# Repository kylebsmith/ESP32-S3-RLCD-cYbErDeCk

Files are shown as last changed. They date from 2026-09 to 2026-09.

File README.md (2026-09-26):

# cYbErDeCk

A single-form, overbuilt, minimum-footprint handheld terminal enclosure for the
**Waveshare ESP32-S3-RLCD-4.2** and a **Rii 518BT** mini Bluetooth keyboard.

Built for live use — musical live coding, control surfaces, and as a portable
node on a local network — rather than for a desk.

Dieter Rams read organically: one radius system, nothing applied, a single
perforated element — but with curvature continuity everywhere a surface turns,
so it reads as grown rather than extruded.



<p align="center">
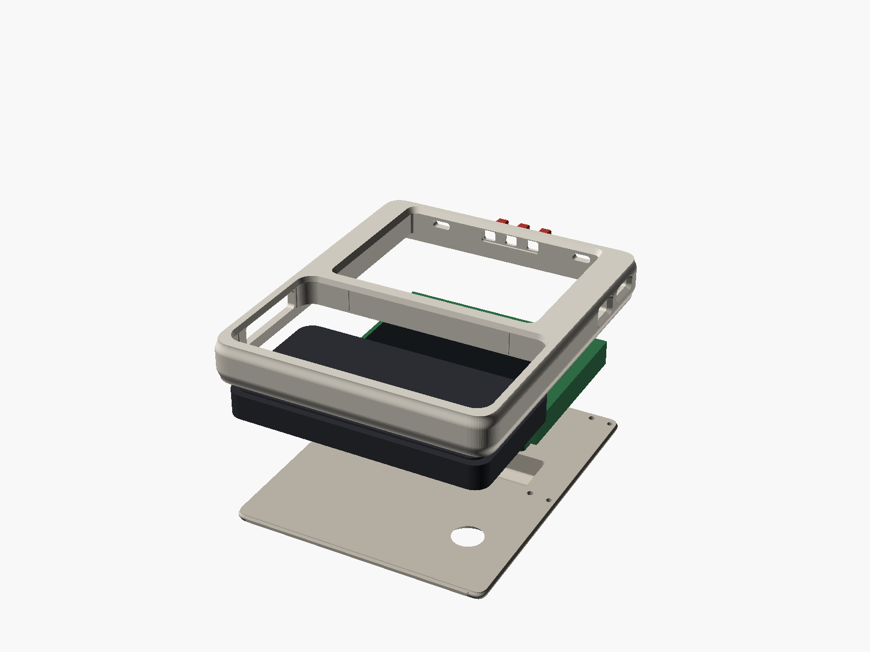
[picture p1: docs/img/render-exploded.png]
Exploded assembly
  
</p>
<p align="center">
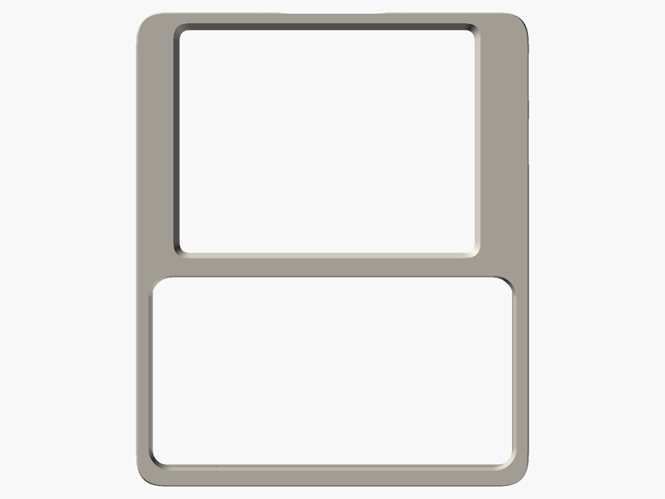
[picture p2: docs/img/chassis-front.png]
Chassis, front
  
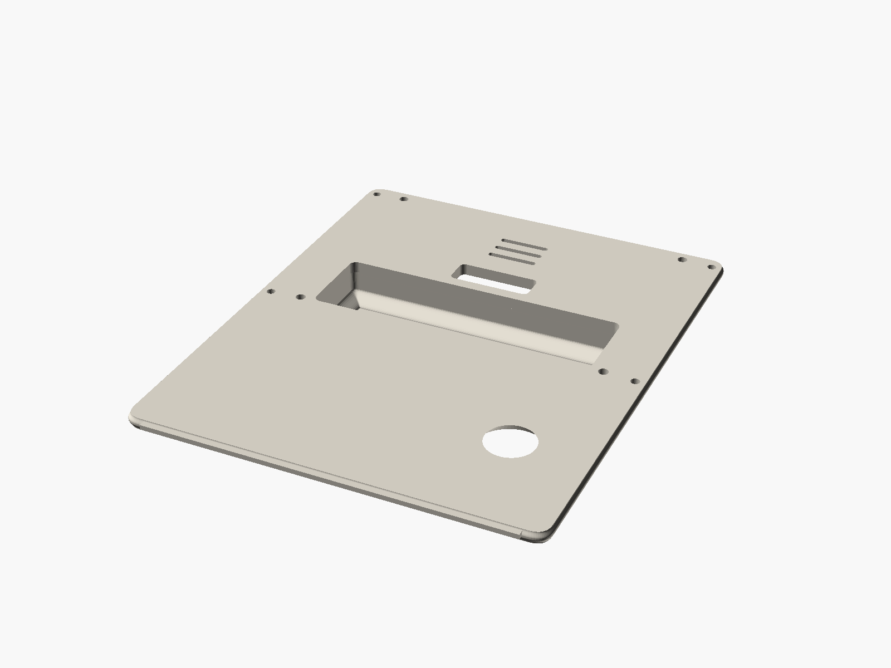
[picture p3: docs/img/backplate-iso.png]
Back plate
  
</p>

```
116.25 × 138.85 × 16.85 mm   (+ 10.0 mm battery cowl)
3 printed parts + a cover · 8 screws · 8 magnets · 119 automated checks
```

---

## What it is

Two rigid rectangles have to sit side by side, so most of the size of this thing
is arithmetic, not taste:

```
width  = wall + max(keyboard 109.85, board 93.5) + wall
height = wall + keyboard 59.15 + spine + board 70.1 + wall
depth  = back plate + board stack 11.0 + front face
```

`tools/validate.py` asserts each of those three equalities on every run. **The
enclosure cannot be made smaller without thinning a wall or crushing a part.**

What *is* a design choice is that it reads as one object, and that every corner
on it is continuous in curvature rather than merely tangent. A conventional
fillet is an arc meeting a line: the curvature jumps from 1/r to zero and the
eye reads a hard corner however large the radius. Every visible corner here is a
superelliptical quadrant of a larger corner size, tracking the same silhouette
while ramping curvature in from zero. Edges roll into the faces with zero slope
instead of being chamfered, and the battery swelling is blended out of the back
panel with a tangent foot, so it has no base line at all.

The entire front face, all four side walls and the inter-bay spine are a single
continuous body; the joint moves to the back, where a structural plate closes
the shell into a torsion box. There is no bezel line across the face you touch.

Where the language breaks it says so. The display aperture's corner is 4.2 mm
where everything else is 9 to 11.2, because the aperture height is trapped
between the active area it must not clip and the module edge it must still bear
on — the panel sets that corner, not taste, and the bound is asserted in CI.

| | Reference design | This design |
|---|---|---|
| Envelope | 151.65 × 116.77 × 18.00 | **116.25 × 138.85 × 16.85** |
| Battery bulge | +12.0 mm, separate clip-on cover | +10.0 mm, integral grip ridge |
| Wall | 2.90 mm | **3.20 mm** (8 extrusions, solid perimeters) |
| Split | bezel screwed onto a tray | monocoque front, joint at the back |
| Footprint area | 17 708 mm² | **16 218 mm² (−8.4 %)** |

12.55 mm shorter, 1.15 mm thinner, *and* thicker-walled.

## The instrument

The firmware turns the board into a handheld live-coding instrument. One line of
text is one lane, and a lane is the only noun in the system — a kick, a
bassline, a filter sweep and an ASCII frame are the same object, and what
differs is only which destination interprets it.

```
>bpm 124
>scale dmin
>kick 9...x...9...x...
>hat  x%50x%50x.x. /2
>bass 0__.3...5_..3...
>pad  [0,2,4]___[3,5,7]___
>cut 0..3..6..9..6.
>play
```

`x` is a hit and `.` a rest. A digit is **how much** — velocity on a drum, the
scale degree on a voice, the value on a controller lane. `_` holds the note before
it, `[0,2,4]` is a chord, `x%15` plays fifteen per cent of the time, `[xx]`
subdivides a step and `<a b>` alternates bars. A trailing `/2` or `*2` sets that
lane's own speed. The names are yours: the boot document defines them with lines
like `>kick = note 36`, and `>conga = note 63` adds one. Anything else is refused, with the character boxed, rather than
played. An inverted bar sweeps each line in time with the sound, lighting the whole
step that is sounding, so you can see what is playing in the document you are
editing.

Output goes to named destinations rather than a compiled-in sink, which is why
the same pattern can drive a synth and a projector without either knowing about
the other:

| | |
|---|---|
| `>usb on` | USB MIDI, measured at **0.03 ms** of jitter at the host |
| `>send ble on` | BLE MIDI, off by default — the radio is the keyboard's |
| `>osc <ip> <port>` | OSC as `/deck/<lane>`, for visuals and other machines |
| `>osc in 9000` | OSC in: `/deck/knob1` sets `>knob1 = knob`, and `>route cut knob1` follows it |
| `>frame` | the current document, as ASCII, to whatever is rendering |
| `>host deck` | the deck becomes the Wi-Fi network (it asks for a password) |
| `>ssh you@host <cmd>` | run something elsewhere, read the reply here (it asks for the password) |

There is no command mode and no menu. Commands are lines of text beginning with
`>`, in any document, run with Ctrl+Enter — so a document is a piece of music, a
notebook and a control surface at once, and the settings file is simply a
document that runs at startup.

**[docs/TESTING.md](docs/TESTING.md)** is a step-by-step pass over all of it.

Timing is measured rather than asserted. The sequencer's clock holds 99.6 % of
ticks within 100 µs of the grid; end to end over USB the standard deviation is
0.03 ms, against roughly 6 ms for an audible displacement of a percussive
onset. What is *not* measured is stated as such, here and in
[STATUS.md](STATUS.md).

## Print it

The three printable parts are committed in
**[`export/stl/`](export/stl/)** — chassis, back plate and button sprue — with
per-part orientations and print settings in
[`export/stl/README.md`](export/stl/README.md).

0.4 mm nozzle, 0.2 mm layers, no supports on any part.

> **Print the chassis alone first** and offer the board and keyboard up to it
> before committing to a full set. Nothing here has been printed yet.

## Build it

```sh
pip install -r tools/requirements.txt

openscad -D 'part="chassis"'   -o export/stl/chassis.stl   cad/cyberdeck.scad
openscad -D 'part="backplate"' -o export/stl/backplate.stl cad/cyberdeck.scad
openscad -D 'part="buttons"'   -o export/stl/buttons.stl   cad/cyberdeck.scad

python3 tools/validate.py          # 119 checks; non-zero exit if any fail
```

0.4 mm nozzle, 0.2 mm layers, no supports. Full instructions, BOM and print
orientations in **[docs/ASSEMBLY.md](docs/ASSEMBLY.md)**.

Two presets: `overbuilt` (3.2 mm walls, default) and `compact` (2.4 mm).

## How it is grounded

Every dimension is traceable to a source a third party can check. Nothing is
estimated, and nothing is traced off a picture.

- **Board geometry** comes from Waveshare's own published CAD package — Creo
  STEP assembly, dimensioned DXF, dimensioned PDF.
- **Keyboard geometry** — `108.5 × 58.2 × 10.2 mm` — comes from two independent
  manufacturer documents twelve years apart: the user manual filed as an exhibit
  under FCC ID `YIZRT-RII518`, and Riitek's current dimensioned product drawing.
  Cross-checked against three measured third-party enclosure pockets.
- **`tools/measure_reference.py`** re-derives every measured datum numerically
  from reference artefacts: planar sectioning with explicit world-preserving
  transforms, scan-line wall probing, ray-cast depth profiling, DXF group-code
  parsing.
- **`tools/validate.py`** renders the parts from source and booleans them
  against component mock-ups built from the datums. It is a gate, not a report.

The mounting-hole pattern — the datum everything else hangs off — was
established **three times independently**: from two unrelated enclosure designs
by different authors, and from the factory drawing. All three give
**85.500 × 62.100 mm**, agreeing to 0.001 mm.

Three further datums measured from a third-party enclosure *before* the factory
CAD was located matched it exactly: microphone offsets ±32.500, battery offset
−19.400, speaker grille height 10.45.

### It also corrected the internet

The figure `92.5 × 70.1 × 13.5 mm`, repeated across distributor pages for this
board, **conflates three different objects**. 92.50 is the PCB length; 70.10 is
the *removable moulded stand base*, which overhangs the PCB by exactly 1.00 mm
on one long edge (the PCB is 69.10); and 13.50 excludes the battery holder,
which protrudes a further 5.45 mm.

Discarding that stand base — removable, and not load-bearing once you notice the
standoffs are on the PCB — is what makes this deck thinner than the reference.

Similarly, the panel is not 4.2 inches (it is 4.173, exactly 84.80 × 63.60 mm),
and its active area is **not centred** on the board: it sits 1.60 mm off.

Full record, including every correction and every remaining gap, in
**[docs/DATUMS.md](docs/DATUMS.md)**.

## What is *not* proven

**Nobody has built this.** All 119 of `tools/validate.py`'s checks pass and the
structural claims are computed from the rendered meshes rather than argued, but
internal consistency is not the same as fit. It has not been printed, and the
components have not been offered up to a physical chassis.

Before committing to a full set, print the chassis alone and check the four
measurements listed in
[docs/DATUMS.md](docs/DATUMS.md#measure-these-before-a-final-print). The one to
check first is **O-04**: the factory drawing and the reference enclosure
disagree by about 2.5 mm on the height of the side buttons.

There is also no FEA and no drop testing. The stiffness argument in
[docs/DESIGN.md](docs/DESIGN.md) is reasoning from section geometry — closed box
versus open channel, joint moved out of the peak-bending plane — not simulation.

## Drawings

Four dimensioned general-arrangement sheets in [`export/drawings/`](export/drawings/),
regenerated in CI. **Every dimension on them is measured from the rendered
mesh**, not typed in and not read from `parameters.scad` — a drawing annotated
by hand drifts from the model the first time anyone edits the model; one that
measures the mesh cannot.

| Sheet | |
|---|---|
| [1 — chassis](export/drawings/sheet1-chassis.png) | front elevation, vertical section, envelope derivation with PASS/FAIL |
| [2 — back plate](export/drawings/sheet2-backplate.png) | rear elevation, section through the battery cowl |
| [3 — assembly](export/drawings/sheet3-assembly.png) | horizontal sections through both bays, **components in place**, clearances called out |
| [4 — components](export/drawings/sheet4-components.png) | schedule of every component-facing dimension with its provenance |
| [5 — structure](export/drawings/sheet5-structure.png) | section modulus along the folding axis, open vs closed |
| [6 — corner lip](export/drawings/sheet6-corner-lip.png) | why the keyboard aperture corner is circular, and what it cost when it was not |

## How robust it actually is

`tools/structure.py` computes section properties from the rendered mesh at 90
stations along the axis the device folds about — second moment of area, section
modulus, and Bredt's formula for the closed cell. Classical section analysis,
not FEA: good for **ratios and weak-point location**, silent on absolute stress.

| | reference deck | this design |
|---|---|---|
| mean second moment `I` | 9 553 mm⁴ | **20 374 mm⁴** |
| mean section modulus `Z` | 891 mm³ | **1 675 mm³** |
| worst-section `Z` | 212 mm³ | **340 mm³** |

**2.13× the mean bending stiffness and 1.60× at the worst section, in a smaller
envelope.** Fitting the back plate is worth 3.26× on its own. Putting the joint
at the back rather than across the face puts it 0.45 mm from the neutral axis
instead of 14.10 mm, so it carries about **97 % less bending stress**.

It also corrected one of this project's own claims. The shell was described as a
closed torsion box; it is one over **12 % of its length**. Everywhere else the
front face is absent — that is what an aperture is — and the section is a U
closed only by the back plate. The deck is two open channels joined by one short
closed cell at the spine, and that cell is worth 13× in torsion. The spine is
not merely a shear web, it is the only closed cell in the device.

The weak point is named rather than hidden: **mid-keyboard-bay, `Z` = 340 mm³**,
because the keyboard aperture is 106.5 mm across a 116.85 mm body and leaves
about 5 mm of face each side. Nothing can be added there without covering keys.
The reference is weakest in the same place for the same reason. If this deck
fails in a drop, that is where.

## Accuracy against the original

`tools/audit_reference.py` compares every surface that locates, retains or gives
access to a component against the reference design this project measured — the
one that is known to work. It is a gate, not a report: anything that differs
without a recorded reason exits non-zero.

```
19 match   15 intended difference   0 to review
```

Exact agreement (±0.000 mm) on the mounting pattern, the display aperture, the
button pitch and apertures, the microphone span and apertures, and the speaker
grille field. On the keyboard specifically: the front aperture matches to
**0.002 mm**, the pocket corner to 0.064, and the eject port to 0.010.

The fifteen differences are each a recorded decision — the board pocket cut to
the bare PCB rather than to the discarded stand base, the keyboard pocket sized
to clear the body at its assumed tolerance rather than to one author's sample,
3.2 mm walls instead of 2.9.

**What is audited, and what is not.** Eleven keyboard-facing dimensions are
re-derived from the reference meshes on every run. The keyboard's service window
is not — it is measured once and recorded, because the tray is open at that edge
and the notch could not be isolated reliably from the surrounding opening. It is
listed in [DATUMS.md](docs/DATUMS.md) as measured-once rather than quietly
counted among the audited rows.

## Documentation

| | |
|---|---|
| **[DATUMS.md](docs/DATUMS.md)** | every dimension, its provenance, forty-nine recorded corrections, nine open items |
| **[HARDWARE.md](docs/HARDWARE.md)** | the board itself: panel, controller, pin map, USB and power, all traced to vendor sources |
| **[SUBSTRATE.md](docs/SUBSTRATE.md)** | the conceptual core: one data structure, one noun, three verbs |
| **[CASE.md](docs/CASE.md)** | the carry case: how it guides, holds and prints |
| **[CONCRETE.md](docs/CONCRETE.md)** | the cast concrete jacket, its mould, and the mix |
| **[HANDOFF.md](HANDOFF.md)** | briefing for a session with the hardware in front of it |
| **[OS.md](docs/OS.md)** | the firmware design: what it runs, why, and what it deliberately will not do |
| **[THESIS.md](docs/THESIS.md)** | the running note for the paper: each decision made for legibility, as it was made |
| **[DESIGN.md](docs/DESIGN.md)** | form language, why it is shaped this way, material and finish |
| **[METHODOLOGY.md](docs/METHODOLOGY.md)** | how the numbers were obtained and how to reproduce them |
| **[MEASURE.md](docs/MEASURE.md)** | caliper checklist for someone holding the actual hardware |
| **[ASSEMBLY.md](docs/ASSEMBLY.md)** | BOM, print settings, build order |
| **[PROVENANCE.md](docs/PROVENANCE.md)** | what was taken from whom, and on what basis |

## Tooling

| | |
|---|---|
| `tools/params.py` | the single reader for `parameters.scad`; every other tool goes through it |
| `tools/measure_reference.py` | metrology harness — regenerates every measured datum |
| `tools/validate.py` | 119-check design audit — the build gate |
| `tools/audit_reference.py` | component-facing accuracy against the reference |
| `tools/test_primitives.py` | unit tests for the geometry helpers; catches a primitive that lies |
| `tools/structure.py` | section properties from the mesh; stiffness against the reference |
| `tools/drawing.py` | dimensioned GA sheets, measured from the mesh |
| `tools/render.sh` | every published view, with its camera stated in the script |
| `tools/check_golden.py` | proves v1 still reproduces exactly, parameter-for-parameter |
| `tools/check_docs.py` | proves the documentation still says true things about itself |
| `tools/fetch_reference.sh` | rebuilds `reference/` from vendor URLs; nothing vendored |
| `tools/build.sh` | render everything and gate; what CI runs |

## Repository layout

```
cad/
  parameters.scad     single source of truth — every dimension, tagged and cited
  cyberdeck.scad      chassis, back plate, button sprue
  lib/util.scad       geometry helpers
  lib/components.scad worst-case component envelopes, for fit checking
tools/
  params.py             the single reader for parameters.scad
  measure_reference.py  metrology harness — regenerates every measured datum
  validate.py           119-check design audit — the build gate
  audit_reference.py    component-facing accuracy against the reference
  test_primitives.py    unit tests for the geometry helpers
  structure.py          section properties, stiffness, weak-point location
  drawing.py            dimensioned GA sheets, measured from the mesh
  render.sh             every published view, cameras stated in the script
docs/                 datum sheet, design rationale, methodology, assembly
export/reports/       machine-readable measurement and validation output
```

`cad/parameters.scad` is the only place a number may appear. A bare dimension
anywhere else in the CAD is a bug.

## Credits

This design measures, but does not copy,
**[nilseuropa/solar_term](https://github.com/nilseuropa/solar_term)** — the
SolarTerm enclosure and the [SolarOS](https://github.com/nilseuropa/solar_os)
project it houses. Their work is what got these two components living together
in the first place, and because their deck is a built, working device, its
pockets serve as hard physical bounds on components whose vendors round their
own figures.

No geometry from that project is used here, and it carries no licence of its
own. See [PROVENANCE.md](docs/PROVENANCE.md).

Board CAD published by [Waveshare](https://docs.waveshare.com/ESP32-S3-RLCD-4.2).

## Licence

[MIT](LICENSE) for the original contents of this repository. The dimensional
values are measurements of third-party products; they are facts, and are not
claimed as property.

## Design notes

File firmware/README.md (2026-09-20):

# cYbErDeCk OS — firmware

Steps 1–4 of the build order in [../docs/OS.md](../docs/OS.md): display, text
grid, BLE HID keyboard, and a text buffer that survives power loss.

## Build and flash

Flashing is button-free — the ESP32-S3's USB-Serial/JTAG enters download mode
over the USB control lines, so nobody has to hold BOOT.

```sh
. ~/esp/esp-idf/export.sh
cd firmware
idf.py -p /dev/cu.usbmodem2141101 flash monitor      # macOS
idf.py -p /dev/ttyACM0            flash monitor      # Linux
```

If it ever fails to enter the bootloader, add `--before default_reset` to a
direct `esptool` invocation. Exit the monitor with `Ctrl-]`.

## Layout

| Path | What |
|---|---|
| `components/st7305` | the panel driver: framebuffer, window addressing, HPM/LPM, orientation |
| `components/textgrid` | the character grid, the two bitmap faces, per-cell damage |
| `components/kbd` | NimBLE HOGP keyboard host, bonds, key repeat |
| `components/docstore` | gap buffer, the power-safe flash journal, the SD mirror |
| `main` | boot, the editor, the test card, the persistence self-test |

`components/st7305` is derived from SolarOS under Apache-2.0 — see [NOTICE](NOTICE).

## The two grids

Cell **height** must be a multiple of 12 because that is the CASET quantum in
landscape; cell **width** only has to be even, because the RASET quantum is
2 px. That asymmetry is the design freedom: width is cheap, height comes in 12s.

| Face | Cell | Grid | Use |
|---|---|---|---|
| `tg_font_12x24` | 12 × 24 | **33 × 12** | the default — a reflective panel with no backlight needs the weight |
| `tg_font_6x12` | 6 × 12 | 66 × 25 | dense work; too small to read comfortably on the real panel |

Switch with `tg_set_font(&tg_font_6x12, 1)`. The call refuses a misaligned
cell rather than letting one line's damage window spill into its neighbours.

Both faces are generated from reviewable ASCII art:

```sh
python3 tools/make_font.py          > firmware/components/textgrid/font6x12.c
python3 tools/make_font.py --12x24  > firmware/components/textgrid/font12x24.c
```

## Buttons

| Gesture | Effect |
|---|---|
| KEY (GPIO18) tap | cycle the display orientation, saved to NVS |
| KEY held 2 s | forget every keyboard bond and rescan |

The orientation cycle exists because the landscape mapping has a two-way
ambiguity per axis that depends on how the glass sits in the module, and no
datasheet settles it. A wrong guess costs a button press, not a reflash.

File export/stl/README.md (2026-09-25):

# Printable parts

Regenerated from source by `./tools/build.sh`. **Do not edit these by hand** —
every dimension in them comes from `cad/parameters.scad`, and a hand-edited STL
silently detaches from the datum set and from all 118 checks.

| File | Size (mm) | Volume | ~PLA | Notes |
|---|---|---|---|---|
| `case/carrycase-front.stl` | 150.82 × 176.29 × 16.00 | 158 cm³ | ~190 g | print **face down**; holds the four magnets; 13.00 of body + 3.00 of locating pin |
| `case/carrycase-back.stl` | 151.63 × 177.07 × 24.45 | 306 cm³ | ~245 g | print **back down**; takes the seven heat-set inserts |

They bolt together with **7 × M5 × 16 socket cap into 7 × M5 × 10 heat-set
inserts**, in a ring that outsets the deck cavity by 6.50 mm and so follows the
case's own superellipse round the flanks and the floor. The heads lie flush: a
Ø9.00 × 5.00 counterbore under an r11.00 dish cut 1.00 mm into the face.

Each needs a **154 × 179 mm** bed. Both are one watertight body with **0 mm² of
near-flat ceiling**. The two overhangs either has are both deliberate: the
1.80 mm annular roof of each counterbore, all seven opening on the bed, and the
rim facet at **55–61° off horizontal**, which is 10° clear of the limit at
worst.

An earlier one-piece `case/carrycase.stl` is gone: it could not be reached into
to fit the magnets, and its spined back needed support. See
[DATUMS.md C-41](../../docs/DATUMS.md#corrections).

There is no separate window or screen protector: the display sits 2.65 mm
below the outer face behind a 2.4 mm front panel, and that recess is the
protection. An earlier revision exported a `window.stl` copied from the
reference's acrylic template; it was 0.72 mm larger than this design's board
pocket in both axes and had no seat anywhere, so it could not be fitted. See
[DATUMS.md C-09](../../docs/DATUMS.md#corrections).

All three are watertight, single-body manifolds — asserted on every run by the
`MESH` class in `tools/validate.py`.

## Printing

0.4 mm nozzle, 0.2 mm layers, **no supports on any part**.

Wall thicknesses are integer multiples of the nozzle width so every wall prints
as solid perimeters with no sparse infill in the load path. **Do not reduce the
perimeter count** — that is where the strength is.

| Part | Orientation | Why |
|---|---|---|
| chassis | front face on the bed | the aperture draft prints as a chamfer rather than a bridge, and the visible face gets the bed finish |
| backplate | flat face on the bed, cowl upward | the cowl's sides are vertical and its cap is a dome, so it needs no support; the countersinks face the bed and print clean |
| buttons | caps down | — |

Full build order, BOM and fastener spec in [docs/ASSEMBLY.md](../../docs/ASSEMBLY.md).

## Before you print a full set

**Nothing here has been printed or fitted to hardware.** It is asserted
internally consistent and confirmed against a working reference design, which
is not the same thing.

Print the **chassis alone** first and offer the board and keyboard up to it. The
measurement to take first is the **keyboard's thickness**: the pocket is 11.0 mm
deep and sits exactly on its assertion against a 10.6 mm upper band, and the
manufacturer's drawing never says whether its stated 10.2 mm includes the
keycaps. That is the only axis in the design with no slack left.

See [docs/DATUMS.md](../../docs/DATUMS.md#measure-these-before-a-final-print).

## Regenerating

```sh
pip install -r tools/requirements.txt
./tools/build.sh            # renders every part, then runs all 71 checks
```

The build is deterministic: a clean run reproduces these files byte for byte.
If they show as modified afterwards, the geometry actually moved — that is a
signal, not noise.

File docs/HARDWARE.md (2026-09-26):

# Hardware reference — Waveshare ESP32-S3-RLCD-4.2

Every number here is traced to a primary source. Nothing is remembered,
inferred from a product photo, or carried over from a similar board.

`reference/` is **gitignored on purpose**: `docs/PROVENANCE.md` states that no
Waveshare file is redistributed by this repository. Rebuild the mirror with

```sh
tools/fetch_reference.sh          # docs + datasheets, ~12 MB
tools/fetch_reference.sh --code   # also the example repos, ~900 MB
```

## Sources

| ID | Source | Retrieved |
|----|---|---|
| H1 | `docs.waveshare.com/ESP32-S3-RLCD-4.2` → `reference/waveshare/_docs.html` | 2026-09-20 |
| H2 | `…/Resources-And-Documents` — vendor resource index | 2026-09-20 |
| H3 | `files.waveshare.com/wiki/common/ST_7305_V0_2.pdf` — Sitronix ST7305 v0.2, 2021/04, 112 pp | 2026-09-20 |
| H4 | `files.waveshare.com/wiki/ESP32-S3-RLCD-4.2/ESP32-S3-RLCD-4.2-schematic.pdf` | 2026-09-20 |
| H5 | `github.com/waveshareteam/ESP32-S3-RLCD-4.2` — vendor example code | 2026-09-20 |
| H6 | H5 → `02_Example/XiaoZhi/XiaoZhiCode_V2.1.0/main/boards/waveshare-s3-rlcd-4.2/config.h` | 2026-09-20 |
| H7 | H5 → `02_Example/ESP-IDF/11_U8G2_Test/components/port_bsp/display_bsp.{h,cpp}` | 2026-09-20 |
| H8 | `documentation.espressif.com/esp32-s3_datasheet_en.pdf` — Espressif ESP32-S3 datasheet | 2026-09-20 |
| H9 | `github.com/nilseuropa/solar_os` v4.12.2 → `src/drivers/rlcd_st7305.c` — a working ST7305 driver for this exact panel, Apache-2.0 | 2026-09-20 |

Tags: `[VENDOR]` vendor states it · `[CODE]` read from vendor source ·
`[DERIVED]` computed here from tagged values · `[OPEN]` not yet established.

## SoC and memory

| Item | Value | Source |
|---|---|---|
| Module | ESP32-S3-WROOM-1-N16R8 | `[VENDOR]` H1 |
| Core | Xtensa LX7 dual-core, ≤240 MHz | `[VENDOR]` H1 |
| SRAM | 512 KB | `[VENDOR]` H1 |
| ROM | 384 KB | `[VENDOR]` H1 |
| Flash | 16 MB | `[VENDOR]` H1 |
| PSRAM | 8 MB (octal) | `[VENDOR]` H1 |
| Radio | Wi-Fi 2.4 GHz + **Bluetooth 5 (LE)** | `[VENDOR]` H1 |

**Bluetooth is LE only.** The ESP32-S3 has no Bluetooth Classic radio, so
there is no BR/EDR HID host. The Rii 518BT pairs over **BLE HID (HOGP)** —
confirmed by the user against their own unit, which enumerates a Nordic nRF5
device exposing the Human Interface Device service.

There is no MMU with demand paging, so no Linux. The OS is a task-scheduled
firmware on FreeRTOS, not a process-isolated kernel.

## Display — the part that decides the OS

| Item | Value | Source |
|---|---|---|
| Panel | 4.2" reflective LCD (RLCD), **no backlight** | `[VENDOR]` H1 |
| Controller | **Sitronix ST7305** | `[VENDOR]` H2 |
| Resolution | 400 × 300 landscape (300 × 400 portrait) | `[VENDOR]` H1, `[CODE]` H6 |
| Colour depth | 1 bit per pixel, bi-level | `[VENDOR]` H3 §Features |
| Controller RAM | 264 × 320 × 1 b static | `[VENDOR]` H3 §7.3.1 |
| Driver outputs | S1–S264 source, G1–G322 gate | `[VENDOR]` H3 §Pin list |
| Interface | 4-wire SPI on SPI3_HOST @ **20 MHz** | `[CODE]` H7 |
| Frame rate range | **0.25 Hz – 51 Hz** | `[VENDOR]` H3 §Features |
| HPM frame rate | **32 Hz** (`FRCTRL` B2h = 0x12) | `[VENDOR]` H3 §8.2.3 |
| LPM frame rate | **1 Hz** (same register) | `[VENDOR]` H3 §8.2.3 |
| Power-mode commands | `HPM` 38h / `LPM` 39h | `[VENDOR]` H3 §8.1.22–23 |
| Partial mode | `PTLON` 12h (240 duty) / `PTLOFF` 13h (320 duty) | `[VENDOR]` H3 §8.1.8–9 |
| Window addressing | `CASET` 2Ah / `RASET` 2Bh | `[VENDOR]` H3 §8.1.14–15 |
| Tearing-effect output | present, wired to GPIO6 | `[CODE]` H6 |
| Framebuffer | 400 × 300 ÷ 8 = **15,000 bytes** | `[DERIVED]` from H7 `DisplayLen = transfer >> 3` |
| Vendor ships | HPM, full-frame pushes, buffer in PSRAM | `[CODE]` H7 |

### Memory layout: one byte is a 4 × 2 pixel block

From H7's pixel addressing — `byte_x = x >> 2`, `byte_y = y >> 1`,
`local_x = x & 3`, `local_y = y & 1`:

```
one RAM byte  =  4 pixels wide  ×  2 pixels tall
framebuffer   =  100 byte-columns  ×  150 byte-rows  =  15,000 bytes
```

This is the single most consequential fact for the UI. It means the natural
unit of damage is a 4 × 2 block, and a character cell whose width is a
multiple of 4 and whose height is a multiple of 2 maps onto **whole bytes with
no read-modify-write**.

### Timing budget `[DERIVED]`

| Quantity | Value |
|---|---|
| Full-frame SPI push, 15,000 B @ 20 MHz | **6.0 ms** |
| One HPM frame period @ 32 Hz | 31.25 ms |
| SPI push as a fraction of an HPM frame | **19 %** |
| One LPM frame period @ 1 Hz | 1000 ms |

**The bus is not the bottleneck — the panel is.** A whole-screen redraw costs
6 ms against a 31 ms frame, so a live text editor at 32 Hz is comfortable
without any partial-update machinery. Window addressing (`CASET`/`RASET`) is
therefore a **power and CPU optimisation, not a latency requirement** — which
is the opposite of the constraint an e-paper panel would impose, and it is why
this panel suits an interactive writing device where e-paper does not.

`LPM` at 1 Hz with a reflective, backlight-free panel is what makes
"never really off" real: the image persists, costs almost nothing to hold, and
returns to 32 Hz on a keypress via a single command byte.

### Character-cell geometry `[DERIVED]`

**The quantisation rotates with the panel, and this was got wrong at first.**
The byte is 4 × 2 pixels *in the panel's own portrait frame*, but the device
runs **landscape** (settled by `docs/DATUMS.md` D-07: only 400 × 300 gives
square 0.2120 mm pixels against the enclosure's active area). Rotated:

| Landscape axis | Maps to | Addressing unit | **Quantum** |
|---|---|---|---|
| width, 400 px | native Y | `RASET` row address | **2 px** |
| height, 300 px | native X | `CASET` column address | **12 px** |

So **12 px is the hardware's own line height** — one full-width text line of
12 px is exactly one column address across all 200 row addresses. Character
width wants to be even; height wants to be a multiple of 12.

A window of *C* column addresses × *R* row addresses costs `C × R × 3` bytes:

| Cell | Grid | h % 12 | w % 2 | Bytes/char | @ 20 MHz |
|---|---|---|---|---|---|
| **6 × 12** | **66 × 25** | yes | yes | **9** | 3.6 µs |
| 8 × 12 | 50 × 25 | yes | yes | 12 | 4.8 µs |
| 12 × 12 | 33 × 25 | yes | yes | 18 | 7.2 µs |
| 5 × 10 | 80 × 30 | **no** | **no** | 24 | 9.6 µs |

**`6 × 12` giving `66 × 25` is the recommendation.** It is aligned on both
axes, it is the cheapest per character, and 66 columns is close to the
classical measure for prose. `8 × 12` at `50 × 25` is the roomier alternative
and equally well aligned.

An 80-column mode is now clearly the wrong trade: `5 × 10` is misaligned on
*both* axes, costs the most per character of any option here, and at 120 DPI a
1.06 mm cell is legible but unpleasant. **Plan the UI for 66 × 25.**

| Update | Bytes | @ 20 MHz |
|---|---|---|
| One character (6 × 12) | 9 | 3.6 µs |
| One full-width 12 px line | 600 | 240 µs |
| Full frame | 15,000 | 6.0 ms |

### Measured on the bench, 2026-09-20 `[MEASURED]`

First numbers taken from the real board rather than derived. Method:
`esp_timer_get_time()` either side of a 20-run loop, ESP-IDF v5.5.4, SPI3
unused and SPI2 driving the panel at 24 MHz.

| Quantity | Derived above | **Measured** |
|---|---|---|
| Full-frame push, 15,000 B | 6.0 ms @ 20 MHz (5.0 @ 24) | **4.75 ms @ 24 MHz** |
| One 6 x 12 character, bytes on the wire | 9 | **9** |
| One 12 x 24 character, bytes on the wire | 36 | **36** |

The two byte counts are the load-bearing result. They are produced by the
window arithmetic in *Window addressing* below, running against a real
controller, at two different cell sizes — which corroborates the address model
by a route independent of the driver it was read from. Had the CASET mirroring
been wrong, a narrow window would not have come out at exactly 9 and 36 bytes.

The full-frame figure beats the derivation because the derivation assumed no
overlap between SPI setup and transfer. Per-character wall time is ~390 us
against 3.6 us of wire time, so the **cost of a keystroke is transaction
overhead, not bandwidth** — which is where to look if latency ever matters.

**Still unmeasured: everything optical.** Nobody has photographed the panel
under this firmware. Contrast, the LC response ceiling and whether the image
is even the right way round are open below.

### The drawing was the budget, not the push `[MEASURED]`

*2026-09-25. `docs/NEXT.md` §9 expected the opposite - "the panel push is almost
certainly the budget, not the drawing" - and said to profile first. The profile
disagreed.*

`bench_render()` in `firmware/main/main.c` draws a full grid of mixed glyphs, a third
of them inverted, into the framebuffer with the scheduler held, by both paths in
the same boot, and prints both at every boot:

| One 12 x 24 cell into the framebuffer | **Measured** |
|---|---|
| Per-row path: 24 row blits, a read-modify-write per pixel | **86.3 us** |
| Pre-turned face, three attribute masks | 5.8 us |
| **Pre-turned face, one mask per attribute combination** | **3.8 us** |
| of which damage bookkeeping (`st7305_damage`) | 0.67 us |
| First frame after a layout or orientation change, turning 124 glyphs | 9.8 ms |

So a full 33 x 12 grid cost **34 ms to draw against 4.75 ms to push** - seven times
the push - and now costs 1.5 ms. The editor's heartbeat, which times by the wall
clock and so counts preemption, said 94 us a cell before; with five picture lanes,
`echo` and `move` running and the view streaming, it says **4.3 us**.

**Why it works.** A framebuffer byte is 4 native-x by 2 native-y pixels, and
`tg_set_layout` already holds cells and origins to multiples of 12 and 2. So every
cell is whole bytes in every orientation - 6 rows of 6 for 12 x 24, 3 of 3 for
6 x 12 - and where a pixel lands inside its cell's bytes does not depend on where
the cell is. Each glyph is turned into its 36 bytes once, the first time it is drawn
in an orientation; a cell is then 36 XORed stores. The eight attribute masks are the
per-row path's own output XORed against itself, not a second description of where a
bar is. `tools/test_textgrid.c` compiles `textgrid.c` and demands identical
framebuffers from both paths for every glyph, attribute, face and orientation, and
shows it can tell a stale orientation and one wrong bit apart. Cost: 4.8 KB of
internal RAM.

**The editor loop, profiled by stage** (`loop:` in the heartbeat, microseconds of
wall clock in 10 s, the heaviest scene above):

| | pictures | view out | draw | push | turns a second |
|---|---|---|---|---|---|
| idle | 3 ms | - | - | - | 199 |
| heavy scene, before the view fix | 52 ms | **2,570 ms** | 117 ms | 189 ms | 142 |
| heavy scene, after | 52 ms | 40 ms | 150 ms | 189 ms | 192 |

The second budget the profile found was the view's console output, 31 ms a frame -
`docs/VIEW.md` has it. With both fixed, **the push is now the largest term**, as the
brief expected: the brief was right about where the budget should be, and wrong
about where it was. Under the heaviest scene the editor loop is busy about 4 per cent
of the time. Draw rose from 117 to 150 ms when the view stopped blocking - most
likely the USB interrupts that used to land inside the 31 ms wait now landing inside
everything else. That explanation is unverified.

**Not done, on the same numbers.** §9 also lists a table for the tone ramp and the
Bayer dither, and hoisting the fields' row terms out of their inner loops. Under the
heaviest scene the pictures cost 52 ms in 10 s - about 0.6 ms a frame for seven
lanes over 1,060 cells - so neither can buy a number anyone would notice, and the
rule cuts both ways: no optimization without a number, and none where the number
says it cannot matter. The push is the term to watch now, and at about 2.3 ms for
6.5 KB it is already close to its wire time.

### The 6 x 12 recommendation did not survive contact `[MEASURED]`

*Character-cell geometry* above recommends 6 x 12 giving 66 x 25, on the
grounds that it is aligned on both axes and cheapest per character. Both facts
hold. The recommendation still failed, for a reason arithmetic could not
reach: on the real panel, at 0.212 mm pixel pitch and with no backlight, a
5 x 7 glyph body is too small and too thin to read comfortably. The owner's
first look at it was "the text is too small ... with such a naturally low
contrast screen we gotta have sexy chunky letters."

The firmware therefore defaults to **12 x 24 giving 33 x 12**, and keeps 6 x 12
available. The alignment analysis is what made the swap free: cell height must
be a multiple of 12, but **cell width only has to be even**, so widths are
cheap and the grid can be re-proportioned without new constraints.

### Refresh: three different numbers, and only two govern how it feels `[OPEN]`

This is the sharpest unresolved question in the prior art and it must not be
collapsed into one figure:

1. **SPI write throughput** — fast. 6.0 ms a frame at 20 MHz, 5.0 at 24 MHz,
   and the datasheet's 30 ns `tSCYC` allows 33 MHz. Not the limit.
2. **Liquid-crystal optical response** — an NES emulator written for this exact
   panel reports it staying clean only to about **23 Hz**, with blacks washing
   out above roughly 26 Hz. If that holds, it, not bandwidth, is the real
   ceiling, and the earlier "32 Hz is comfortable" reading is optimistic.
3. **Self-refresh rate** — HPM or LPM, independent of how fast content is
   written.

**Writing while the panel is in LPM can delay the visible update by up to one
refresh period — about a second at 1 Hz.** That is the lag Freewrite owners
complain about, and it is a design rule rather than a defect: **kick to HPM on
the first keydown and drop back after an idle timeout.** Prior art defaults to
HPM and makes the automatic behaviour opt-in, which is the wrong default for a
battery device.

Unmeasured here. Bench it before believing any of it.

### Driver constraints worth knowing before writing code

- **The framebuffer belongs in internal DMA SRAM, not PSRAM.** SPI DMA
  requires internal SRAM; PSRAM would need cache-coherence work. 15 KB is
  affordable. Scrollback and document buffers go in PSRAM.
- **SPI reads are 5× slower than writes** — `tSCYC` 30 ns write against 150 ns
  read, so ~6.7 MHz for any read path. A driver that reads controller RAM or
  status at the write clock will fail intermittently.
- **`ST7305` vs `ST7306`.** Waveshare says ST7305 three independent ways, but
  Zephyr's in-tree board definition for this same board declares
  `sitronix,st7306`. The command sets overlap enough that the ST7306 driver
  works. Trust ST7305 for datasheet lookups; a driver labelled ST7306 may still
  be the right code.
- **No backlight, and no net to add one to.** The 23-pin LCD FPC carries only
  GND, VCC3V3, SCL, SDA, CS, RS, TE and RESET — grepping the schematic for
  backlight, `LEDA`, `LEDK` or frontlight returns nothing. Contrast improves in
  direct sunlight, which is the compensating virtue, but any front light is a
  board revision driven from a spare GPIO, not an FPC pin.

## Window addressing — the datasheet contradiction, resolved `[CODE]` H9

`docs/DATUMS.md`-style caveat first: this comes from a **third-party
implementation**, not from Sitronix. It is recorded as `[CODE]` rather than
`[VENDOR]` because H3 §7.4 states something different. It is trusted because
it is exercised on this exact panel, it reproduces the byte count derived
independently here, and its bit packing agrees with a second unrelated
implementation.

### The address model

| Unit | Mapping | Range |
|---|---|---|
| Column address (`CASET` 2Ah) | **1 address = 12 native-X pixels = 3 bytes** | `0x12` … `0x2A` (25 × 12 = 300) |
| Row address (`RASET` 2Bh) | **1 address = 2 native-Y lines** | `0x00` … `0xC7` (200 × 2 = 400) |
| One RAM byte | 4 X pixels × 2 Y pixels | — |

Derived: `controller_row_bytes = ((300 + 11) / 12) × 3 = 75`, and
`75 × 4 × 50 = 15,000 bytes` — the same framebuffer size derived above from
Waveshare's own code, by a completely different route.

### The rule the datasheet does not give you

`address_mirror_base = address_start + address_end = 0x12 + 0x2A = `**`0x3C`**.
For a window spanning natural left-to-right column addresses `[a, b]`:

```
CASET (0x2A)  =  { 0x3C - b ,  0x3C - a }      <-- reversed and mirrored
RASET (0x2B)  =  { first_y / 2 , last_y / 2 }  <-- window must be 2-line aligned
```

then stream the data in normal left-to-right order from the leftmost group.
With `MADCTL (0x36) = 0x48`, the column pointer **decrements from the CASET end
address**, so the first byte written lands at the *high* address.

**Why nobody finds this.** At full width `a = 0x12, b = 0x2A`, so
`{0x3C − 0x2A, 0x3C − 0x12} = {0x12, 0x2A}` — the mirroring is an **identity**.
Every full-frame driver, Waveshare's own included, is therefore silently
correct and never discovers the rule. It only bites once a window narrows: to
write the leftmost 12 px alone you must send `CASET = {0x2A, 0x2A}`, **not**
`{0x12, 0x12}`.

Windows are quantised — X snaps out to 12-pixel boundaries, Y to 2 lines.

### What this buys `[DERIVED]`

A window of *C* column addresses × *R* row addresses costs `C × R × 3` bytes.
Worked through in the **landscape** frame the device actually uses — see
*Character-cell geometry* above, where the axes and their quanta are set out:

| Update | Bytes | Wire time @ 20 MHz | vs. full frame |
|---|---|---|---|
| One 6 × 12 character | **9** | 3.6 µs | 1/1667 |
| One full-width 12 px line | 600 | 240 µs | 1/25 |
| Full frame | 15,000 | 6.0 ms | — |

Three orders of magnitude for the common case of typing a character. The
earlier conclusion stands and strengthens: full-frame pushes were already fast
enough for a comfortable editor, so this buys **battery life, not latency**.

### Frame-rate control `[CODE]` H9

Not obvious from H3, and worth having:

| Mode | Rates | How |
|---|---|-----|
| HPM | 16 / 25.5 / 32 / 51 Hz | `OSCSET` (`0xD8`) byte 0 = `0xA6` or `0x80`, plus the HFRA bit `0x10` in `0xB2` |
| LPM | 0.25 / 0.5 / 1 / 2 / 4 / 8 Hz | low 3 bits (`0x07`) of `0xB2` |

H9 drives the panel at **24 MHz** SPI rather than the 20 MHz in Waveshare's
example, so 24 MHz is known-good on this hardware.

### Still unsolved: tearing `[OPEN]`

H9 declares the TE pin (GPIO6) in its board manifest and **never reads it** —
no tear-free synchronisation exists anywhere in the prior art examined. Anyone
wanting glitch-free updates during HPM is on their own.

## Prior art on this exact board `[VENDOR]` H2

Waveshare's own resource page lists community projects. Two are directly
relevant and are mirrored under `reference/waveshare/code/`:

- **SolarOS** — `github.com/nilseuropa/solar_os`, posted to r/cyberDeck; and
  **solar_term**, "build instructions for a SolarOS pocket terminal". This is
  the closest existing thing to what this project is building, on identical
  hardware.
- **waveshare_RLCD_400x300_monochrome** — `github.com/JasonHEngineering/…`,
  a monochrome driver for this panel.

Also listed: an LVGL port, an ESPHome/XiaoZhi integration, a TRMNL dashboard
client, and an offline GPS. The board is well-trodden; none of these is a
keyboard-first writing device.

## Open questions `[OPEN]`

1. **Controller RAM vs. panel size.** H3 states 264 × 320 × 1 b = 84,480 bits
   of display RAM against a panel needing 120,000, and its §7.4 address range
   (X = 19…40, Y = 0…159) disagrees with the `CASET` values every working
   driver writes. The datasheet is v0.2 and parts of §7.4 read as boilerplate
   from a smaller part. **The practical mapping is now resolved** — see
   *Window addressing* above — so this no longer gates partial update. What
   remains open is only the reconciliation with H3's stated RAM figure, which
   is a curiosity rather than a blocker.
2. **Measured current** in HPM vs LPM vs sleep is not given in H3 and has not
   been measured on the bench. The power argument for LPM is currently
   qualitative.
3. **Can the ETA6098 boost VBUS?** Its SW / PMID pins and the 2.2 µH inductor
   are the topology of a part that *may* support an OTG boost, but the ETA6098
   datasheet has not been read and the CC resistors configure the port as a
   sink regardless. Only matters if USB host is ever wanted; it is not wanted
   today. **Do not assume either answer.**
4. **Schematic net names** have not been fully cross-read against the pin map above;
   the pin map rests on vendor example code, which is strong but secondary.

## MIDI on a wire `[OPEN]`

The firmware is done and measured: `>din 17` starts a UART at 31250 baud 8N1 and
`>din` reports bytes actually written — **80 bytes from a four-step kick pattern,
verified on the bench.** What is not done is the electrical side, and it cannot
be done in firmware, because **a MIDI output is a current loop, not a logic
level.** A GPIO wired straight to a jack will drive some receivers and not
others, and the ones it fails on will look like a firmware fault.

The 1983 circuit, from 5 V logic:

```
    +5V ----[220R]---- DIN pin 4
    UART TX ---[220R]---- DIN pin 5
    GND ----------------- DIN pin 2   (shield, often left open at the source)
```

From **3.3 V** logic the resistors change, because the receiver's optocoupler
wants ~5 mA:

```
    3V3 ----[33R]----- pin 4
    TX  ----[10R]----- pin 5
```

Better, and what to do if the receiver is fussy: buffer TX up to 5 V first (a
74HCT family gate, or any 3.3→5 V level shifter) and then use the original 220R
pair. The optocoupler in the receiver is the thing being driven, and it was
specified against 5 V.

**TRS instead of DIN.** Type A is the standard that won — MIDI 1.0 ratified it,
and it is what an SP404 MkII and most modern gear use:

```
    tip    = DIN pin 5   (the data line)
    ring   = DIN pin 4   (the +V side of the loop)
    sleeve = DIN pin 2   (ground)
```

Type B swaps tip and ring. If a device does not respond, that is the first thing
to try, and it cannot damage anything.

**The pin is the owner's to declare.** `>din 17` — the same rule as the battery
sense line, for the same reason: a pin is a fact about a physical object, and
the only party who can see the object is the owner. GPIO 5, 11, 12, 18, 40 and
41 are refused by name, because they are the panel and the KEY button and taking
one would look like a MIDI fault.

**What this unlocks, and it is the point.** Every other transport makes the deck
a USB device, a BLE peripheral or a network client — all of which need something
else to be the host. An SP404, a class-compliant MIDI interface and most desktop
gear are USB *devices* too, and two devices cannot talk; a Mutant Brain has no
USB at all. Before this, every path from the deck to hardware ran through a
computer. This is the one that does not.

**Still missing:** MIDI *in*. That needs an optocoupler (6N138 or similar) on the
receive side and is a separate build. Until then the deck is a clock source and
never a clock follower on the wire.

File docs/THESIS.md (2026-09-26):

# The thesis, as it is being built

*[NEXT.md](NEXT.md) §12 asks for a running note: every time a decision is made for
legibility rather than for power, write it down, because that is the paper writing
itself. This is that note. It records decisions and where they are argued; it does
not argue them again.*

---

## The claim

A laptop performer projects their code to prove they are doing anything — the
overhead camera of live coding. The owner's diagnosis is that this answers a lack of
causal understanding in the audience. The claim this device tests is that **a
handheld deck makes agency visible without projection**: the gesture and its result
are in the same place, so the audience gets causality for free instead of being
asked to read code.

That makes two audiences for every decision: the **performer**, reading a 30-column
reflective screen at arm's length, and the **room**, which sees the deck, the hands,
and whatever the deck chooses to put on a bigger screen. A decision is *for
legibility* when it changes what one of them can tell apart.

## The running note

### 2026-09-25

**The playhead lights the whole step.** A step is one character and its modifiers,
and the mark that shows which step is sounding covers all of it — so the running
position is visible *in the text the performer wrote*, not in a separate display.
The owner's decision; [MANIFESTO.md](MANIFESTO.md) §3, entry 6.

**A chord lights from its first note to its last.** `,` stopped being a ghost note
and became a chord, and the mark follows. Entry 1.

**One mark for each thing.** `?`, `-`, `X` and the ghost `,` are gone; `.` is the
only rest; a digit is how much. At thirty columns `,` and `.` differ by a pixel or two
at the baseline, and one of them was a note — indistinguishable to a performer at arm's
length and to anyone reading over a shoulder. Entries 1, 5 and 7.

**A mistake is shown to the performer and never played to the room.** A refused
line names its character and boxes it in the document, and a refusal changes nothing:
a typo mid-song leaves the lane playing what it played. Entry 2.

**The names are the performer's.** `>kick = note 36`: the page reads as music —
kick, bass, cut — not as channels and controller numbers, so a line can be followed
by someone who has never seen the language. Entry 8.

**A routed lane plays at its source's level.** `>route cut kick` moves the filter
*with* the kick's dynamics, so the relation is heard, not only declared. Fixed
because routed lanes had ignored the source's amount; [MAP.md](MAP.md) §9.7.

**The projected picture is the deck's own, bit for bit.** The HDMI node draws the
deck's frames in the deck's glyphs, generated from the same art as the panel
([VIEW.md](VIEW.md)). What the room sees is the instrument's output, not a rendering
of the performer's code — the opposite of the overhead camera. Light ink on black,
kept after the owner's first look: "an inverted version of the display."

**Nothing secret is ever on the screen.** A password is asked for on the status line
and shown as stars, and never becomes a line ([NETWORK.md](NETWORK.md), *SSH, as
built*). On an instrument whose screen is part of the performance, a secret on a line
is a secret shown to the room — the flip side of making everything legible.

**The picture drops a frame before the editor drops a keystroke.** When the view's
output cannot keep up, the frame is dropped whole ([VIEW.md](VIEW.md)). The performer's
hands come first; the room loses a frame of a picture, never a gesture.

**A deck that joins waits to hear where the others are.** Two decks started by two
players now share the step and the bar, not only the tempo, and a following deck is
silent until it knows the leader's count, so its first note lands on the leader's
step. A join is heard as a second player coming in, not as a flam
([NETWORK.md](NETWORK.md), *And the count*).

**A knob is a name on the page.** An input — a phone's fader today, a satellite's
encoder later — is defined like a drum, `>knob1 = knob`, and connected by the same
word, `>route cut knob1`. Whoever reads the screen reads what the gesture controls,
in the performer's own words, rather than a mapping hidden in a controller's
settings ([MAP.md](MAP.md) §9.8). A pad lands on the step, so a press is heard in
time, not when its packet arrived.

### For power, not legibility — listed so the line stays honest

**The pre-turned face** made a cell 22 times cheaper to draw
([HARDWARE.md](HARDWARE.md), *The drawing was the budget*). It changed nothing anyone
can see: the framebuffer is byte-identical, which is what its check proves.

### Before this note began

**Three marks, three treatments.** The solid block belongs to the cursor and nothing
else; the playhead is a bar under the cell; a recognised command word is a bar over
it. They compose, so a cursor on the playhead shows both. Made from the owner's
reports of losing the cursor while a lane ran —
`firmware/components/textgrid/include/textgrid.h`.

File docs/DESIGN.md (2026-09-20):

# Design rationale

What this enclosure is, why it is shaped the way it is, and what was traded
away to get there.

## Brief

A single-form, overbuilt, minimum-footprint handheld terminal built around a
Waveshare ESP32-S3-RLCD-4.2 and a Rii 518BT keyboard, intended for live
performance use — musical live coding, control surfaces, and as a portable node
for a local network — rather than for a desk.

The reference design this project measures solves the same problem as a keyboard
tray and a board case joined together. The brief was explicitly to make it read
as one object instead.

## The footprint is component-bound, and the numbers say so

The honest headline first: **most of the size of this thing is not a design
choice.** Two rigid rectangles have to sit side by side.

```
width  = wall + max(keyboard 109.85, board 93.5) + wall
height = wall + keyboard 59.15 + spine + board 70.1 + wall
depth  = back plate + board stack 11.0 + front face
```

With 3.2 mm walls that is **116.25 × 138.85 × 16.85 mm**, and
`tools/validate.py` asserts each of those three equalities on every run. The
enclosure cannot be made smaller without thinning a wall or crushing a part.

Against the reference:

| | Reference (ATA) | This design | Δ |
|---|---|---|---|
| Height | 151.65 | 138.85 | **−12.80** |
| Width | 116.77 | 116.85 | −0.17 |
| Thickness | 18.00 | 16.85 | **−1.40** |
| Battery bulge | +12.0 | +9.0 | −3.0 |
| Wall | 2.90 | 3.20 | +0.30 |
| Footprint area | 17 708 mm² | 16 218 mm² | **−8.4 %** |

Shorter, marginally narrower, thinner, *and* thicker-walled. The height comes
from deleting the reference's top rail; the thickness comes from discarding
Waveshare's stand base.

Where the width is concerned there is nothing left to take: the keyboard pocket
is 109.85 mm — wide enough to clear both the certified 108.5 mm body and the
rounded retail figure, since the vendor has revised the unit at least once
without publishing new dimensions — and the walls are 3.2 mm, so 116.85 mm is the
floor. The board is 17 mm narrower than the keyboard pocket, and that mismatch is the single biggest
constraint in the design — it is also, usefully, the only free space in it.

## One form, not two cases

The reference splits along the **front face**: a bezel screws onto a tray. That
is the worst available plane for the joint. A drop onto a corner loads the shell
in bending, bending stress peaks at the outer fibres, and the outer fibre on the
display side is exactly where the joint is. Four screws end up carrying it in
shear.

Here the shell is a **monocoque**: the entire front face, all four side walls
and the inter-bay spine are one continuous body, and the joint moves to the
back. Three things follow:

- **The face the user touches has no joint across it.** There is no bezel line,
  no step, and no fastener heads on the front.
- **The assembled shell is a closed section.** Front face, walls and back plate
  form a torsion box; the reference's open tray is a channel.
- **The spine is a shear web.** The 3.2 mm rib between the two bays runs the
  full depth and the full width, right across the middle — which is where a
  device of this aspect ratio wants to fold. The reference's equivalent region
  is a 6.44 mm partition that stops short of the bezel.

### The numbers, and the one they contradict

`tools/structure.py` computes section properties from the rendered mesh — second
moment of area, section modulus, and Bredt's formula for the closed cell — at
90 stations along the axis the device folds about. It is classical section
analysis, not FEA, so it is trustworthy for **ratios and weak-point location**
and says nothing about absolute stress.

| | reference deck | this design |
|---|---|---|
| mean second moment `I` | 9 553 mm⁴ | **20 374 mm⁴** |
| mean section modulus `Z` | 891 mm³ | **1 675 mm³** |
| worst-section `Z` | 212 mm³ | **340 mm³** |

**2.13× the mean bending stiffness and 1.60× at the worst section, in a
smaller envelope.** Fitting the back plate is worth 3.26× on its own, which is
the monocoque argument in one number.

Moving the joint to the back is worth more than expected. At a typical station
the closed section's neutral axis sits at z = 2.75 mm and the joint plane at
z = 3.20 — 0.45 mm from the neutral axis, against 14.10 mm for the front face.
Bending stress varies with distance from the neutral axis, so **the joint at the
back carries about 97 % less bending stress than the same joint across the
face.** That was reasoned qualitatively before it was computed; the computation
made it stronger, not weaker.

The claim it *contradicts* is the "closed torsion box" one, and the correction
is worth stating plainly. Only **11 of 90 stations enclose a genuine cell — 12 %
of the length.** Everywhere else the front face is absent, because that is what
an aperture is, and the section is a U closed only by the back plate. The deck
is not a torsion box with two holes in it; it is two open channels joined by one
short closed cell at the spine. Bredt's formula at that cell gives J = 37 764 mm⁴
against roughly 2 910 mm⁴ for the same outline left open — about **13×**.

So the spine is not merely *a* shear web, it is the only closed cell in the
device, and it is carrying the torsional stiffness of the whole deck. That is a
better argument for it than the one originally made, and it is also a warning:
thinning the spine or opening it up for cable routing would cost far more than
its cross-section suggests.

### The weak point, named

The worst section is at **Y = −36.4 mm, mid-keyboard-bay** — 31 mm from the
spine, which does not cover it. `Z` there is 340 mm³ against a mean of 1 675.

The cause is not an oversight and cannot be designed out: the keyboard aperture
is 106.5 mm across a 116.85 mm body, so there is almost no front face left over
that bay — about 5 mm each side. Any material added there covers keys. The board
bay does not have the problem, because the display aperture is 86.8 mm wide and
leaves ~15 mm of face on each flank; its `Z` runs 1 400–3 300.

The reference deck is weakest in the same place for the same reason (212 mm³),
which is what makes the comparison like for like. This design is 60 % better at
the point that governs. **If this deck fails in a drop, that is where, and the
honest answer is that the keyboard's own width sets it.**

Wall thicknesses are integer multiples of a 0.4 mm nozzle (3.2 = 8 extrusions,
2.4 front = 6, 3.2 back = 8) so every wall prints as solid perimeters with no
sparse infill anywhere in the load path. `validate.py` asserts this.

## Form language

The brief is Dieter Rams read organically: his discipline and restraint, but
with the surfaces of something grown rather than extruded. Those two pull in
opposite directions, and where they conflict the resolution is always the same —
**the constraint wins and the form is honest about it.**

### Continuous curvature, not fillets

A conventional rounded rectangle is an arc tangent to a line. Position and
tangent match at the join; **curvature does not** — it jumps from 1/r to zero.
The eye reads that discontinuity as a hard corner however large the radius is,
which is why a fillet so often looks applied rather than grown.

Every visible corner here is instead a **superelliptical quadrant** of a larger
corner size. At `n = 3.2` with a corner size of 11.2 mm the curve tracks an R8
arc to within 0.2 mm, so the silhouette is unchanged — but the corner now runs
11.2 mm along each edge instead of 8, with curvature ramping in from zero at the
tangent point. That is the whole difference between a radius and a form.

A pure Lamé curve over the entire outline was tried first and is wrong at this
scale: it cuts about 10 mm off each corner, eats the wall, and loses the
straight edges the design is disciplined by. Straight edges with a continuous
corner is the Rams reading; a global superellipse is a lozenge.

### Edges roll, they do not chamfer

The previous revision broke the front and back arrises with a 1.0 mm chamfer —
a 45° cut, which is two more curvature discontinuities. Instead the shell is
lofted through a **smoothstep roll**: each face is inset 1.2 mm from the widest
section and arrives there with zero slope, so there is no arris to catch light.

This costs nothing in envelope. The widest section is at mid-thickness and is
*exactly* `body_w × body_h` — the softening is taken out of the faces inward,
never added outward — and the middle 44 % of the thickness stays at full wall,
so nothing is thinned where it carries load. The roll is bounded by the shell's
thinnest point, at the arris, which measures `wall − edge_soft`. At 1.2 mm that
leaves 2.0 mm of rim around the back opening, and `validate.py` asserts it.

### The cowl grows out of the panel

The battery swelling is the object's one large organic gesture, so it must not
look bolted on. It is lofted with a **tangent foot fillet** reached in the first
20 % of its rise, which removes the base line entirely — there is no edge where
it meets the back panel for light to break on — and it crowns with the same
smoothstep as the shell edges, so the whole object shares one curvature law.

The middle band of its rise is deliberately **straight-sided**. That is not
styling: the cell occupies the lower half of the cavity, and a blob that starts
crowning immediately narrows faster than what it has to contain. The first
attempt did exactly that and the cavity punched out through its own wall — the
back plate rendered as two disconnected bodies. `validate.py` now walks the
wall thickness along the full rise and asserts it never drops below 4
extrusions.

### One perforated element

There is exactly one perforated field on the object: the speaker grille, five
1.2 mm slots on a 2.3125 mm pitch spanning 10.45 mm — which is Waveshare's own
grille height to 0.00 mm. Finer perforation on a tighter pitch is the Braun
grille idiom, and confining it to one place is what lets it read as a considered
detail rather than as venting.

An earlier revision also carried a five-slot vent field, justified as insurance
for sustained Wi-Fi transmit. **It is removed.** The RLCD has no backlight, so
the only meaningful dissipation is the ESP32-S3 itself; the reference design — a
built, working device — has no ventilation beyond its grille and header slot;
and the field sat at an offset that could not be aligned with anything without
fouling the cowl. An element that is insurance rather than requirement, and that
cannot be composed, is the first thing *as little design as possible* removes.

### Controls recessed, not applied

The three buttons sit in **one shallow dish**, 0.9 mm deep with a soft-cornered
flared rim, rather than in three bare holes. The cluster reads as a single
element; the caps sit below the surrounding surface so nothing protrudes to
catch. This is the ET66 keypad move, and it costs 0.9 mm of a 3.2 mm wall.

### Where the language breaks, and why

The **display aperture's corner is smaller than the form wants** — 4.2 mm where
everything else is 9 to 11.2. It is not a compromise of taste. The aperture
height is trapped between the active area it must not clip (63.60 mm) and the
module edge it must still bear on (67.60 mm), leaving exactly 1.0 mm per side. A
superelliptical corner consumes `blend × 0.1948` of that at 45°, so anything
above about 4.6 clips the panel's square corner. 4.2 leaves 0.18 mm.

The outward flare opens it to an effective 5.65 mm at the visible face, which
softens it considerably. But the honest statement is that the panel sets this
corner, not the designer, and `validate.py` asserts the bound rather than
letting a later edit quietly violate it.

The **keyboard aperture's corner is circular, not superelliptical**, and it is
derived rather than chosen. This one was found the hard way.

A lip of constant width around an aperture is the component's outline eroded by
the lip width, and eroding a circular corner of radius `r` by `d` gives a
circular corner of radius `r − d`. A superellipse is not the erosion of a
circle: at `n = 3.2` it sits up to **1.55 mm proud** of the circular arc of the
same corner size, biting toward the box corner — exactly where a rounded
component's corner is retreating away from it. The two effects add.

The Rii 518BT's corner radius is about **10 mm**, measured from the
manufacturer's drawing and from a third-party CAD replica. Against a 9.0 mm
superelliptical aperture corner the lip did not merely get thin, it went
**negative**: the keyboard stopped covering its own aperture, and you would have
seen into the pocket past all four corners with nothing retaining them.

So the corner is `kbd_body_corner_r_max − min(lip_x, lip_y)` = 10.2 mm,
circular, and `validate.py` measures the narrowest lip **around the whole ring**
from the rendered mesh rather than comparing widths. It now reads 0.98 mm at the
corners against 1.00 mm on the flats — constant, which is the point.

The **internal cavity** is likewise not given the treatment. A continuous corner
is tighter at the corner itself than an arc of the same visual line; applied to
the back opening at the shell's own 11.2 mm it undercuts the keyboard bay by
10.96 mm² and traps the keyboard. Measured across candidates, 6.0 mm is the
largest that reaches zero. The cavity is hidden, so it takes 6.0 and the wall
simply runs thicker at the corners (3.7 mm against 3.2 nominal) — which is where
a shell wants material anyway.

## Material and finish

The form is only half of biophilic; the surface is the other half, and it is
chosen at the printer rather than in the CAD.

**Preferred:** a wood-, stone- or hemp-filled PLA, or a matte PETG in a warm
neutral — bone, oat, clay, moss. These read as material rather than as plastic,
they hide layer lines, and they age by dulling rather than by scuffing bright.

**Avoid** gloss black and saturated colour. Gloss turns the rolled edges into
hard specular lines, which undoes the entire edge treatment, and a saturated
shell fights the display — the RLCD is a reflective monochrome panel whose
legibility depends on ambient light, so the body should return light to it, not
absorb it.

**Texture.** Enable the slicer's fuzzy-skin on the *outer walls only*, amplitude
0.15–0.25 mm, point distance 0.6 mm. On the rolled side walls this produces a
fine stochastic grain that catches light like a mineral surface, while the front
face — printed against the bed — stays smooth where the hand and eye actually
land. It costs nothing and it is the single highest-value finish decision.

**Inserts** should be brass and left visible. Rams never hid a fastener that was
doing work; four brass rings on the back are honest and they are the only metal
on the object.

## Everything loads from the back

The board and the keyboard both drop in from behind and are captured by lips in
the front face:

- the **display aperture** (86.8 × 65.6) is 3.35 mm smaller per side than the
  board pocket, so the board cannot move forward;
- the **keyboard aperture** (106.5 × 55.8) is 1.85 / 1.80 mm smaller per side
  than the keyboard pocket, so the keyboard cannot fall through.

The back plate then holds both forward. The keyboard bay is shallower than the
board bay by `board_depth − kbd_depth` = 0.25 mm, and that difference is taken
up by a **ledge in the chassis bay**, not by a pad on the plate: the bay stops
0.25 mm short of the front panel and the keyboard bears on the band that
leaves. It was a raised pad on the plate until printing it cowl-up showed the
pad was the only thing touching the bed. The thickness is still *derived*, not
chosen; only which part carries it changed. A 0.5 mm adhesive foam
gasket around the display aperture absorbs the tolerance stack and doubles as
shock isolation for a panel the reference's own documentation calls fragile.

Service access is genuinely good: four screws release the back plate, and the
board, battery and back plate come out as one module.

## The battery has to stick out, so it was made useful

An 18650 is 18.4 mm in diameter (18.6 for protected cells). This deck is 16.85 mm
thick. The cell cannot be contained — it reaches 8.20 mm past the standoff
plane and must project through the back.

The reference handles this with a separate clip-on cover standing 12 mm proud.
Here the cowl is **integral to the back plate**, which removes a part and two
clips that can break, and shapes the unavoidable bulge into a **grip ridge**. It
runs across the deck just above the spine — where the fingers wrap when a
portrait handheld is held in two hands.

Its rise is derived, not copied: `(protrusion − back plate) + clearance + wall +
cap radius` = 9.0 mm, against the reference's 12.0, because discarding
Waveshare's 2.75 mm stand base moves the whole stack forward.

**The trade-off, stated plainly:** an integral cowl means swapping a cell takes
four screws instead of popping a door. That is the right call for a device meant
to survive a gig bag, and USB-C powers the board anyway — but if hot-swapping
matters more than robustness for your use, `batt_cowl_enable` turns it off and a
separate door becomes the obvious variant.

## The board is narrower than the keyboard, which is where the screws live

Because the keyboard sets the width, the board bay leaves a solid **8.35 mm
flank** down each side. That dead space carries both the back-plate fastener
bosses and the side-port tunnels — at zero cost to the footprint.

It also makes them fight. The USB-C and microSD tunnels cross the same strip the
bosses need, so the two fastener rows are *derived* from three constraints and
asserted, not placed by eye:

- clear of the port band as actually cut (measured opening plus clearance);
- inboard of the back plate edge by enough that an ISO 10642 countersink does
  not break out;
- as far apart as those two allow.

The margins are under a millimetre. Earlier revisions failed both constraints in
turn — the upper countersink broke out of the plate edge, and before that the
ports were cut through the outer wall only, which would have left both
connectors buried behind 8 mm of plastic. Both were caught by assertions, not by
inspection, which is the argument for having them.

A **full-width tongue and groove** along the bottom edge captures the plate
mechanically where there is no room for screws.

## Fasteners

Four **M2 × 6** ISO 10642 countersunk into brass heat-set inserts. They were
M3 until the parts were handled; this section was not updated with them and
described an M3 stack that no longer existed anywhere in the CAD.

Socket caps were the first choice and were wrong: an ISO 4762 head is 2.0 mm
tall at M2 and 3.0 at M3, against a 3.2 mm plate, so counterboring left almost
no material under the head to take preload. The plate stayed at 3.2 mm
(8 extrusions, matching the wall) and the screws went to ISO 10642 countersunk —
1.20 mm deep at M2, bearing on a cone rather than a thin annulus, and flush.

Insert bosses are **Ø6.6 around a Ø3.2 bore**, 6.5 mm deep, for a 4.0 mm M2
insert. The nominal boss wall is 1.7 mm, but that figure understates the part:
the flank strip the bosses sit in is solid from the seating plane to the front
face, so measured on the rendered chassis there is **2.98 mm** of material
between the bore and the nearest free surface, which is the board pocket wall.
The Ø6.6 cylinder is really only a name for a bore in a slab.

## Accessory mounting: the four screws are the rig points

There is no 1/4"-20 socket and no moulded strap lug. Both were designed,
modelled, and removed, because neither fits without growing the envelope or
cutting into a component bay:

- a 1/4"-20 insert needs ~8 mm of bore depth, and the only material at the
  deck's centroid is the 3.2 mm spine — a 10.5 mm bore does not fit in it.
  Anywhere else means a boss protruding from the back, which stops the deck
  lying flat;
- strap lugs want the corner voids, but the keyboard is full-width, so the only
  corner material is the gusset, and a 12 mm webbing slot does not fit inside a
  6 mm fillet without breaking into the keyboard bay.

Instead the four M2 back-plate screws **are** the accessory mounting points.
They thread into brass, not plastic, which makes them the strongest anchors on
the device — though four M2 are a weaker anchor than four M3 were, and this is
not a rigging point for anything heavy. Fit M2 × 12 in place of M2 × 6 and clamp
a bracket, strap yoke or stand clamp under the heads. The bracket must be at
least **2.3 mm** thick: the insert bore is 6.5 mm deep below a 3.2 mm plate, so
a 12 mm screw with nothing under its head bottoms out before it is tight. `accessory_pattern()` in `cyberdeck.scad` publishes
the hole pattern so a bracket can be drilled to match.

This is a real constraint honestly resolved, not a feature quietly dropped.

## Performance-oriented details

- **A keyboard service window, on the left flank only.** The 518BT's power
  slide switch and charging port share one short edge. Without a window the deck
  cannot be switched on. An earlier version cut one on *each* side "so the
  keyboard can be installed either way round" — which it cannot, because the
  keys only read one way up. Worse, mirroring the second window about the bay
  centreline moved the one that matters off the features it exists to reach.
  There is now one window, positioned from the keyboard's **top** edge against
  measurements taken on the owner's unit: the slide switch starts 10.4 mm down
  and the USB-C receptacle 29.6 mm, and the window spans 8.2 to 41.8 mm. See
  [DATUMS.md C-22](DATUMS.md#corrections).
- **Both microphone ports.** The board has a dual-mic array with echo
  cancellation, and blocking one would break beamforming. Both are at ±32.500 mm,
  a figure that came out of an independent measurement and the factory drawing
  identically.
- **Expansion header access**, sized from the header body rather than from
  Waveshare's own narrower window, so a SolarLink-class card can mate.
- **Two presets.** `overbuilt` (3.2 mm walls, default) and `compact` (2.4 mm,
  about 1.6 mm narrower and 2.4 mm shorter, noticeably less rigid).

## What is not proven

Internal consistency is asserted by 113 automated checks, and the structural
claims by classical section analysis in `tools/structure.py`. **Fit against
physical hardware is not, and neither is drop survival** — section analysis
gives ratios, not absolute stress, and nothing here models layer adhesion,
strain rate or impact. There is no FEA and no drop test. Nobody has held these two components against a printed
chassis. [DATUMS.md](DATUMS.md#measure-these-before-a-final-print) lists the four
measurements to take first, and O-04 — a ~2.5 mm disagreement between the
factory drawing and the reference on button height — is the one to check before
anything else.

Print the chassis first, on its own, and offer the parts up to it before
committing to a full set.

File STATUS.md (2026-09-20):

# STATUS — night shift, 2026-09-20

**The acceptance test passes, in full, on the hardware.** Observed:

```
saved 220 bytes, seq 36            last save before the power was pulled
--- Waiting for the device to reconnect...      the power cut
restored 220 bytes, seq 36         byte-for-byte, same sequence number
```

Power on, the keyboard connects by itself, type a paragraph, pull the power,
power on, the paragraph is still there. Every link in that chain is now
observed rather than inferred, including the keyboard re-pairing and
re-subscribing with no intervention.

The single most important line in this file: **I could not see the screen.**
Nothing about what the panel displays is verified below unless you told me so
yourself.

There is a short note already typed into the deck, waiting for you.

---

## Flash it

```bash
. ~/esp/esp-idf/export.sh && cd firmware && idf.py -p /dev/cu.usbmodem21301 flash monitor
```

Watch the log without reflashing:

```bash
. ~/esp/esp-idf/export.sh && cd firmware && idf.py -p /dev/cu.usbmodem21301 monitor
```

Button-free, as required. Every flash tonight worked first time and BOOT was
never touched. Exit the monitor with `Ctrl-]`. On Linux the port is
`/dev/ttyACM0`. If it ever fails to enter the bootloader, add
`--before default_reset` to a direct `esptool` call.

**The monitor is also a keyboard.** Type into it and the characters go into
the document. That is how everything below was tested.

---

## Verified on the hardware

Every row has log evidence from the board on your desk.

| What | Evidence |
|---|---|
| Builds, flashes button-free, boots reliably | ~15 flash/boot cycles, no failures |
| Display initialises, every SPI transaction returns OK | `init ok: 400x300 logical, 15000 B framebuffer, 24 MHz` |
| Framebuffer is in internal DMA-capable SRAM, not PSRAM | `framebuffer 15000 B at 0x3fcea8d0 (internal=1 dma=1)` |
| **Full frame: 4.75 ms** @ 24 MHz | 20-run average, repeatable to ±6 µs across every build |
| **One 6×12 character costs exactly 9 bytes** | measured on the wire |
| **One 12×24 character costs exactly 36 bytes** | measured on the wire |
| Text grid with real margins | `grid 30x10 at (20,12)` — 20 px sides, 12 px top |
| Keyboard pairs, bonds, encrypts and subscribes | `encryption change, status 0` … `subscribed to report 5 of 5` |
| **Typing works, wraps, and redraws** | 408 characters typed in over the cable |
| **Clock: 99.6 % of ticks within 100 µs** | `>jitter`, 3008 ticks, three lanes, 124 bpm, 60 s |
| **Nothing at all between 0.25 ms and 5 ms** | same run: buckets `<.1:2996 <.25:11 <.5:0 <1:0 <2:0 <5:0 >5:1` |
| **One excursion in 3008, caused by a flash write** | worst tick at 12 s; log shows `saved 59 bytes, seq 205, 16219 us` at 13 s |
| **Transport: every event under 100 µs, 64 µs total spread** | `>jitter` xport, 1255 events |
| **Playhead costs 0.94 % of one core** | idle 0 pushes/0 cells per 10 s; playing 84–102 pushes, 94,040 µs render over 498 cells |
| **Redraw rate equals the step rate** | 8.4–10.2 pushes/s against a 16th-note rate of 8.27/s |
| **Swing is exact** | 124 bpm: 50 % → 125/125 ms, 67 % → 83/167, 75 % → 62/188 |
| **Accent / normal / ghost** | velocities 120 / 100 / 33 on the wire |
| **Scale degrees resolve** | `>scale dmin` + `0...3...5...3...` → notes 38, 43, 46 (D2, G2, Bb2) |
| **Polyrhythm: lanes keep their own phase** | 16-step kick vs 12-step hat coincide then separate; kick holds 484 ms |
| **Re-running an unchanged line silences the lane** | kick every 484 ms → Ctrl+Enter → 3.87 s of silence → Ctrl+Enter → resumes |
| **`>flash` reaches the ROM loader with no button** | `rst:0xc (RTC_SW_CPU_RST), boot:0x2 (DOWNLOAD(USB/UART0))` |
| **The USB PHY restore works** | `>usbtest now`: port vanished, returned in 2 s, no power cycle |
| **The escape hatch survives USB MIDI** | `>usbtest flash` → download mode on the SAME port; esptool `--before no_reset` reports `USB mode: USB-Serial/JTAG` |
| **BLE MIDI reaches Ableton** | owner paired it from Audio MIDI Setup and played the deck |
| **A document survives a chip reset** | `restored 408 bytes, seq 2` |
| **A deliberately torn write is rejected; the previous snapshot loads** | `PASS 2/2 … torn-write recovery works` |
| Autosave fires on newline and after a 1 s pause | `saved 180 bytes, seq 11, 3934 us` |
| The journal appends across sectors and wraps | cursor walked 0 → 4096 → 8192 → 45056 |
| BLE host starts, scans, decodes advertisements | ~48 distinct advertisers logged |
| **Keystrokes decode and reach the document** | `report handle 36 len 8: 00 00 17 …` -> 't' |
| **A real power cut, not a reset** | `saved 220 … seq 36` -> unplug -> `restored 220 bytes, seq 36` |
| Keyboard re-pairs and re-subscribes unattended after a power cut | full discovery walk, twice, no button pressed |
| **The SD card mounts** | `SD mounted: 00000, 14910 MB` |
| Memory headroom with everything running | 212 KB internal free, 8.25 MB PSRAM free |

### The acceptance test, minus the radio

Type a paragraph → reset the board → the paragraph is still there. **That now
works**, with the USB cable standing in as the keyboard. The only untested
link in that chain is BLE HID itself.

### The byte counts are the good news

9 bytes for a 6×12 cell and 36 for a 12×24 cell are exactly what the window
arithmetic predicts. Getting both right, at two different cell sizes, against
a real controller, **corroborates the CASET mirroring rule by a route
independent of the driver it came from.** That was the highest technical risk
named in the handoff, and it is retired.

It is also now guarded. `tools/test_st7305_addr.c` compiles the firmware's own
`st7305_addr.h` — not a copy of it — and asserts that writing the leftmost
12 px alone emits `CASET = {0x2A, 0x2A}`. It additionally asserts that a naive
non-mirrored implementation would emit `{0x12, 0x12}` **and that the check can
tell them apart**, so it is a check proven to catch the bug rather than one
that merely passes. It runs in CI with no board attached, along with a check
that both bitmap faces still regenerate byte-for-byte from their art.

### The persistence test is self-driving

`main/selftest.c` walks stages across genuine chip resets using a counter in
NVS. Stage 1 writes a snapshot, **deliberately corrupts its payload**, and
stage 2 asserts the *previous* snapshot comes back. Both stages passed. It has
wiped itself and will not run again.

---

## Written but NOT verified

Stated plainly, because the standing rule on this project is that if it was
not verified on hardware it must say so in those words. Everything below is
**unverified**.

| What | Why it is not verified |
|---|---|
| Whether the playhead bar **reads** on the glass at 8.3 Hz | I have no camera. SPI bytes were measured; legibility was not. `HARDWARE.md` reports the liquid crystal clean only to ~23 Hz, so 8.3 is comfortably inside — but nobody has looked. |
| Whether the inverted status bar reads as "this is output" | Same. If it does not, the louder alternative is a `+` in column 0 of every row of a transient buffer, which costs a column and cannot be missed. |
| The BLE **connection interval** macOS actually grants | The request and the logging are in; no host was connected during the measurement runs. This is the number that decides how much the transport contributes. |
| The BLE **packing ratio** | `blemidi_send` returns early with no host, so nothing was packed. Three lanes on one step should read 3.00× in `>jitter`. |
| The 66-minute counter roll | The arithmetic property is asserted on the host for every lane length 2–32. Nobody has played an odd-length lane for 66 minutes. |
| USB MIDI | Not built. The gate that blocked it has passed; the composite has not been written. |

### Everything optical
I have no camera. The test card, the chunky typeface, ink/paper polarity and
contrast are **unseen by me**. Your look at the first build reported the image
mirrored and 6×12 text too small; both are addressed, neither confirmed.

### The BLE keyboard — connects and subscribes; typing still unproven
**Resolved since the first draft.** The Rii pairs, bonds, encrypts and is
subscribed. Verified from the log:

```
found a keyboard (unnamed), connecting
connected, starting encryption
encryption change, status 0
HID service at 21..53
characteristic discovery done: 5 report(s), protocol mode present
subscribed to report 2 of 5 / 3 of 5 / 5 of 5
```

Two real bugs were behind the original "connects but types nothing":

1. **Nested GATT procedures.** NimBLE allows one procedure in flight per
   connection, and descriptor discovery was being started from inside the
   characteristic-discovery callback. It failed with `EBUSY`, the CCCD was
   never written, and the link looked perfectly healthy.
2. **A double-advance in the subscription walk.** Descriptor discovery reports
   a CCCD *and then* reports completion; both paths advanced the index, so
   every characteristic with a CCCD advanced twice and the walk ran off the
   end — "subscribed to report 7 of 5" while real reports were skipped.

Also worth recording: this keyboard **refuses the boot-protocol write** with
ATT Write Not Permitted (status 259), so it stays in report protocol where the
boot keyboard report never notifies. Collapsing to the boot report — the tidy
thing to do — would have been silently wrong. The firmware subscribes to every
notifiable report instead and decodes any report of three bytes or more.

**The keyboard types.** Verified on the hardware:

```
report handle 36 len 8: 00 00 17 00 ...   't'
report handle 36 len 8: 00 00 0b 00 ...   'h'
report handle 36 len 8: 00 00 08 00 ...   'e'
cyberdeck: saved 177 bytes, seq 22
```

Reports arrive on handle 36 - a report-protocol input report in the 8-byte
boot-style layout - are decoded, and land in the document.

Three things were wrong, and the one that looked most likely was not the one
that mattered:

1. **Nested GATT procedures** (fixed earlier): descriptor discovery started
   inside the characteristic-discovery callback, failed with `EBUSY`, and no
   CCCD was ever written.
2. **A double-advance in the subscription walk** (fixed earlier).
3. **A stale bond.** The keyboard had bonded during the era when nothing was
   ever subscribed, and kept reusing that bond, so the fixed code never got a
   clean pairing. Clearing it and re-pairing is what actually released the
   keystrokes.

Also corrected: Protocol Mode is a *write-without-response* characteristic, so
the original write request was answered with ATT Write Not Permitted (259).

**A theory that was wrong, recorded because it was acted on:** that the link
needed to be MITM-authenticated and the deck had to display a passkey. The
firmware now asks for authenticated pairing and can show a passkey on its own
screen, but the keyboard still negotiates Just Works - `encryption change,
status 0`, no passkey action ever raised - so authentication was never the
problem. The passkey display is kept because it is correct behaviour for a
peer that does demand it, not because it fixed anything here.

### Orientation — settled
The owner cycled KEY until it read correctly in the enclosure and landed on
**orientation 3**. That value is now honoured permanently: a stored
orientation is evidence about the physical build, which the firmware does not
have and must never overwrite, so the shipped default applies only when
nothing has been chosen. The host-side check proves all four mappings are
collision-free bijections.

### True power-cut survival
Verified: full chip reset, and deliberate record corruption. **Not** verified:
yanking power mid-flash-write. The journal is built for it — sector-aligned
records, erase-before-write, CRC per record — but only a real power cut proves
a real power cut.

---

## The SD card: not a blocker, an empty slot

For most of this session the card would not initialise:

```
sdmmc_init_ocr: send_op_cond (1) returned 0x107   (ESP_ERR_TIMEOUT)
```

**There was no card in the slot.** The owner confirmed it afterwards. A timeout
on `SEND_OP_COND` - the very first command after reset - is precisely what an
empty slot looks like, so the driver was behaving correctly the whole time and
the pin map from `solar_term.toml` was right.

Recorded because the reasoning went wrong in an instructive way. Everything
that *was* checked - both clock rates, internal pull-ups, explicit `GPIO_NUM_NC`
on the unused data lines, no card-detect - was checked against the hypothesis
"the bus is misconfigured", and each negative result made that hypothesis look
worse without ever promoting the simpler one. The failure mode is identical for
a missing card and a broken bus, and nothing in the firmware could tell them
apart. **A card-detect line would have, and this board does not route one** -
so the honest fix is for the log to name both possibilities rather than imply
a fault. ESP-IDF's own hint said as much and it was read past.

## What changed in the design, and why

**The grid is 33 × 12, not 66 × 25.** `docs/HARDWARE.md` recommended 6×12
because it is aligned on both axes and cheapest per character — both still
true, both beside the point once you looked at it. The swap was free because
of an asymmetry the document states but does not draw out: **cell height must
be a multiple of 12 (the CASET quantum), but cell width only has to be even
(the RASET quantum is 2 px).** Width is cheap. Now recorded in
`docs/HARDWARE.md` as a measured correction.

`tg_set_font(&tg_font_6x12, 1)` still gives 66 × 25, and the call *refuses* a
misaligned cell rather than letting a line's damage window spill into its
neighbours.

**A new 12 × 24 typeface**, purpose-drawn: 2 px stems, 16-row cap height, real
descenders — built for a low-contrast reflective panel. Both faces generate
from reviewable ASCII art, never hand-edited hex:

```bash
python3 tools/make_font.py --12x24 > firmware/components/textgrid/font12x24.c
```

Monospace is structural, not stylistic: every glyph occupies the same cell and
advances the same distance, so **ASCII art lines up exactly** — which matters
for the Orca and live-visualiser direction you described.

**The USB cable is a keyboard.** Added so the editor could be tested at all
without a radio, but it earns its place anyway: if the BLE keyboard is flat or
lost, the deck is still usable from any terminal over the same cable that
flashes it. Both sources feed one queue and one event taxonomy, per
`docs/OS.md`.

**On the RP2040/HDMI idea:** nothing here forecloses it. Damage is tracked per
cell and resolved to a typed window push, so the same stream that drives the
panel can be serialised to another device later — what `docs/OS.md` means by a
damage list that "makes the deck remotable, screenshottable and testable in CI".
I built no transport; I just did not design it out.

---

## The audit, and what it found

Before building step 5 on top of this, five reviewers went through the tree by
subsystem and every finding was put to two adversarial verifiers instructed to
refute by default. Nineteen survived; all nineteen are fixed.

The one that mattered most had been sitting in plain sight and was reported by
the owner in three words:

**The editor never reached the panel.** `editor_draw()` called `tg_render()`,
which draws the dirty cells and *clears the dirty bits*; `main` then called
`tg_flush()`, which renders again, sees zero dirty cells, and concludes there
is nothing to push. Every edit was drawn perfectly into the framebuffer and
never clocked out. The only things that ever reached the glass were the test
card and the passkey screen, which call `st7305_flush_full()` directly.

The owner said "the text isn't reacting" and that was diagnosed as a keyboard
problem. It was not. Render and present are now separate calls with the reason
written at the call site.

**A keystroke was pushing 13,800 bytes** — 92 % of a full frame — because the
status bar and the hairline rule span the full width and damage was a single
union rectangle. `docs/OS.md` specifies a damage *list* and this is why: with
four rectangles it is **1,272 bytes**, and a cursor blink is 36. Measured
before and after, on the panel.

**The SPI bus had no mutual exclusion** while three tasks reached it - the
main task drawing, the esp_timer callback dropping to LPM, and the NimBLE host
task. `st_cmd_data` holds CS low across a command and its payload, so an
interleaved command lands inside that window and the panel receives a spliced
transaction. Now serialised with a recursive mutex.

**The journal's write cursor followed the last record by offset rather than
the newest by sequence.** On a wrapped journal that put the cursor after a
stale record, and the next save would have erased the sector holding the
newest one. This is the finding that could have lost writing.

Also fixed: the self-test could erase a real document; the view froze silently
past 2,048 display lines (wrapping is now a bounded window around the cursor);
notifications from any characteristic were decoded as keystrokes, including
the battery service; a lost key-up repeated until the BLE supervision timeout;
several discovery failures left the deck connected-but-dead for ever; and the
passkey screen was drawn from the NimBLE task straight into the main task's
framebuffer.

## A lesson about instrumentation

The deck was reported as frozen and was not. It was idle.

Two decisions, each defensible alone, went quiet at the same moment. The
cursor stops blinking fifteen seconds after the last keystroke, on purpose, so
the panel can drop to low power - which makes a working screen look dead. And
every log line was capped or conditional: the push probe stopped after exactly
24 lines, the advertisement log capped at sixteen, and the scan heartbeat only
printed while NOT connected. Connected and idle produced total silence.

So the screen looked frozen and the log looked frozen, and neither was.

The fix is a heartbeat from the MAIN loop, every ten seconds, carrying the
things that distinguish idle from hung - document length, undo depth, keyboard
state, pushes and bytes since the last beat, and free heap:

```
alive: doc 64*, undo 10, kbd up, 26 push/15696 B, heap 199571
```

The main task printing it is itself the proof that the loop is turning. Quiet
now means idle and cannot mean broken. Counters replaced the capped probe, so
the numbers keep flowing rather than stopping just when something goes wrong.

## Things I suspect

- **The panel does not read back.** `RDDID` now executes cleanly but returns
  `00 00 00`. That is consistent with the 23-pin FPC carrying a single
  bidirectional data line — there may be no readable path at all on this
  board. Nothing depends on it; it logs one line at boot and is otherwise
  inert. I left it in because "the panel answered" would be useful evidence if
  it ever does.
- **Per-character latency is ~390 µs against 3.6 µs of wire time.** The cost of
  a keystroke is per-transaction overhead — GPIO toggles and command setup —
  not bandwidth. Nowhere near mattering, but that is where to look if it does.
- **`UP`/`DOWN` move by a whole line width rather than preserving the column.**
  An honest placeholder, not a considered design.
- **CORRECTED: "128 slots wrap safely … nothing is at risk" was false, and it
  was the most dangerous sentence in this file.** The journal kept a write
  cursor and wrapped it to zero when it ran off the end. Sector 0 holds
  whichever document was written first — on this device, the `guide`, which is
  the live-coding preset file. Wrapping erased it to make room for a save of
  something else: silently, at runtime, with no error anywhere. A repository
  that publishes a false reassurance about its own data path is worse off than
  one that says nothing.

  Fixed: the journal now **allocates**. One bit per 4 KB sector records
  whether a live record occupies it, a save finds a free run, and the previous
  version's sectors are released only after the new one is safely down.
  Nothing still reachable is ever erased, and a genuinely full journal reports
  `JOURNAL FULL` on the panel instead of making room by destroying something.
  Observed after the fix: `5 document(s), 5 of 128 sectors live`.

---

## What is measured, and what the numbers mean

The owner reported perceptible timing jitter. The deck now measures its own
timing, and the result redirected the work:

- **The sequencer's clock is not the problem.** 99.6 % of ticks land within
  100 µs of the ideal grid, and there is *nothing* in the buckets between
  0.25 ms and 5 ms. One tick in 3008 was badly late, and its recorded
  timestamp lines up with a 16 ms journal flash write — a flash write disables
  the instruction cache, and the timer callback is not in IRAM.
- **The queue is not the problem either.** Every one of 1255 events waited
  under 100 µs, total spread 64 µs.
- **The transport was.** `blemidi_send` issued one BLE notification per
  message, and a peripheral can only transmit during a connection event. A
  step containing a kick, a hat and a bass note was three notifications, free
  to land in three different connection events. Messages are now packed into
  one packet per step.
- **And the deck never asked for a connection interval**, which the BLE-MIDI
  spec requires. It now requests 7.5 ms and logs what the central actually
  grants.

The remaining controllable term is the flash-cache stall. The fix is
`ESP_TIMER_ISR` dispatch with the whole tick path in IRAM; it is not done,
because it is easy to get wrong in a way that crashes only when the cache is
off, and the research on exactly what may and may not be called from that
context is still open.

## The one thing I would do next

**USB MIDI, as a CDC + MIDI composite.**

The gate that blocked it has passed: `>usbtest flash` proved the deck still
reaches the ROM loader on the familiar port after the USB PHY has been handed
to OTG, so the migration is reversible and cannot strand the owner. The
endpoint budget allows CDC and MIDI together, so the console and the serial
keyboard do not have to be given up to get it.

USB full-speed polls at 1 ms frames against a BLE connection interval of
7.5 ms at best. On the evidence above — a clock holding to 100 µs feeding a
transport quantised to the connection interval — that is where the
perceptible jitter goes.

```bash
. ~/esp/esp-idf/export.sh && cd firmware && idf.py -p /dev/cu.usbmodem21301 monitor
```

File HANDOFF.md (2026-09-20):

# Night shift handoff

*Written by the session that produced everything in `docs/`. Read this first,
then the documents it points at. You have hardware; that session did not.*

## Situation

The owner has gone to bed. On their desk, plugged in right now:

- A **Waveshare ESP32-S3-RLCD-4.2** development board, connected by USB-C.
- A **16 GB microSD card** already seated in the board's slot.

They want to wake up to something they can pick up and use. They will **not be
available** to press BOOT or RESET, so every flash you do must be
button-free. That is fine: the ESP32-S3 has a USB-Serial/JTAG peripheral and
`esptool` can drive it into download mode over the USB CDC control lines.

```
idf.py -p <PORT> flash monitor          # macOS: /dev/cu.usbmodem*   Linux: /dev/ttyACM0
```

If a flash ever fails to enter the bootloader, `--before default_reset` is the
flag that matters. Do not ask them to hold a button.

## Do this first

**The repository is already cloned and you are already in it.** It sits at
`/Distractions/ESP32-S3-RLCD-cYbErDeCk`, which is your working directory, and
the branch `claude/firmware-night-1` has already been created off
`claude/cyberdeck-enclosure-design-4vzwq6`. Do not clone anything.

Confirm the state and pick up anything pushed after the clone:

```bash
git status                                              # expect: on claude/firmware-night-1
git fetch origin
git merge --ff-only origin/claude/cyberdeck-enclosure-design-4vzwq6
```

If that merge reports anything other than "Already up to date" or a clean
fast-forward, stop and read what changed before continuing — the base branch
moved after your clone.

Then read, in this order, and **do not start coding until you have**:

| Read | Why |
|---|---|
| `docs/SUBSTRATE.md` | the conceptual core. One data structure, one noun, three verbs. Everything else is downstream. |
| `docs/HARDWARE.md` | every hardware number, traced to a vendor source. **The ST7305 window-addressing section is the most valuable thing in this repository.** |
| `docs/OS.md` | the firmware design, what is rejected and why, and the build order. |
| `docs/METHODOLOGY.md` | how this project works. It is not optional; the standards below come from it. |

`docs/DATUMS.md` is the enclosure's 35 recorded corrections. You do not need it
tonight, but skim the *shape* of a few records — that is the expected standard
for recording anything you discover.

## What is already established — do not re-research it

The previous session spent a long time on this, all from primary sources.
Re-deriving it wastes your night.

- Panel is a **Sitronix ST7305**, 400×300 landscape, **1 bpp, no backlight**.
  Framebuffer is **15,000 bytes** and **must live in internal DMA SRAM** — SPI
  DMA requires it. Documents and scrollback go in PSRAM.
- **Text grid is 66 × 25 at 6 × 12 px.** This is derived, not chosen: 12 px is
  the panel's own line-height quantum in landscape. One character costs 9
  bytes, one full-width line 600, a full frame 15,000.
- **HPM** self-refresh is 16/25.5/32/51 Hz; **LPM** is 0.25–8 Hz.
- Keyboard is a **Rii 518BT over BLE HID (HOGP)** via NimBLE. This is
  confirmed — the owner scanned the unit and saw an nRF5 advertising the HID
  service. An earlier analysis claimed it was Bluetooth-Classic-only; that
  claim is **wrong** and is recorded as such. Do not act on it.
- **USB-OTG shares one PHY with USB-Serial/JTAG.** EP0 + 6 endpoints, ≤5 IN.
  Not your problem tonight — you want the console, not MIDI.
- Pin map, complete and corroborated, is in `docs/HARDWARE.md`. Display:
  **SCK 11, MOSI 12, CS 40, DC 5, RST 41, TE 6.** I²C: **SDA 13, SCL 14**.
  Buttons: **BOOT 0, KEY 18**. Battery ADC: **ADC1 ch3**.

## The one thing most likely to be got wrong

The ST7305 datasheet Waveshare links is for a **different, smaller part**: it
specifies a 264×320 RAM and a CASET range that does not match this panel. Its
command set, power modes and frame-rate tables are correct; **its address
ranges are not.**

The real mapping, verified against a working Apache-2.0 driver *and*
re-derived independently:

```
column address = 0x12 + x/12     range 0x12..0x2A    1 address = 12 px = 3 bytes
row address    = y/2             range 0x00..0xC7    1 address = 2 lines
mirror base    = 0x12 + 0x2A = 0x3C

CASET (0x2A) = { 0x3C - addr_end, 0x3C - addr_start }   <-- reversed and mirrored
RASET (0x2B) = { first_y/2, last_y/2 }                  <-- must be 2-line aligned
```

**At full width the mirroring is an identity** — `{0x3C-0x2A, 0x3C-0x12}` is
`{0x12, 0x2A}` — so every full-frame driver is silently correct and never
discovers the rule. It only bites when a window narrows. To write the leftmost
12 px alone you must send `CASET = {0x2A, 0x2A}`, **not** `{0x12, 0x12}`.

One RAM byte is **4 px wide × 2 px tall**; the top (smaller-y) pixel is the
higher bit.

**Strongest recommendation of this handoff:** vendor the ST7305 driver from
`github.com/nilseuropa/solar_os` (`src/drivers/rlcd_st7305.c`, **Apache-2.0**)
rather than writing one. It is proven on this exact panel, it implements the
windowing and the HPM/LPM policy, and it will save you the whole night.
`boards/manifests/solar_term.toml` in the same repo is a validated pin map for
this exact board — take it as data.

## Traps that will silently ruin the night

1. **`CONFIG_FREERTOS_HZ` defaults to 100**, so `vTaskDelay(1)` sleeps 10 ms.
   Set it to 1000 in `sdkconfig.defaults` now, not later.
2. **Writing while the panel is in LPM can delay the visible update by up to a
   full refresh period (~1 s).** Kick to HPM on the first keydown. Prior art
   defaults to HPM and makes auto-LPM opt-in — that is the wrong default here,
   but get it working before you get it clever.
3. **SPI reads are 5× slower than writes** (30 ns vs 150 ns cycle). Any read
   path at the write clock fails intermittently.
4. **The framebuffer must not live in PSRAM.** See above.
5. **A driver labelled ST7306 may still be correct** for this panel; Zephyr's
   board definition declares that part. Do not let the name mislead you.
6. **The SD card is an export medium, never the source of truth.** Losing power
   during a FAT write can corrupt the directory, not merely truncate a record.
   Journal to internal flash; sync to SD on newline or a 1 s timer, never per
   keystroke, and write `.tmp`-then-rename.
7. **Trailing whitespace is significant** in any Orca content — see
   `docs/SUBSTRATE.md` for the fence format that makes losing it structurally
   impossible. Not tonight's problem, but do not design it out.

## Build tonight — and only this

`docs/OS.md` has the full build order. **Tonight is steps 1 to 4**, which is
the point at which the device becomes worth carrying. Resist everything else;
MIDI, OSC, Wi-Fi, Orca and the network hub are all explicitly *not* tonight.

1. **Display brought up.** ST7305 over SPI, full-frame push working, then
   windowed update, then the HPM/LPM policy.
2. **Text grid.** 66 × 25 at 6 × 12, a real bitmap font (hand-hinted — at
   1 bpp any TTF rasteriser produces mush), damage tracking so a keystroke
   redraws a character and not a frame, and a status line.
3. **BLE HID keyboard.** NimBLE HOGP host, bonds persisted in NVS,
   auto-reconnect, and a **physical pairing-recovery gesture** — a long hold on
   KEY (GPIO18) that forgets all keyboards. That gesture is not optional: it is
   the only way out of a broken pairing with no screen affordance.
4. **A text buffer they can actually type into, that survives power loss.**
   Gap buffer, cursor, backspace, newline, scrolling. Autosave to flash, mirror
   to SD.

If you finish early, do **not** start MIDI. Harden what exists: reconnect
after reset, bond survival, what happens when the card is missing, what happens
when the keyboard is off.

## Done, defined

The owner should be able to: power it on, have the keyboard connect by itself,
type a paragraph, see it on the screen crisply, pull the power, power it back
on, and **find their paragraph still there.**

That is the whole acceptance test. Everything else is a bonus.

## How this project works

These are the repository's standards and they are why it is in good shape.
Follow them.

- **Measure, do not assume.** A check that computes from parameters instead of
  measuring the artefact is worse than no check. Every defect this project has
  found was in something no check interrogated.
- **Every fix ships with a check proven to fail on the old state.** Not "a test
  that passes" — demonstrate it catches the bug, then demonstrate it passes.
- **Record corrections.** If you discover something that contradicts a document
  here, fix the document and write the record. `python3 tools/check_docs.py`
  keeps the docs honest and runs in CI; keep it green.
- **Commit messages explain *why*, at length.** Look at `git log` for the
  house style. End every commit with the two attribution lines already in use.
- **Never claim something is tested when it is not.** If you could not verify
  it on hardware, say so in those words.

## Before you stop

Write **`STATUS.md`** at the repo root, for the owner to read with coffee. It
must say, plainly:

- What works, verified on the hardware in front of you.
- What is written but **unverified**, and why.
- What is not started.
- The exact command to flash it, and the exact command to watch the log.
- Anything you broke, or suspect.
- The single next thing you would do.

Then commit and push `claude/firmware-night-1`.

If you hit something genuinely blocking — a part that will not initialise, a
dependency that will not build — **do not burn the night on it.** Record it in
`STATUS.md` with what you tried, and build the next thing in the list. Four
working subsystems and one honest blocker is a far better morning than one
subsystem and a mystery.

Good luck. The hard thinking is already done and it is all in `docs/`. Tonight
is about making it real.

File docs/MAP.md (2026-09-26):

# The map

*Every verb the deck has, what it touches, and which of them should not exist.
Downstream of [SUBSTRATE.md](SUBSTRATE.md), which argues there is one data
structure, and [OS.md](OS.md), which argues the clock owns the machine. This
document exists to be **subtractive**: it is the place a proposed feature comes
to be refused.*

Claims are tagged `[FACT]` (verified on hardware), `[JUDGEMENT]` (a decision,
with its reason) or `[OPEN]`.

---

## 0. The thing this document is for `[JUDGEMENT]`

This device gets frozen. Not deprecated, not maintained — **finished**, and then
it is an object rather than a project. That is the whole premise, and it has one
consequence that governs everything below: *the cost of a feature is not the
code, it is the permanent widening of the surface that can never be narrowed
again.*

Software that ships forever can afford to accumulate. Software that is going to
stop has to converge. So the test for any addition is not "is this useful" —
almost anything is useful — it is:

> **Does this let me delete something? Or does it collapse two things into one?**

If neither, it is refused, however good it is.

**Thirty-four verbs `[FACT]`**, counted from the command table itself:

```
    python3 - <<'EOF'
    import re; s=open('firmware/components/cmd/builtins.c').read()
    i=s.index('static const cmd_t'); t=s[i:s.index('};',i)]
    print(len(set(re.findall(r'\{\s*"([a-z0-9]+)"\s*,\s*c_', t))))
    EOF
```

That command is here because the number was wrong twice. Earlier revisions of
this document said sixty-three, from a grep that also matched the `{ "kick", 36 }`
note-lookup tables — data rows, not verbs. A document whose job is to refuse
features on the strength of a count has to be able to show its arithmetic.

**And it went stale a third time, which the snippet did not prevent.** `box`,
`star`, `spin` and `cc` were added, the snippet was not re-run, and three sections
of this document went on saying sixty-five while the firmware said sixty-nine — a
review found it, not the author. A snippet only helps a document that is run against
it, so §0, §2 and §8.5 all take their number from the same place now. The
primitive rework in §9.5 traded three names for three and did not change it.

**Sixty-nine became thirty-six on 2026-09-25, by the snippet, and none were added.**
The thirty-three lane names stopped being verbs: a sound name is a line in the boot
document — `>kick = note 36` — and a picture answers to its own name, so the one lane
command serves all of them ([MANIFESTO.md](MANIFESTO.md) §3.8). That is criterion 5
of §8 honoured by thirty-three, where [NEXT.md](NEXT.md) guessed thirty-one.

**Thirty-six became thirty-four the same day: `guide` and `prose` are gone.** They set
a buffer's *kind*, and nothing has read a kind since Enter stopped running lines in a
guide buffer and `>` began marking what a command is (the note at Enter in
`firmware/main/editor.c`). A verb that changes nothing anyone can see is a lie on the
help page. An old line that still runs one is told `guide is gone: > marks a line`.

---

## 1. The one idea `[JUDGEMENT]`

A **lane** is one line of text that answers three questions:

```
    WHEN      the pattern       x..x..x.
    HOW MUCH  the digits        0..3..9.
    WHERE     the binding       a note, a controller, a shape, a wire
```

That is the entire language. Everything else is either a way of writing a lane,
a way of looking at lanes, or a place lanes go.

**The audio and the visual world are not two worlds.** `>kick x...x...` and
`>disc x...x...` are the same sentence with different destinations. A kick is a
lane bound to note 36 on channel 10; a circle is a lane bound to a drawing
primitive; a filter sweep is a lane bound to CC 74; an OSC message is a lane
bound to a path. The deck does not know or care which — it compiles text into
*when* and *how much*, and hands the result to a binding.

This is what makes the device a controller brain rather than a sequencer with a
visualiser bolted on. The outputs are swappable because the language never
mentions them. Add a DIN jack, an RP2040 over HDMI, a light rig, a plotter — the
language does not change, because it never described the output in the first
place.

**Corollary, and it is the thing to hold on to:** if a feature request can only
be satisfied by teaching the language about a specific output, the request is
wrong. Teach the *binding* about the output.

---

## 2. The surface, as it stands `[FACT]`

Thirty-four verbs, grouped by what they actually touch — and the names, which are not
verbs.

### Lanes — no verbs, one command, and the names are yours

A line whose first word is a **name** is a lane. A name is defined, and the boot
document defines these sixteen at startup:

```
kick snare hat ohat clap tom rim crash      >kick = note 36      a drum on ch 10
bass lead pad arp                           >bass = voice 2 ...  degrees, octave, gate
cut res mod rev                             >cut = cc 74         a controller
```

and the sixteen pictures answer to their own names:

```
disc box turn ramp grid noise    FIELDS: distance from a thing, as a tone
mask edge                        THRESHOLDS: a level through a field, a contour of it
echo move spin warp              memory and motion
grow thin flip fold              shaping
```

Not shapes — see §9.5 for why that distinction is the whole of the third design.
Every lane, sound or picture, goes through `cmd_lane()`: resolve the name to a
binding, `seq_lane_bind()`, then `seq_lane()` to compile. A player adds a name with
a line — `>conga = note 63` — and can move one: `>kick = note 35` retunes the kick
that is already playing. An address picks a second one or a part of one: `disc:2`,
`disc:x`, `disc:2:x` (§9.3). There is no `viz` keyword and no `cc` verb; a
controller without a name gets one: `>fx = cc 20`.

### The clock — 6
```
bpm scale swing sync play stop
```

### Where events go — 6
```
send      enable or disable a destination
usb       become a USB MIDI device (reboots)
din       MIDI on a wire, no host needed
osc       set an OSC target
wifi host join a network, or be one
```

### Looking at things — 6
```
lanes jitter dump density split frame
```

### Documents — 8
```
help list new name open run save close
```

### Escape hatches and the rest — 8
```
panic flash battery kbd mute solo route ssh
```

(`kbd` was in the table and missing from this list, which added up to thirty-five.)

---

## 3. What is redundant, and the verdict

### 3.1 Two lane systems that are one lane system `[FACT]` `[OPEN]`

`seq_lane_t` and `vlane_t` are, field for field:

| | seq | viz |
|---|---|---|
| step bitmask | `mask` | `mask` |
| maybe-steps | `chance` | `chance` |
| per-step odds | `prob[]` | `prob[]` |
| per-step value | `deg[]` | `val[]` |
| step count | `steps` | `steps` |
| ticks per step | `tps` | `tps` |
| muted | `muted` | `muted` |
| pattern hash | `src` | `hash` |
| routed from | — | `src` |

Two structs, two compile loops (both walking the same `seq_pattern.h`), two mute
mechanisms, two re-run toggles, two budgets (8 lanes vs 13 primitives), two
listings. Every bug found in this area during development was found **twice** —
once in each — or found in one and left standing in the other for days. The
routing bug, the mute-does-not-clear-the-frame bug, and the bare-name-drop
behaviour were each fixed in one half long before the other.

**Verdict: collapse them.** See §4. This is the single largest deletion
available and it removes the `viz` keyword entirely.

### 3.2 Seventeen drum and voice names `[JUDGEMENT]`

`kick`, `snare`, `hat` … are one function with a lookup table. This is **not**
redundancy and stays. A name that carries a sensible default note, octave and
gate is the difference between an instrument and a MIDI implementation chart —
`>bass 0...5...` sounding like a bass before anything is configured is the point.
They cost one table row each and no language surface.

### 3.3 Four ways to silence a lane `[JUDGEMENT]`

```
>mute kick          explicit, reversible, a performance gesture
>solo kick          derivable from mute, but one keystroke in a hurry
>kick               bare name: the lane is GONE, frees its slot
re-run the line     toggle, the live-coding gesture
```

Four, and all four survive — they mean genuinely different things and each has
been reached for. But they must behave *identically across audio and visual*,
which they did not until recently and which §4 makes structural rather than
maintained.

### 3.4 Destination configuration is four shapes `[OPEN]`

```
>send <name> on|off      the general mechanism
>usb on                  ... which also reboots
>din <gpio>              ... which also configures
>osc <ip> <port>         ... which also configures
```

`send` is the enabler; the others are *configuration* that implicitly enables.
That is defensible but undiscoverable: nothing tells you `>send` is the thing
they have in common. **Candidate:** `>send din 17`, `>send osc 10.0.0.5 9000`,
`>send usb on` — one verb, and each destination parses its own argument, which is
already the calling convention ([COMMANDS.md](COMMANDS.md)). Costs: breaks boot
documents already written. Not decided.

### 3.5 View verbs mixed into the language `[JUDGEMENT]`

`density` and `split` describe *the screen*, not the piece. They are correctly
separate verbs and should never gain pattern syntax. Noted here so that the next
time something wants to be "a visual parameter", it is asked which of the two it
is: a property of the piece (a lane) or a property of the monitor (a view verb).

---
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

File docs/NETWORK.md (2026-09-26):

# The network: the deck as laptop and router

*Whether the deck can host its own Wi-Fi network, let Raspberry Pis join it,
SSH into them, and route them out through a phone — replacing the laptop and
the router currently carried to every installation.*

**The answer is yes, on this silicon, with no coprocessor.** This document
records the evidence, the numbers, and the four things that will break first.

Tags: `[BUILT]` compiled and run during this assessment · `[MEASURED]` read
from a linker map, `nm`, or an instrumented run · `[PROJECTED]` computed from
measured parts, not observed · `[OPEN]` not established.

## The headline
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

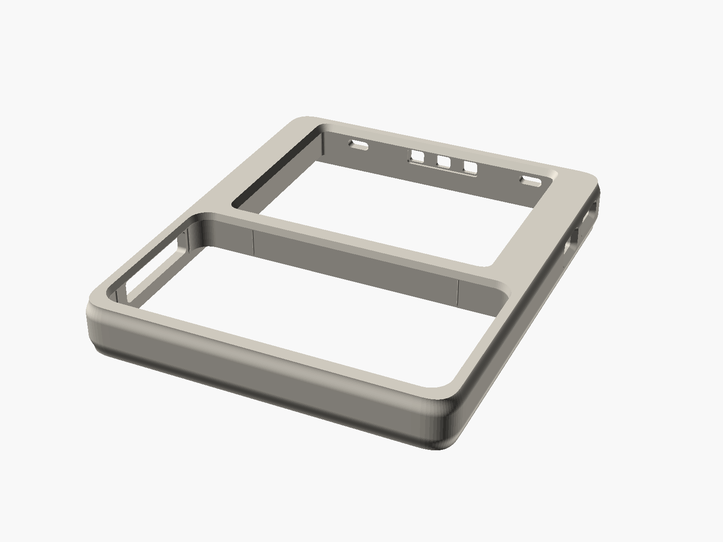
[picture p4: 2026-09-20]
docs/img/chassis-iso.png

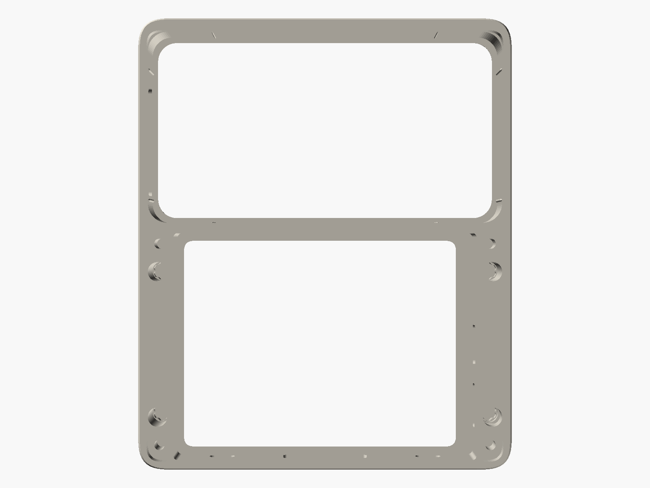
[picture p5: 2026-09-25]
docs/img/chassis-rear.png

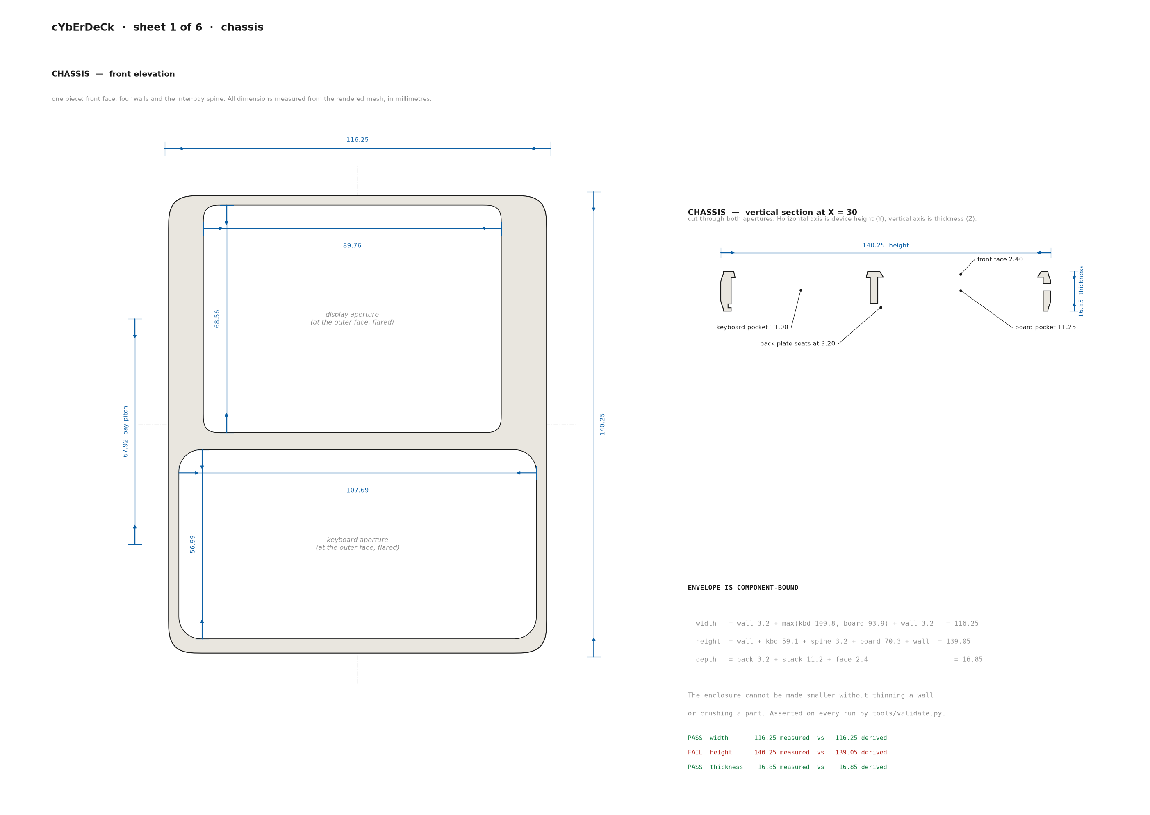
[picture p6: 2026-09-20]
export/drawings/sheet1-chassis.png

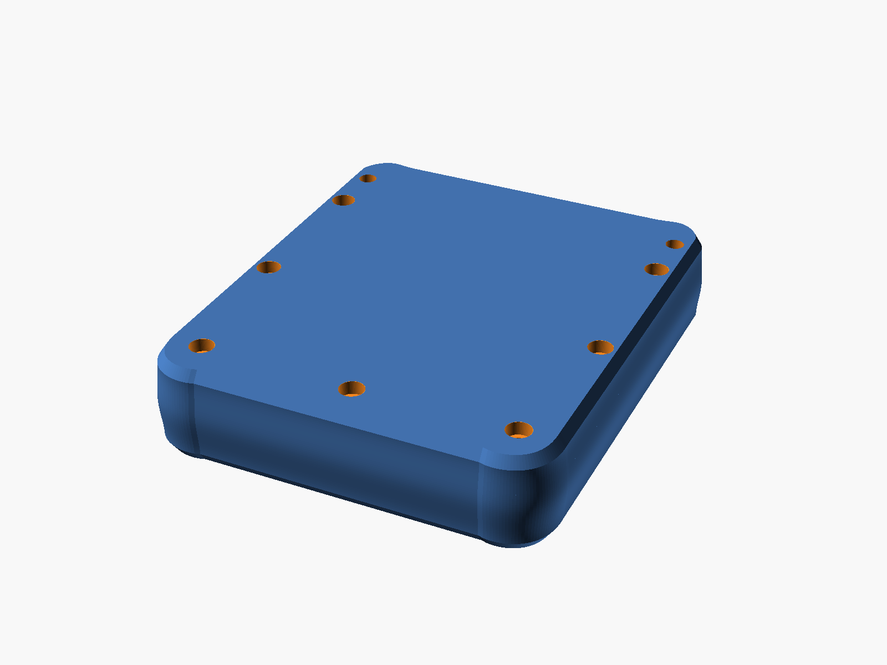
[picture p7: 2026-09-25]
docs/img/case-iso.png

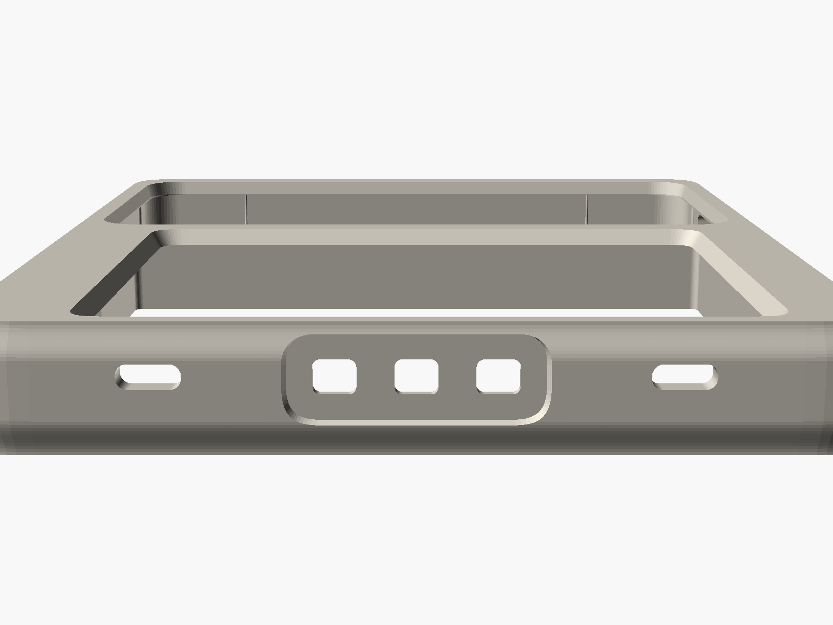
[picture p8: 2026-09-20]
docs/img/detail-top-edge.png

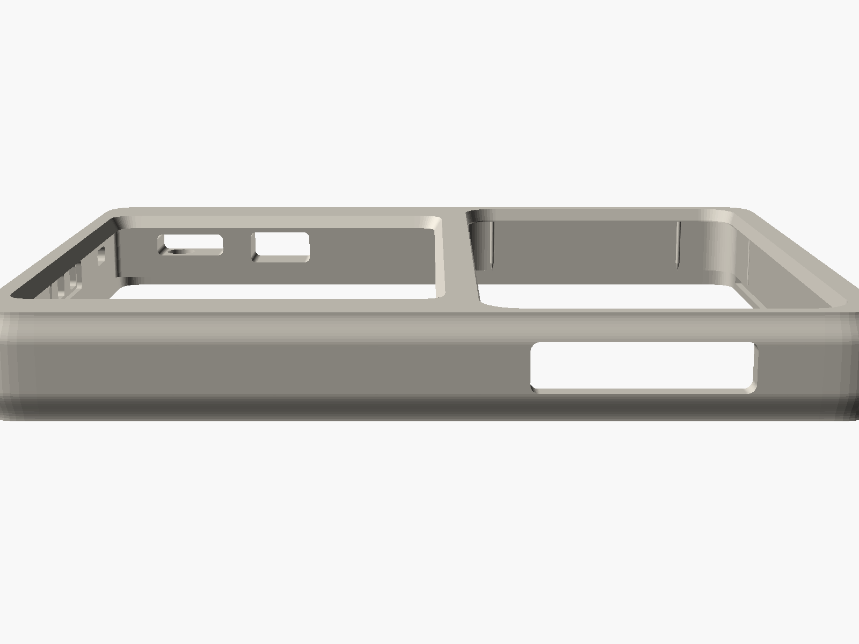
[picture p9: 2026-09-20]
docs/img/detail-left-flank.png

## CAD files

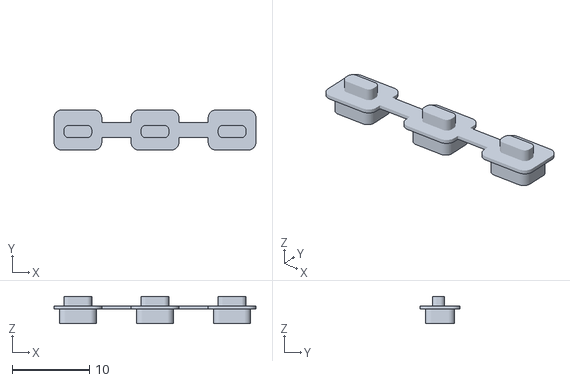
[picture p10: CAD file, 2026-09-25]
export/stl/buttons.stl
26.2 x 5.20 x 3.54

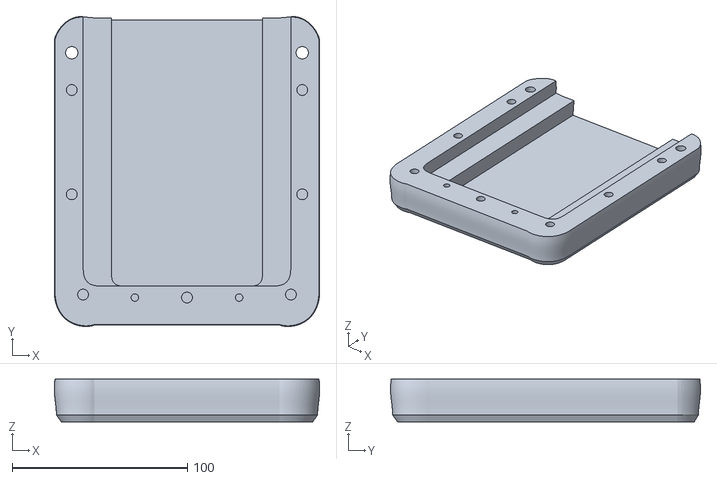
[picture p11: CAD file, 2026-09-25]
export/stl/case/carrycase-back.stl
151.6 x 177.1 x 24.5

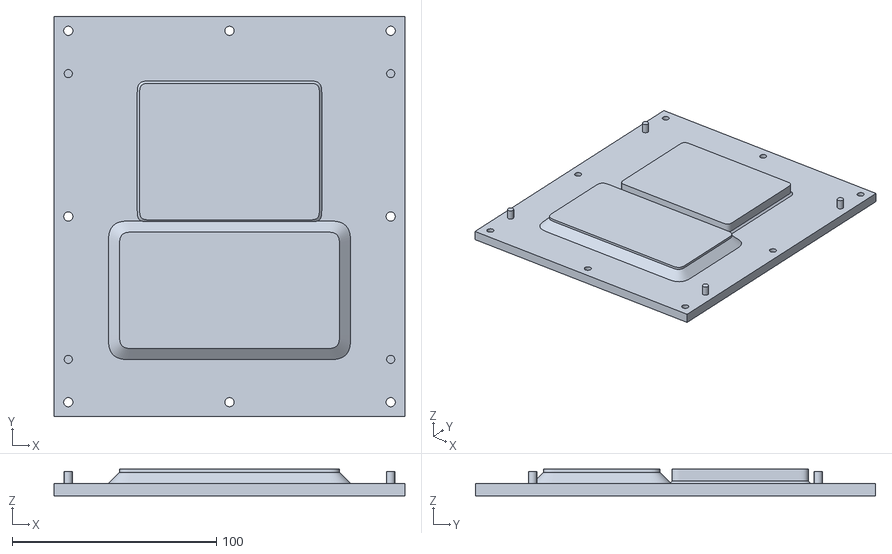
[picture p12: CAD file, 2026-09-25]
export/stl/concrete/conc_mold_face.stl
171.9 x 195.9 x 13.0

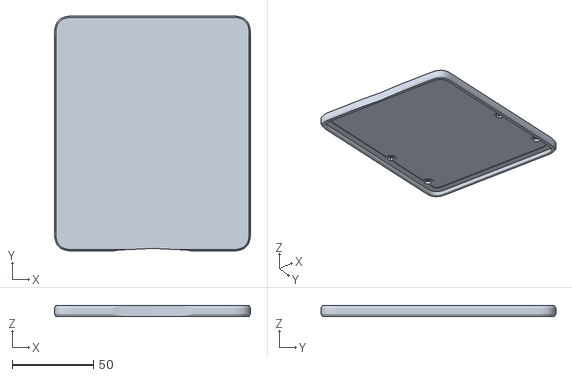
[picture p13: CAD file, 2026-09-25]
export/stl/cover/cover-v3-shell.stl
121.0 x 144.9 x 6.55

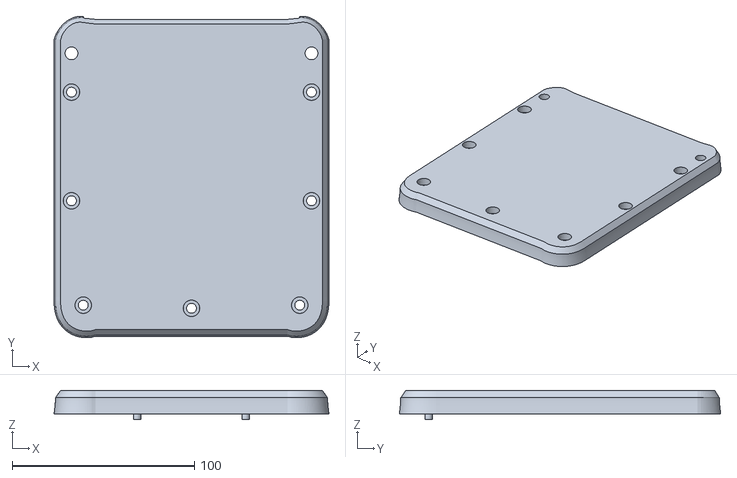
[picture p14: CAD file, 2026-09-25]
export/stl/case/carrycase-front.stl
150.8 x 176.3 x 16.0

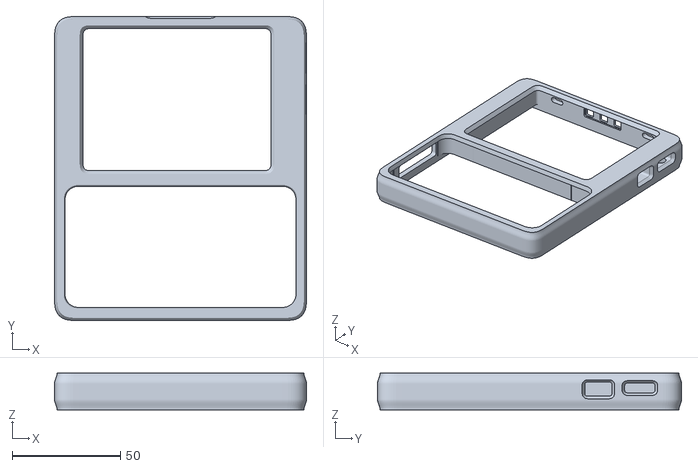
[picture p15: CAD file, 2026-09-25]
export/stl/chassis.stl
116.2 x 140.2 x 16.9

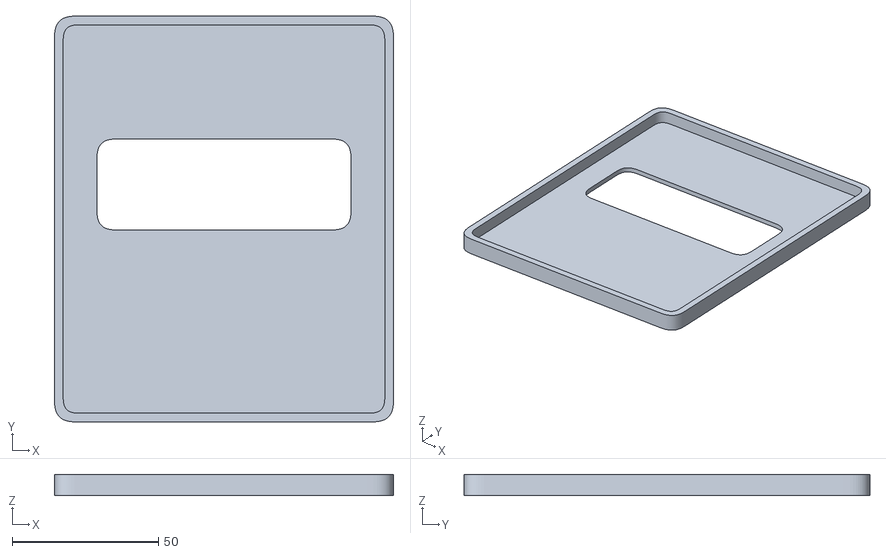
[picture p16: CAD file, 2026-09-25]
export/stl/concrete/pour_dam.stl
115.8 x 138.7 x 7.20

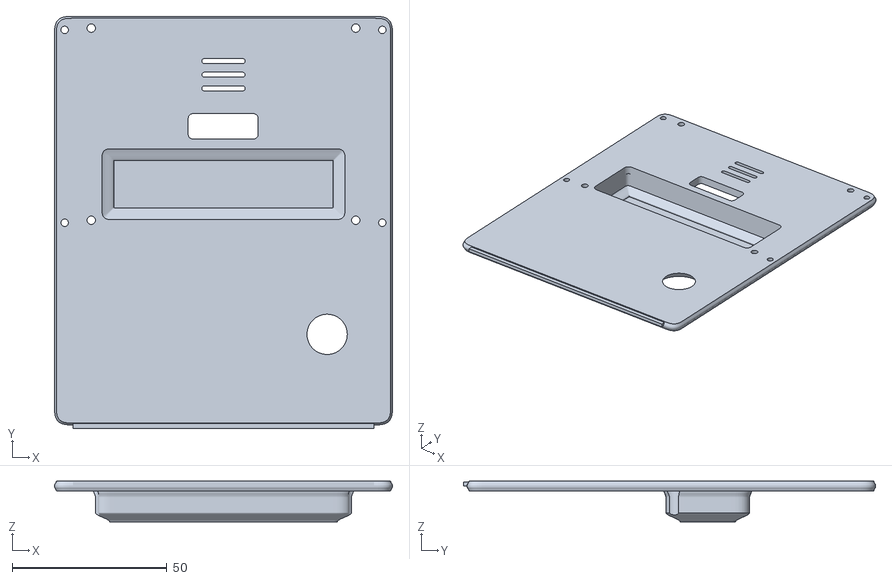
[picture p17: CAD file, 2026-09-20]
export/stl/backplate.stl
109.2 x 133.2 x 13.2

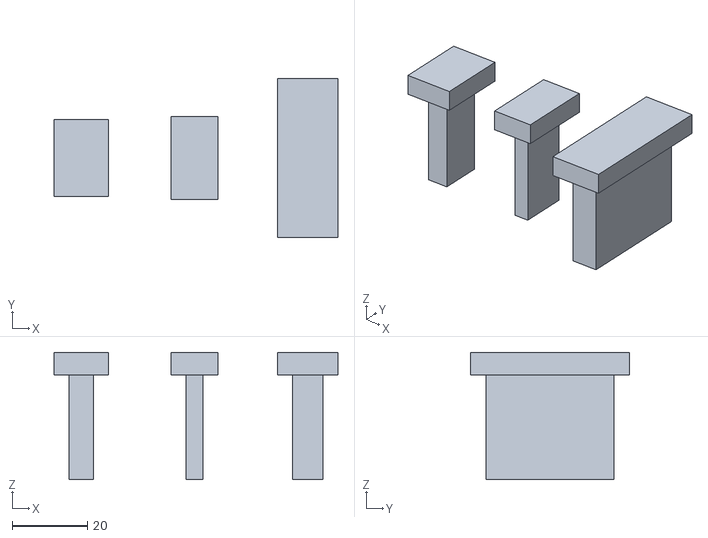
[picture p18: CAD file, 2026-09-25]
export/stl/concrete/conc_cores.stl
75.2 x 42.0 x 33.7

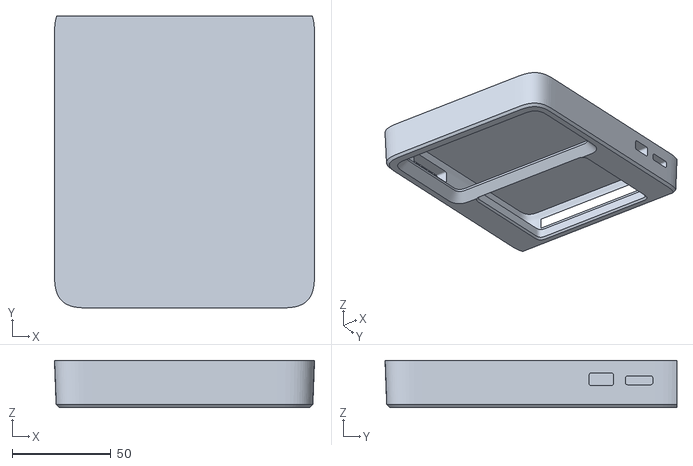
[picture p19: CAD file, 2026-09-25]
export/stl/concrete/conc_jacket.stl
131.9 x 148.1 x 23.9

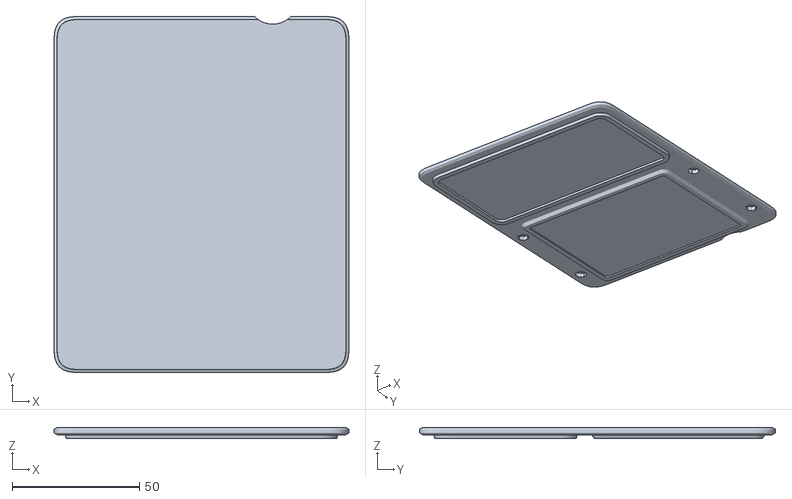
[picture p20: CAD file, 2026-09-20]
export/stl/cover.stl
116.0 x 139.9 x 4.45

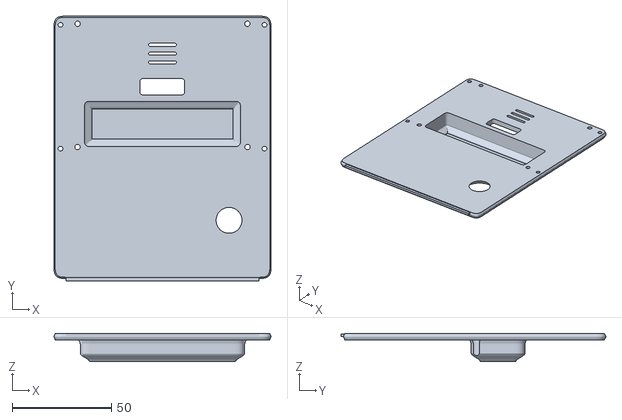
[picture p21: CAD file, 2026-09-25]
export/stl/concrete/backplate-v2.stl
109.2 x 133.2 x 14.2

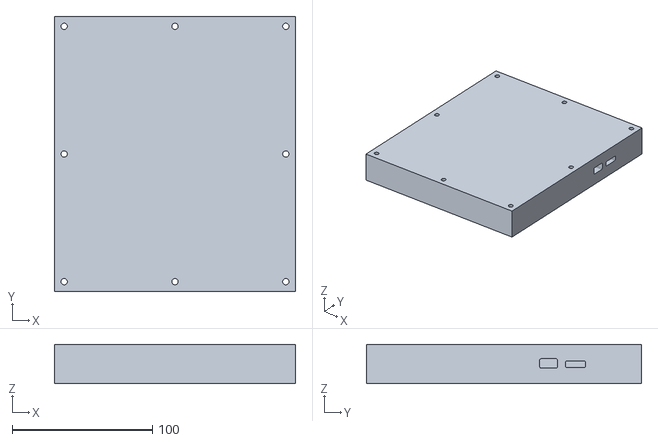
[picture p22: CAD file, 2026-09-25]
export/stl/concrete/conc_mold_collar.stl
171.9 x 195.9 x 27.8

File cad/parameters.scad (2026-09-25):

// ===========================================================================
//  cYbErDeCk - parameters.scad
//  SINGLE SOURCE OF TRUTH for every dimension in this project.
// ===========================================================================
//
//  RULES OF THIS FILE
//  ------------------
//  1. No number appears anywhere else in the CAD. If a model file contains a
//     bare dimension, that is a bug.
//  2. Every datum carries a provenance tag in its comment:
//
//       [MEASURED]  numerically recovered from a reference artefact by
//                   tools/measure_reference.py. Re-derivable; see
//                   export/reports/measurements.json.
//       [VENDOR]    published by the component manufacturer.
//       [DERIVED]   arithmetic on a [VENDOR] or [MEASURED] value.
//       [STANDARD]  an ISO/IEC standard or a manufacturer's fitting spec.
//       [DESIGN]    a choice made by this project. Rationale given inline.
//       [PROVISIONAL] not yet corroborated by a second independent source.
//                   Listed in docs/DATUMS.md under "Open items".
//
//  3. Anything tagged [PROVISIONAL] must be caliper-checked against the
//     physical parts before committing to a final print. tools/validate.py
//     fails the build if a [PROVISIONAL] datum is used in a load-bearing fit
//     without a declared safety margin.
//
//  COORDINATE SYSTEM
//  -----------------
//      origin  = centre of the device footprint, on the BACK OUTER face
//      +X      = device width,  left -> right as the user faces the display
//      +Y      = device height, bottom -> top  (keyboard at -Y, display at +Y)
//      +Z      = thickness, back face (Z=0) -> front face (Z=body_t)
//
//  The device is used in portrait: display on top, keyboard below.
//
// ===========================================================================

// ---------------------------------------------------------------------------
// 0. BUILD CONFIGURATION
// ---------------------------------------------------------------------------

// Render quality. 64 for exports, 32 while iterating.
$fn = 64;

// Nozzle diameter. Wall thicknesses below are integer multiples of this so
// that every wall prints as solid perimeters with no weak sparse infill.
//  0.8 mm NOZZLE. This deck is printed on a 0.8 nozzle, not a 0.4, and that is
//  not a slicer setting - it changes what "thin" means in every wall on the
//  object. A wall that was three comfortable extrusions at 0.4 is 1.2 at 0.8,
//  which the slicer resolves as a single bead with a gap beside it. The whole
//  PRINT class is written against this number, so raising it is what turns
//  "chunky and overbuilt" from an intention into a gate.
nozzle = 0.8;                       // [DESIGN]
layer_h = 0.3;                      // [DESIGN] typical for a 0.8 nozzle
//  The floor every structural wall has to clear: two full beads. One bead is
//  printable but single-walled, and single-walled is not what this object is.
min_wall = 2 * nozzle;              // [DERIVED] = 1.60

// Structural preset:
//   "overbuilt" - 3.2 mm walls (8 perimeters). Default. Impact-tolerant.
//   "compact"   - 2.4 mm walls (6 perimeters). ~1.6 mm narrower, ~2.4 mm
//                 shorter, noticeably less rigid. For pocket carry.
preset = "overbuilt";               // [DESIGN]

wall     = (preset == "compact") ? 2.4 : 3.2;   // [DESIGN] n x nozzle
spine    = wall;                                 // [DESIGN] inter-bay rib
front_t  = 2.4;                                  // [DESIGN] 12 layers @0.2
back_t   = 3.2;                                  // [DESIGN] 16 layers @0.2, and
                                                 //   8 extrusions, matching the wall


// ===========================================================================
// 1. WAVESHARE ESP32-S3-RLCD-4.2  -  TARGET COMPONENT A
// ===========================================================================
//
//  PRIMARY SOURCE. Waveshare publishes a 3D package for this board:
//    https://files.waveshare.com/wiki/ESP32-S3-RLCD-4.2/ESP32-S3-RLCD-4.2-3dFile.rar
//  containing a Creo STEP assembly, a dimensioned DXF and a dimensioned PDF
//  drawing. Every [VENDOR] figure below is read from that package, either from
//  a drawing DIMENSION entity or from a B-rep bounding box of a named solid.
//  This supersedes the "92.5 x 70.1 x 13.5 mm" figure that circulates on
//  distributor pages - see the correction note below.
//
//  BOARD DATUM FRAME (Waveshare's, retained so coordinates stay checkable):
//    U  0 -> 92.50   along the long PCB axis.  U = 92.50 is the USB-C / TF edge.
//    V  0 -> 69.10   along the short PCB axis. V = 69.10 is the button edge.
//    W  0 at the PCB BACK (component) face, +W toward the display.
//  Mapping into this file's device frame:  U -> +X,  V -> +Y,  W -> +Z.
//  That mapping is not assumed: it is fixed by three asymmetric features that
//  must land where the reference enclosure puts them - the buttons on V=69.10
//  (device top edge), USB-C/TF on U=92.50 (device right edge), and the battery
//  offset toward V=0 (device bottom).
//
//  THE STAND BASE IS DISCARDED. The board ships with a moulded back plate and a
//  fold-out 60-degree kickstand, both removable. This design leaves them off:
//    - the 70.10 mm figure disappears (that is the base, which overhangs the
//      PCB by exactly 1.00 mm on one long edge; the PCB itself is 69.10)
//    - 2.75 mm of stack thickness disappears with it
//    - the four SMTSO standoffs are on the PCB, not the base, so nothing is
//      lost mechanically
//  See docs/ASSEMBLY.md step 1.

// --- outline ---------------------------------------------------------------
board_w        = 92.50;   // [VENDOR] drawing text "92.5 PCB OD"
board_h        = 69.10;   // [VENDOR] drawing text "69.1 PCB OD"
board_pcb_t    = 1.60;    // [VENDOR] STEP BOARD solid
//  CORRECTED FROM A PRINTED PART. The drawing says R0.5; the board in hand is
//  a PERFECT RECTANGLE, square to the eye and to a straightedge at all four
//  corners. This is the same class of error as the 18650 holder (C-21): a
//  vendor radius that the real part does not have. It matters because the
//  pocket was sized on the assumption that its own corner arc could tuck
//  inside the board's - it cannot, because there is nothing to tuck into.
//  See docs/DATUMS.md C-34.
board_corner_r = 0.00;    // [MEASURED] square, all four corners

//  CORRECTION, recorded deliberately. Earlier revisions of this file carried
//  board_h = 70.1 from a distributor spec line, tagged [PROVISIONAL]. The
//  factory drawing shows that "92.5 x 70.1 x 13.5" conflates three different
//  objects: 92.50 is the PCB length, 70.10 is the STAND BASE outline, and 13.50
//  is the display-front-to-base-rear stack, which EXCLUDES the battery holder.
//  A pocket cut to 70.1 leaves a 1 mm gap on one long edge.

// --- depth stack, all in the W frame ---------------------------------------
board_w_display_front = 3.75;    // [VENDOR] display glass front face
board_w_pcb_front     = 1.60;    // [VENDOR]
board_w_pcb_back      = 0.00;    // [VENDOR] datum
board_w_standoff_end  = -7.00;   // [VENDOR] SMTSO-M2.5-7ET, 7.00 mm tall
board_w_battery_end   = -15.20;  // [VENDOR] 18650 holder, the deepest feature

// Clear depth the enclosure must provide between the front-face lip and the
// back plate's inner face: display front down to the standoff seating plane.
//  MEASURED ON THE HARDWARE and it is NOT what the vendor CAD implies. Calipers
//  on a real board, glass front to the back of the metal standoffs at the
//  corners, give 11.00 mm against the 10.75 this derives from Waveshare's own
//  W coordinates. The 0.25 difference is the whole gasket squeeze, so taking
//  the CAD value would have seated the display hard against the front panel
//  with no compliance at all. The measurement wins; see docs/DATUMS.md D-03.
board_stack_cad = board_w_display_front - board_w_standoff_end;   // = 10.75
board_stack     = 11.00;  // [MEASURED] calipers, corners, glass front to standoff back
board_depth     = 11.25;  // [DESIGN] board_stack + 0.25, taken up by a 0.5 mm
                          //   adhesive foam gasket round the display aperture
// How far the battery holder reaches past the standoff plane - this, not the
// cell diameter, is what the cowl actually has to swallow.
batt_protrusion = board_w_standoff_end - board_w_battery_end;     // = 8.20
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

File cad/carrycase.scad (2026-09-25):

//  carrycase.scad - a two-part sleeve the whole deck slides into.
//
//  Front half and back half, split on a plane parallel to the face, drawn
//  together by seven M5 socket screws into heat-set inserts. Every port is
//  buried. Meant to be flocked inside and filled, sanded and polished outside.
//
//  THE FORM IS A RIVER ROCK. Two things make it one, and neither is styling
//  applied afterwards:
//    - the section rolls continuously from face to face, with no flat band
//      anywhere and no arris
//    - the wall is 6 mm and SWELLS to 16.5 at each of the nine fastener and
//      strap sites, by pushing the plan OUTLINE outward rather than by adding a
//      pad, so there is no junction to crease at
//  The swells are also what pays for the thin wall: 13 mm everywhere was
//  serving nine holes, and the flanks measured 36 per cent of the filament.
//
//  HOW IT HOLDS THE DECK. The cowl channel, which keys it in X and rotation for
//  its whole travel; the flock; and gravity, because it is carried mouth-up.
//  The four magnets are a seat at the end of that travel, not a latch - the
//  numbers are in parameters.scad and they are not flattering.
//
//  PRINTING. Front half face-down, back half back-down. Both are then a flat
//  bed face and an open tray, no bridge, no support.
//
//  Coordinates are the deck's own, so alignment needs no arithmetic.

include <parameters.scad>
use <lib/util.scad>
use <cyberdeck.scad>

part = "assembly";   // front | back | assembly | fitcheck
$fn = 64;

//  ===========================================================================
//  THE FASTENER RING
//  ===========================================================================
//  An OUTSET OF THE CAVITY, not an inset of the outline. With a wall that goes
//  from 6 to 16.5 there is no single inset of the outline that lands every bore
//  6.50 mm outboard of the cavity, which is what the 3 mm metal margin needs.
//
//  The right half of the path: bottom dead centre, along the floor, round the
//  corner, up the flank, stopping short of the mouth. The corner comes out of
//  rse_poly itself, so the fasteners sit on a real curve and cannot drift.
function ring_path() =
    let (W  = case_ring_w,
         H  = case_ring_h,
         C  = case_ring_r,
         q  = 32,
         o  = rse_poly(W, H, C, form_n, q),
         ay = H / 2 - C,
         q4 = [ for (i = [3 * (q + 1) : 4 * (q + 1) - 1]) o[i] ])
    [ for (p = concat([[0, -H / 2]], q4,
                      [[W / 2, ay - case_bolt_top_back]]))
        [p[0], p[1] + case_ring_cy] ];

function _cum(p, i = 1, a = [0]) =
    i >= len(p) ? a : _cum(p, i + 1, concat(a, [a[i-1] + norm(p[i] - p[i-1])]));

function _at(p, a, s, i = 1) =
    i >= len(p)  ? p[len(p) - 1]
  : a[i] >= s    ? p[i-1] + (p[i] - p[i-1])
                   * ((s - a[i-1]) / max(a[i] - a[i-1], 1e-9))
                 : _at(p, a, s, i + 1);

function ring_at(f) =
    let (p = ring_path(), a = _cum(p)) _at(p, a, a[len(a) - 1] * f);

function _mirrored(r) =
    concat(r, [ for (q = r) if (q[0] > 0.01) [-q[0], q[1]] ]);

function bolt_sites() =
    _mirrored([ for (k = [0 : case_bolt_m]) ring_at(k / case_bolt_m) ]);

function pin_sites() =
    _mirrored([ for (k = case_pin_ks) ring_at(k / case_bolt_m) ]);

//  ===========================================================================
//  THE FORM
//  ===========================================================================
//  Built as ONE polyhedron. A stack of hulls cannot do it: the outline dips
//  back between swells, so it is not convex and hull() would fill the dips.
function boss_sites() =
    concat(bolt_sites(),
           [ for (sx = [-1, 1]) [sx * case_lug_x, case_lug_y] ]);

//  Swells combine as 1 - prod(1 - f), not as a sum, so two sites near each
//  other blend instead of stacking to twice the amplitude.
function _swell_at(p, sites, i = 0, acc = 1) =
    i >= len(sites) ? case_boss_amp * (1 - acc)
    : let (d = max(0, norm(p - sites[i]) - case_boss_lift),
           f = pow(cos(min(90, 90 * d / case_boss_reach)), 2))
      _swell_at(p, sites, i + 1, acc * (1 - f));

//  Two corrections live in this function, both found by measuring the rendered
//  section rather than by reading it.
//
//  ONE: the roll inset is applied to the BASE outline only. Subtracting it from
//  the swell as well applies it twice - the face outline came out at 65.61 where
//  the bolts sit at 65.825, so four of the seven counterbores cut out through
//  the edge. The swell is a constant push and rolls with the outline it pushes.
//
//  TWO: the push is along the outline's NORMAL, not radially from its centre.
//  Radially, a point high on the flank is mostly sideways from the centre, so
//  only part of a 10.50 mm swell arrives in x - it measured 68.22 where 71.83
//  was wanted. rse_poly runs counter-clockwise, so the outward normal of a
//  tangent (tx, ty) is (ty, -tx).
//  THREE: ONE outline, offset along its own normals. Every layer used to be a
//  separately built superellipse, narrowed by 2*ins with its corner radius
//  narrowed by ins - and shrinking the corner MOVES EVERY VERTEX ALONG THE
//  FLANK. Vertex j sat at a different y on each layer, so it sampled the swell
//  at a different place, and the swell shrank by about what the inset gave
//  back: a 4.00 mm facet cut at 55 degrees delivered 0.47 mm of run instead of
//  2.80 and came out at 83 degrees, which is an arris with extra steps.
//
//  Offsetting one outline keeps vertex j on one ray for the whole depth, so the
//  swell is genuinely constant and the inset is genuinely the inset.
function pebble_poly(ins, sites, q) =
    let (ref = rse_poly(case_w, case_h, case_r, form_n, q),
         n = len(ref))
    [ for (j = [0 : n - 1])
        let (p  = [ref[j][0], ref[j][1] + case_cy],
             a  = ref[(j + n - 1) % n],
             b  = ref[(j + 1) % n],
             tg = [b[0] - a[0], b[1] - a[1]],
             tl = max(norm(tg), 1e-9),
             nx = tg[1] / tl,
             ny = -tg[0] / tl,
             s  = _swell_at(p, sites) - ins)
        [p[0] + nx * s, p[1] + ny * s] ];

//  The section profile, as INSET against distance from the nearer face.
//
//  Three regions, and the first of them is the one the render caught. The
//  version before this ran the smoothstep the whole way, and a smoothstep's
//  derivative is ZERO at its ends - so the flank left the face VERTICALLY and
//  met the flat cap at a 90-degree arris, 1782 edges of it all the way round.
//  It measured 90.0 degrees at worst. That is a curved rectangle, whatever the
//  middle of the section does.
//
//    d <= case_face_ch          a straight facet at case_face_ang off horizontal
//    up to the half-depth       the roll, taking what the facet left to zero
//    beyond                     full girth
function edge_profile(u) =
    let (t   = case_z1 - case_z0,
         d   = min(u, 1 - u) * t,
         mid = t * case_roll)
      d >= mid          ? 0
    : d <= case_face_ch ? case_soft - d / tan(case_face_ang)
    : (case_soft - case_face_run)
      * (1 - sstep((d - case_face_ch) / (mid - case_face_ch)));

//  The layer heights are NOT evenly spaced: a facet 4.00 mm tall sampled on an
//  0.85 mm grid comes out as five steps, which is a stair, not a chamfer. Both
//  ends of the facet get a layer of their own, so it renders as one ruled
//  surface, and the rest of the depth is divided evenly.
function body_levels(nm) =
    let (a = case_z0 + case_face_ch, b = case_z1 - case_face_ch)
    concat([case_z0, a],
           [ for (i = [1 : nm - 1]) a + i * (b - a) / nm ],
           [b, case_z1]);

module full_body(nm = 40, q = 32) {
    na = 4 * (q + 1);
    sites = boss_sites();
    zs = body_levels(nm);
    nz = len(zs) - 1;
    layers = [ for (z = zs)
                 pebble_poly(edge_profile((z - case_z0) / (case_z1 - case_z0)),
                             sites, q) ];
    pts = [ for (i = [0 : nz], j = [0 : na - 1])
              [layers[i][j][0], layers[i][j][1], zs[i]] ];
    // wound as rse_soft winds: clockwise seen from OUTSIDE
    sides = [ for (i = [0 : nz - 1], j = [0 : na - 1])
                [ i*na + j, (i+1)*na + j,
                  (i+1)*na + (j+1)%na, i*na + (j+1)%na ] ];
    bottom = [ for (j = [0 : na - 1]) j ];
    top    = [ for (j = [na - 1 : -1 : 0]) nz*na + j ];
    polyhedron(points = pts, faces = concat(sides, [bottom], [top]),
               convexity = 12);
}
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

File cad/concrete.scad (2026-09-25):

//  concrete.scad - a cast concrete jacket for the cYbErDeCk, and the two-part
//  mould that produces it.
//
//  COORDINATES. Everything here is built SHOW FACE DOWN, because that is how it
//  is cast: z = 0 is the outer front face, lying on the mould's face plate, and
//  +z runs back toward the open end you pour into. That is the opposite of
//  cyberdeck.scad, where +z runs toward the front. The skeleton is therefore
//  mirrored into this frame rather than the frame being bent to suit it.
//
//      z = 0                       outer show face (against the face plate)
//      z = conc_t                  skeleton's own front face
//      z = conc_t + body_t         open back - screed flat, back plate goes on
//
//  PARTS
//      jacket        the concrete itself. Not printed - rendered so its volume,
//                    mass and wall can be measured before anyone mixes a bag.
//      mold_face     face plate: forms the show face and carries the aperture
//                    blockouts. Print this face UP and smooth it; its finish is
//                    the object's finish.
//      mold_collar   the four sides, drafted. Bolts down onto the face plate.
//      assembly      everything in place, for looking at.

include <parameters.scad>
use <lib/util.scad>
use <cyberdeck.scad>

part = "jacket";
$fn = 64;

//  Mould footprint. Defined early because the side-feature cores are sized
//  from it.
fw = conc_w + 2*conc_draft + 2*conc_mold_wall + 2*conc_flange;
fh = conc_h + 2*conc_draft + 2*conc_mold_wall + 2*conc_flange;

// ---------------------------------------------------------------------------
//  The outer form: a drafted loft, chamfered at the show face.
//  Three sections hulled. All convex and monotonically growing, so the hull is
//  exactly the loft and not an approximation of it.
// ---------------------------------------------------------------------------
module conc_outer(grow = 0) {
    c = conc_chamfer;
    hull() {
        rse_plate(conc_w - 2*c + 2*grow, conc_h - 2*c + 2*grow, 0.01,
                  max(conc_blend - c + grow, 1.0), form_n);
        translate([0, 0, c])
            rse_plate(conc_w + 2*grow, conc_h + 2*grow, 0.01,
                      conc_blend + grow, form_n);
        translate([0, 0, conc_stack - 0.01])
            rse_plate(conc_w + 2*(conc_draft + grow), conc_h + 2*(conc_draft + grow),
                      0.01, conc_blend + conc_draft + grow, form_n);
    }
}

//  The printed chassis's outer envelope, mirrored into cast coordinates. This
//  is the surface the concrete forms against on the inside, so it is taken from
//  the same rse_soft call the chassis itself uses - not re-described.
module skeleton_envelope(grow = 0) {
    translate([0, 0, conc_t + body_t]) mirror([0, 0, 1])
        rse_soft(body_w + 2*grow, body_h + 2*grow, body_t,
                 corner_blend + grow, form_n, edge_soft, edge_roll);
}

//  One aperture through the concrete face: widest at the show face so the
//  blockout pulls, and standing conc_aper_relief proud of the plastic opening
//  so the reveal reads as a deliberate plastic edge.
module conc_aperture(w, h, blend, ramp) {
    r    = conc_aper_relief;
    land = conc_t - ramp;          // straight wall left at the aperture edge
    union() {
        // the ramp, opening outward toward the show face
        hull() {
            translate([0, 0, -0.01])
                rse_plate(w + 2*(r+ramp), h + 2*(r+ramp), 0.01,
                          blend + r + ramp, form_n);
            translate([0, 0, ramp])
                rse_plate(w + 2*r, h + 2*r, 0.01, blend + r, form_n);
        }
        // the land, straight through to the plastic
        translate([0, 0, ramp - 0.01])
            rse_plate(w + 2*r, h + 2*r, land + 0.02, blend + r, form_n);
    }
}

//  mirror([0,0,1]) flips Z ONLY - X and Y are unchanged by it. An earlier
//  version negated Y here as well and put the display aperture over the
//  keyboard. Cast coordinates share the chassis's X and Y exactly.
module conc_apertures() {
    translate([0, board_bay_cy, 0])
        conc_aperture(display_aper_w, display_aper_h, aper_blend_display,
                      conc_aper_draft);
    // The keyboard gets the deep ramp; nothing reaches into the display.
    translate([0, kbd_bay_cy, 0])
        conc_aperture(kbd_aper_w, kbd_aper_h, aper_blend_kbd,
                      conc_kbd_relief);
}

// ---------------------------------------------------------------------------
//  SIDE FEATURES. The jacket would otherwise bury the USB-C and microSD
//  tunnels and the keyboard service window under 7 mm of concrete.
//
//  They cannot be moulded by a straight pull - a hole in a side wall is an
//  undercut relative to the +Z demould direction - so each is formed by a LOOSE
//  CORE: a printed plug pushed in through the collar wall until it butts
//  against the skeleton, withdrawn sideways before the collar is lifted.
//
//  The buttons and both microphones are NOT here. They live on the top edge,
//  and burying them would mean lengthening every button cap. The jacket simply
//  stops short of that edge instead, leaving a plastic control strip along the
//  top - see conc_top_open.
pcb_back_z = z_front_inner - board_w_display_front;

//  [x-sign, y, z_chassis, opening h (along Z), opening w (along Y)]
function core_sites() = [
    [ 1, board_cy + usbc_off_y, pcb_back_z + usbc_w_centre, usbc_open_h, usbc_open_w],
    [ 1, board_cy + tf_off_y,   pcb_back_z + tf_w_centre,   tf_open_h,   tf_open_w  ],
    [-1, kbd_bay_cy + kbd_pocket_h/2 - kbd_access_from_edge - kbd_access_w/2,
         z_back_inner + kbd_access_above_floor + kbd_access_h/2,
         kbd_access_h, kbd_access_w ] ];

//  A core, in cast coordinates. len runs outward from the skeleton flank.
module core_body(sx, y, zc, oh, ow, len, grow = 0) {
    translate([sx * (body_w/2 - 0.5), y, conc_t + body_t - zc])
        rotate([0, sx * 90, 0])
            rbox(oh + 2*grow, ow + 2*grow, len, 1.2);
}

module side_features(grow = 0) {
    for (c = core_sites())
        core_body(c[0], c[1], c[2], c[3], c[4], fw/2, grow);
}
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

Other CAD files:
cad/cyberdeck.scad
cad/render_assembly.scad

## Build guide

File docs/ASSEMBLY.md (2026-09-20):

# Assembly

Read this before printing. The RLCD panel is fragile and must never be used as
leverage while fitting a cable, a cell or a printed part.

> **This design has not been built.** All **113** automated checks pass, but
> nobody has held these components against a printed chassis. Print the
> **chassis alone** first, offer the board and keyboard up to it, and check the
> four measurements in
> [DATUMS.md](DATUMS.md#measure-these-before-a-final-print) before committing to
> a full set.

## Bill of materials

### Printed

| Part | Qty | Mass (PLA) | Notes |
|---|---|---|---|
| `chassis` | 1 | ~53 g | front face down |
| `backplate` | 1 | ~58 g | cowl up |
| `buttons` | 1 | ~0.5 g | printed as one sprue |
| `cover` | 1 | ~60 g | **variant 2 only** — inner face up, no supports |

### Hardware

| Item | Qty | Notes |
|---|---|---|
| Waveshare ESP32-S3-RLCD-4.2 | 1 | **not** an e-paper or other ESP32-S3 display board |
| Rii 518BT mini Bluetooth keyboard | 1 | not the K18, and not the RT518S |
| Ø5 × 2 mm N52 neodymium disc | 8 | **variant 2 only** — 4 in the shell, 4 in the cover |
| 18650 lithium cell | 1 | flat-top or protected, up to Ø18.6 × 69.0 |
| microSD card | 0–1 | FAT32 |
| Speaker with the MX1.25 2-pin lead supplied with the board | 1 | |
| M2 × 4 brass heat-set insert, Ø3.2 OD | 4 | Ø3.2 is the bore; a Ø4.0 insert is M3 |
| M2 × 6 countersunk screw, ISO 10642 | 4 | chassis ↔ back plate. See the note below — **not** M2 × 8 |
| M2.5 × 8 countersunk screw, ISO 10642 | 4 | into the board's own standoffs |

**On the two screw lengths.** Both are worked from the stack, not chosen:

- **M2 × 6, not longer.** The plate is 3.20 mm and the insert is 4.00 mm, so a
  6 mm screw engages 2.80 mm — 1.4 × diameter, comfortably past the 1 × minimum.
  M2 × 8 would put 4.80 mm past the plate into a 4.00 mm insert: the last
  0.80 mm spins in the relief below it and buys nothing.
- **M2.5 × 8 for the board, not the screws in the box.** The screws supplied
  with the board are 4.90 mm overall and countersunk, so through a 3.20 mm
  plate they leave **1.70 mm** biting the standoff — 0.68 × diameter, below the
  usual 1 × minimum, and these four screws carry the board and an 18650. At
  8 mm the engagement is 4.80 mm into a 7.00 mm standoff, 1.9 × diameter. Keep
  the stock screws for a test fit; do not ship on them.
| Adhesive foam gasket, 0.5 mm | 1 strip | around the display aperture |

## Printing

Defaults are set for a 0.4 mm nozzle at 0.2 mm layers. Wall thicknesses are
integer multiples of the extrusion width so every wall prints as solid
perimeters with no sparse infill in the load path — **do not reduce the
perimeter count**; that is where the strength is.

| Setting | Value |
|---|---|
| Nozzle | 0.4 mm |
| Layer height | 0.2 mm |
| Perimeters | 4 or more (walls are 8 extrusions thick) |
| Infill | 25 % gyroid |
| Material | PETG or ASA preferred; PLA is fine but softens in a hot car |
| Fuzzy skin | outer walls only, amplitude 0.15-0.25 mm, point distance 0.6 mm |

On finish: use a wood-, stone- or hemp-filled filament, or a matte PETG in a
warm neutral. Avoid gloss - it turns the rolled edges into hard specular lines
and undoes the edge treatment entirely. Fuzzy skin on the outer walls gives the
side surfaces a fine mineral grain while the front face, printed against the
bed, stays smooth where the hand and eye land. Leave the brass inserts visible.
See [DESIGN.md](DESIGN.md#material-and-finish).

Orientation:

- **chassis** — front face on the bed. The aperture draft then prints as a
  chamfer rather than a bridge, and the visible face gets the bed finish.
- **backplate** — flat face on the bed, cowl upward. That face is genuinely
  flat now: the keyboard keeper used to be a 0.25 mm raised pad here, which made
  it the only thing touching the bed and left 5777 mm² — 48% of the underside —
  printing over open air. The step lives on the chassis instead. See
  [DATUMS.md C-32](DATUMS.md#c-32--the-plates-bed-face-was-a-pad-over-open-air).
  The cowl's sides are
  vertical and its cap is a dome, so no supports are needed. The countersinks
  face the bed and print clean.
- **buttons** — caps down.

No part needs support material.

## Assembly

### 1. Strip the board

Remove Waveshare's moulded stand base and its fold-out kickstand. Both are
removable and neither is load-bearing: the four SMTSO-M2.5-7ET standoffs are
surface-mounted to the **PCB**, not to the base.

This is what makes the deck 2.75 mm thinner and 1.0 mm narrower than it would
otherwise be. Keep the parts — they are how you use the board on a desk again.

### 2. Heat-set the inserts

Four M2 inserts into the chassis bosses, driven from the **back**. Keep them
straight and flush. The bosses are **Ø6.6 around a Ø3.2 bore, 6.5 mm deep** —
the Ø7.4/Ø4.0 figures this step used to give were the M3 revision's and were
never updated. Let the insert melt in under its own weight rather than forcing
it, or the boss will split.

### 2b. Fit the magnets — variant 2 only

Eight Ø5 × 2 mm N52 discs, four in the chassis and four in the cover. Do this
with the chassis **front face down** on the bench.

Each shell station is a Ø6.0 access shaft running down to the back-plate
seating plane, ending in a ribbed pocket under the show face. Drop a disc into
the shaft, let it fall to the mouth of the pocket, and push it home with a 4 mm
rod until it bottoms on the 0.8 mm skin. It should take a firm push — eight
crush ribs close the 5.50 mm bore to 4.80, so the disc sees 0.10–0.30 mm of
interference depending where it falls in its own ±0.10 mm tolerance. If it
pushes in with no resistance at all, raise `magnet_rib_h`; if it will not start,
lower it. That one parameter is the whole adjustment.

The cover's four pockets are open on its **inner** face — press the discs in
flush. There is deliberately no plastic between the cover's discs and the
chassis's: the only gap in the magnetic circuit is the shell's own 0.8 mm skin,
which is what makes four small magnets enough.

**Polarity: every disc goes in the same way up.** Mark one pole before you
start and keep it consistent — all four shell discs facing out, all four cover
discs facing out. You cannot fit the cover backwards, so alternating polarity
would buy nothing and turn every disc into a coin toss.

Nothing is visible from outside when the back plate goes on.

### 3. Fit the button sprue

Drop the three caps into the top-edge apertures from inside. The retaining
flange seats in the counterbore behind each aperture, so nothing stands proud
of the wall's inner face, and the board stops them falling in once it is
fitted. Only the plungers go past the wall, and they are offset so they land on
the switch bodies and miss the PCB's edge entirely. The free travel — **0.60
mm** — comes from the counterbore being 1.00 mm deep and the flange 0.40 thick,
not from the 0.50 mm the board leaves behind the wall. See
[DATUMS.md O-08](DATUMS.md#o-08--the-button-sprue-did-not-fit-behind-the-wall--closed) for why it is that tight.

The three switches are PWR, BOOT and KEY. **Which is which is not established** —
see [DATUMS.md O-03](DATUMS.md#o-03--which-switch-is-pwr-which-is-boot-which-is-key).
All three apertures are identical, so the enclosure does not care; label them
once you have found out.

### 4. Gasket and seat the display

Run the 0.5 mm foam gasket around the inside of the display aperture. It absorbs
the tolerance stack and isolates the panel from shock.

Lay the chassis face down. Lower
the board in **display first**, holding the PCB — never the panel. Check the
three buttons and both microphone ports line up with their apertures.

### 5. Fit the keyboard

Drop the keyboard into the lower bay from behind, key side forward. It is
captured by the front-face lip on all four edges.

It will feel tight, and it is meant to. Eight half-round locating ribs — four
on the long walls, four on the short ones — take the play out of the pocket so
the keyboard cannot slide and the front lip stays even all the way round. They
are tapered at the entry end; push the keyboard in square and it will seat.

The power switch and the charging port must fall within the service window on
the **left** side, as you look at the front of the device. There is only one
window, because everything that needs reaching is on that one short edge and
the keys only read one way up. If they end up on the right, the keyboard is in
upside down.

### 5b. Fit the cover — variant 2 only

Offer it up square and let it go from a millimetre out; the two register
platforms find their apertures and pull it straight. To remove it, get a thumb
into the scallop on the top edge and peel — do not try to slide it off.

The platforms, not the magnets, are what stop it sliding. Four pairs make about
15 N of pull across the 0.8 mm skin but only about 3 N of shear, which is a
fraction of what a bag strap can apply; the platforms carry all of it.

### 6. Connect the speaker

Plug the MX1.25 lead in **before** the back plate goes on, and route the cable
so nothing can pinch it.

### 7. Fit the cell

Insert the 18650 with the polarity shown on the Waveshare holder. It will stand
proud of the PCB — that is expected; the cowl covers it.

### 8. Close it up

Lower the back plate bottom-edge first so the tongue enters the groove in the
chassis bottom wall, then swing the top down. The plate's flat inner face
should meet the keyboard — the 0.25 mm step that holds it forward is a ledge in
the chassis bay now, not a pad on the plate — and the cowl should clear the
cell.

The tilt is not optional and it is not large. Searched as a rigid-body motion
against the rendered chassis — rotation about X plus translation in Y and Z,
every configuration checked on fourteen cross-sections — the plate needs about
**1.5°** of tilt and a **1.0 mm** slide along −Y to get the tongue under the
groove's lip; flat-on it is 0.70 mm too tall for the opening. With the board and
the keyboard already in the chassis the clearance path needs up to **7.5°**,
because the cowl has to swing over the 18650. Removal is the same path
reversed, and the board, cell and plate do come out as one bolted module.

If it does not sit flush, **stop** and find out why rather than pulling it down
with the screws.

Fit the four **M2 × 6** countersunk screws and tighten evenly, just until the
plate is seated. (This step read M2 × 8 while the bill of materials read M2 × 6
and explained why; 6 is the right one.)

### 9. Bolt the board to the plate

Four **M2.5 × 8** countersunk screws, from outside the back plate, up into the
board's own SMTSO standoffs. They are what carries the board and the cell, and
they are the reason the board, cell and plate come out as one module.

Drive the two nearest the cowl first: they sit 0.60 mm below the 18650 holder
and are the tightest pair on the plate.

### 10. Check before power-on

- all three buttons move freely and spring back
- no cable is trapped
- the microSD slot and USB-C port are reachable
- nothing rattles

Then follow the SolarOS installation instructions from the
[upstream project](https://github.com/nilseuropa/solar_os), or flash whatever
firmware you prefer.

## Rigging

The four M2 back-plate screws are the accessory mounting points. They thread
into brass, not plastic, so they are the strongest anchors on the device.

Fit **M2 × 12** in place of M2 × 6 and clamp a bracket, strap yoke or stand
clamp under the heads. The bracket has to be at least **2.3 mm** thick: the
insert bore is 6.5 mm deep under a 3.2 mm plate, so a 12 mm screw with nothing
under its head bottoms in the bore before it is tight. `accessory_pattern()` in `cad/cyberdeck.scad` prints the
hole pattern to drill a bracket to match.

There is deliberately no 1/4"-20 socket. The reason is in
[DESIGN.md](DESIGN.md#accessory-mounting-the-four-screws-are-the-rig-points).

## Servicing

Four screws release the back plate, and the board, cell and plate come out as a
module — verified as a rigid-body path, not merely as a clearance.

**The keyboard comes out of the open bay, not through the finger hole.** The
Ø19 → Ø13 hole in the back plate is inherited from the reference, where it
pushes a keyboard out of a separate tray. Here it cannot eject anything: with
the plate on, the keyboard is captured by the front-face lip on all four edges
and pushing it forward does nothing; with the plate off, the hole has left with
the plate. It survives as finger access to break the keyboard free of its
pocket once the plate is off, and that is all it does. Lift or tip the keyboard
out of the open bay.

Changing the cell means removing the back plate — the cowl is integral. That is
a deliberate trade for robustness; see
[DESIGN.md](DESIGN.md#the-battery-has-to-stick-out-so-it-was-made-useful).

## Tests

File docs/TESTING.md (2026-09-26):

# Testing the deck

A pass over everything the device does. Each step is one thing, and each says
what you should see — if you don't see it, that's the bug, and the step number
is enough to report it.

Ctrl+Enter runs the line the cursor is on. Ctrl-O comes back from any output
page. Ctrl-L and Ctrl-J walk between documents.

### Driving it from a terminal, and the one trap in it

Every step here works over the USB cable with no keyboard paired: **CR is Enter and LF
is Ctrl+Enter**, so a terminal that sends CR opens a line and a script that sends `\n`
runs one. Bursts are fine — a 26-character line typed as one write arrives intact.

**Ctrl-O is a toggle, not a "go back".** From the document it goes *to* `+out`; from
`+out` it comes back. And a command only moves you to `+out` if it printed more than one
line, so where Ctrl-O lands depends on what the last command was. A script that sends it
unconditionally ends up typing into the output pane and running whatever line the cursor
happened to be on — which looks exactly like dropped characters, and was diagnosed as
dropped characters twice before anyone read the pane. Track the pane from what the deck
says about it: it logs `buffer 3 '+out' selected` when it moves you.

## 1. It boots

Power on. You should see **KILROY** appear a letter at a time, a rule sweep
under it, then a line of numbers — documents and free memory — then the editor.

If the screen stays blank, a button is held down: every reset reports
`boot:0x22 (DOWNLOAD)` when GPIO0 is low. Release it and power-cycle.

## 2. The guide plays

Ctrl-L until the status bar reads `guide`. Run each `>` line from the top.
By `>play` you should have an accented kick, a soft hat whose last hit comes and
goes, a tied bassline in D minor, two held chords on the pad, and a filter sweep.

An inverted bar should sweep along each pattern line in time with the sound,
covering the whole step that is sounding — all of `x%50`, all of a chord.

## 3. Editing while it runs

With it still playing, change a character in the kick line and Ctrl+Enter.
It should change on the next bar without stopping.

Then Ctrl+Enter on that same line **without touching it** — the lane goes
silent. Again — it comes back.

## 4. Probability

```
>hat x%3x%3x%3x%3
>hat x%97x%97x%97x%97
```

Near-silence, then near-constant. `>lanes` prints each line exactly as it was
compiled.

## 4b. How much, how long, all at once

```
>send mon on
>kick 9...5...
>bass 0__.3...
>pad [0,2,4]...
>play
```

The console shows each note with its velocity and the time it went out. The kick
alternates 127 and 71. The bass's first note is held two extra sixteenths — its
off comes about 420 ms after its on at 124 bpm, where the next is about 180. The
pad plays three notes on one timestamp. `>send mon off` to stop the log.

## 4c. Mistakes are refused

```
>hat x...x...x;..
>kick X...x...
>hat [x.x.
```

Each is refused in one line on the status bar — *';' is not a step*, *X is gone: 9
is loud*, *'[' is never closed* — and the character is boxed in the document until
you edit. Whatever was playing keeps playing.

## 5. Time ratios

```
>hat x.x.x.x. /2
>hat x.x.x.x. *2
```

Half speed, then double. The kick keeps its own tempo — each lane divides the
clock separately.

## 6. Mute and solo

```
>mute hat bass
>solo kick
>mute
```

Several at once. Bare `>mute` or `>solo` brings everything back.

## 7. USB MIDI

```
>usb on
```

The deck reboots and comes back as one USB device carrying MIDI, the console
and the keyboard. In a DAW, pick **cyberdeck usb** and record-arm a track with
a drum rack — drums are General MIDI on channel 10, so the kick lands on the
first pad.

`>usb off` to come back. A power cycle also always returns to serial: the mode
lives in RTC memory, so there is no setting that can fail to save.

## 8. MIDI clock

```
>sync on
```

In Ableton: Preferences → Link/Tempo/MIDI, enable **Sync** on the cyberdeck
input, set the transport to External.

## 9. Network

```
>host deck
```

The status line asks for a password: type it and press Enter. It shows a star
for each character and **never enters the document** - a password on a line would
be journalled, mirrored to the card and copied to the DGX. Under eight characters,
or none, and the deck hosts an open network and says so. Esc stops without
starting anything. The deck becomes a Wi-Fi network at `192.168.4.1`. Join it from
a laptop.

Or join an existing one:

```
>wifi <ssid>
>wifi
```

It asks for the password the same way. The second command shows the address once
it has one. Credentials are remembered **as soon as Enter is pressed**, in NVS and
never in a document, and re-joined at every boot. `>wifi forget` clears them.

A password still typed on the line the old way - `>wifi home hunter2` - is
refused, and cut from the line before autosave can keep it.

## 10. OSC out

On the laptop:

```bash
python3 tools/osc_listen.py
```

On the deck:

```
>osc <the laptop's ip> 9000
>play
```

You should see `/deck/step` with the bar position and `/deck/<lane>` for every
hit, by lane name.

## 10b. OSC in

On the deck, with it on the same network as the laptop:

```
>osc in 9000
>knob1 = knob
>pad1 = pad
>route cut knob1
>route kick pad1
>play
```

On the laptop:

```bash
python3 tools/osc_send.py <the deck's ip> 9000 /deck/knob1 0.5
```

```bash
python3 tools/osc_send.py <the deck's ip> 9000 /deck/pad1
```

`>lanes` shows `knob1 knob  64` and the last two parts of the laptop's address; the
filter moves, and the kick plays on the next step after the pad. A phone app that
sends OSC works the same way: a fader from 0 to 1 on `/deck/knob1`. **A phone has not
been tried** — two decks have, and this script from a laptop on a home network: every
value right, 22 ms median from sending to the filter moving.

## 11. Visuals, in the same document

```
>kick 9...x...9...x...
>bass 0...5...3...7...
>echo 8
>noise 2.4.2.4.
>move d
>route disc kick
>route grow disc
>play
```

**A drawing primitive is a lane, exactly like a drum.** `>disc 9` and `>kick x...`
are the same sentence with different destinations, so everything that works on
one works on the other: a bare name drops it, re-running an unchanged line mutes
it, `/2` halves it, and `>lanes` lists them together. There is no `viz` keyword —
it was an alias during the collapse and it is gone.

The lower half of the screen becomes a live frame inside a stroked border,
advancing on the same clock as the music. `>split on` and `>split off` are
explicit; a bare `>split` toggles. `>split 8` gives the picture eight rows.

**Three sources and five operators.** A source puts ink down; an operator bends
whatever the sources drew. That is the whole design — complexity comes from
combining them, not from having more of them.

| draws | |
|---|---|
| `noise` | a random field |
| `disc` | a filled circle from the centre |
| `ramp` | a gradient along an axis |
| `grid` | a lattice, from a frame to a dense mesh |

| bends | |
|---|---|
| `echo` | keeps the last frame, one ink step dimmer — **trails** |
| `move` | shifts the frame, wrapping |
| `warp` | displaces lines along an axis — waves, glitch |
| `shake` | tears lines sideways at random — glitch, where `warp` bends |
| `grow` | dilates: every mark blooms into its neighbours |
| `thin` | erodes: edges eat inward. `grow` + `thin` is an outline |
| `flip` | inverts the whole frame — the cheapest strobe there is |
| `tile` | repeats the frame across, 1–4 copies |
| `fold` | mirrors it, 1–3 folds — kaleidoscope |

**The picture is drawn with our own glyphs, not with punctuation.** Codepoints
128–155 are a tile library generated by `tools/font_tiles.py` and built into both
faces: nine tones (an ordered dither from nothing to solid), four sparkles, half
blocks, a diamond, a disc, a ring, diagonals, and four quadrant arcs that tile
2×2 into one circle twice the size. Nine even tones are what let `echo` actually
fade — `@ # * : : . .` and gone, eight stages — where six punctuation marks
jumped straight from `:` to nothing. `>frame` still sends plain ASCII over OSC,
since the tiles mean nothing to a receiver.

**Patterns nest.** A bracket subdivides the step it occupies, to any depth:

```
>kick x..[xx]          the last step becomes two half-steps
>hat  [xxx]...         a triplet in the first step of four
>hat  [xx][xxx]        two against three, in one bar, from one line
>kick x.[x[xx]].       the second of a pair splits again
```

**Patterns alternate.** `<a b>` plays a different member each bar:

```
>kick x...<x .>...     a hit on the two, every other bar
>hat  x.x.x.x.<[xxxx] x>...  a roll on the 9th step, every other bar
>bass 0...<3 5>...     the value changes
>snare <x%15 x%90>     and so do the odds
>disc  <9 3>           pictures alternate too
```

A lane's bar is its own length — one character at the top is one sixteenth — so
`<>` swaps once per pass of the line it is in, not once per four beats. Angle
brackets pick one; square brackets subdivide. They compose in either order:
`[x<x .>]` is a doubled step whose second half comes and goes, and `<[xx] x>` is
two hits one bar and one the next. Groups of different length run their own
cycles — `<0 1><2 3 4>` takes six bars to repeat — and a group inside a group
advances only when it is chosen: `<0 <1 2>>` plays 0 1 0 2.

Probability is `%`: `x%15` is a fifteen-per-cent chance on that step, and `[..]%50`
puts odds on a whole group, multiplying with any inside it. Notes that start
together share one roll, so a chord with odds plays whole or not at all. Odds
travel with the alternative, so `x%15<3%20 5%80>` keeps each one's own. The
bracket was spent on the parameter before; a group had the better claim on it.

Nesting is resolved when the line compiles, so a nested lane costs the clock
nothing. What cannot fit is refused rather than shortened. A five- or seven-way
split keeps exact time — `>hat [xxxxx]...` lands its bar on the kick's, every
bar.

**A digit is always how much: 0 none, 9 full.** In every primitive. A `u`, `d`,
`l` or `r` is which way, either in front of the pattern (`>ramp u 4.6.9.6.`)
or as a step of it (`>move d....d...`). Speed is the pattern, so `/2` and
`*2` halve and double a visual lane exactly as they do a drum.

Old shapes are combinations now. Rain is `noise` + `move d` + `echo`. A bar is
`ramp`. A wave is `ramp` + `warp`. Start with `>echo 9` and then add a
source — that one line is the difference between a blinking shape and an
animation.

**Run a visual line again to mute it**, exactly as a drum lane works. Running it
a third time brings it back. An empty pattern (`>disc`) removes the lane
outright and takes its routing with it.

`>route disc kick` makes the disc **fire on every kick**, at the size of that
hit's velocity. Routing is *when* as well as *how much*: a routed lane ignores
its own pattern and follows its source. Put `>echo 8` above it and the pulse
gets a tail. **A part of a primitive is a lane too.** `disc:x` is the circle's position
across the frame, and it is a lane like any other — it has a pattern, it
alternates, it nests, and it can be routed:

```
>disc      4                   a small circle
>disc:x    0..3..6..9..        swept across
>disc:y    <2 7>               and up and down, bar to bar
>route disc:x bass             or driven by the bass note
>disc:2:x  9...0...            the second circle, its own path
```

The old spellings — `disc[x]`, `disc2` — are answered with the new ones rather than
played.

## 11b. The names are yours

```
>conga = note 63
>conga x..x..x.
>kick = note 35
>conga =
```

The first two play note 63 on channel 10. The third moves the kick that is already
playing to note 35 — the next hit is 35. The last forgets the name and silences its
lane. `>help` lists every name there is. `>bpm = note 3` and `>disc = note 3` are
refused: a name cannot be a command or a picture.

```
>send mon on
>bass 0...
>bass:oct <2 4>...
>bass:vel 9...3...
>play
```

The bass alternates D2 and D4 bar by bar, at 127 then 42. `>bass:oct` alone drops
the part and the bass goes back to octave 2. A lone `<2 4>` would change every
sixteenth — a lane's bar is its own length — and under a four-step bass it reads 2
every time.

`>kick x..u` is refused and the `u` boxed: only `move`, `warp`, `ramp` and `turn`
have a way.

## 11c. Counts, ends and cues

```
>send mon on
>kick x...
>intro = note 60
>verse = note 62
>intro x.x. !2
>verse 9... !2
>route verse intro:end
>route crash intro:end
>play
```

The intro plays two passes — four hits — and `>lanes` then reads `done`. On the next
kick the verse starts and the crash hits, all three on one timestamp; the verse plays
its two passes and reads `waits`. `>stop` then `>play` plays the intro again from the
top. Typed while playing, a counted line waits for its own downbeat.

`x` and `y` are the only parts for now — deliberately short, or it becomes a flag
grammar. 0 is the left or top edge, 9 the right or bottom, and the shape's centre
goes there.

**Anything that plays can drive anything else**, and chains work:

```
>route disc kick      the circle fires on the kick, at that hit's velocity
>route grow disc      the bloom follows the circle
>route warp cut       the bend follows the filter sweep
```

`kick → disc → grow` is two hops across three kinds of destination. Routing a
primitive that has no lane yet creates it, so `>route grow disc` needs no pattern
written first. A lane cannot follow
itself (it would re-trigger for ever), and routing to a name that is not a lane
yet says so rather than going quietly silent. Unroute with `>route disc`.

`>lanes` now lists the visual half as well — which primitives are live, what
each follows, and a leading `-` for muted. If a route looks dead, that listing
is where to look first.

## 12. ASCII frames

Make a document with some ASCII art, then:

```
>frame
```

The listener prints it between `--- frame ---` markers. Editing the drawing and
running `>frame` again is the whole of visual coding on this device.

## 13. SSH

**Tested against real OpenSSH servers, through the login and a command's reply** -
see [NETWORK.md](NETWORK.md), *SSH, as built*. Use a throwaway account on the laptop,
never a real password, as docs/NEXT.md §10 asks. Turn on Remote Login (macOS: Settings → General → Sharing). Then with the
deck on the same network:

```
>ssh you@192.168.1.42 ls
```

The status line asks for the password; it never goes on the line. The session
runs beside the editor - you can keep typing - and when it ends the reply is shown
in `+out`. Ctrl-O comes back.

**The host's key is kept the first time** and printed as `ssh-keygen -lf` prints
it. Check it by eye against the laptop's own, from the key type the deck names:
the deck cannot use ed25519 host keys, so it will be the ECDSA or RSA one:

```
ssh-keygen -lf /etc/ssh/ssh_host_ecdsa_key.pub
```

From then on a different key is **refused before any password is sent**. If you
changed the key yourself, `>ssh forget 192.168.1.42` and connect again.

What was exercised, 2026-09-25, on two decks with one hosting a test network: an
address nobody answers reports `no answer in 5 seconds` at 5.0 s while the editor
keeps its 194 turns a second; a closed port reports `connection refused`.

## 14. Battery

```
>battery
```

Unplug USB, run it again. The channel whose voltage **moved** is the cell.
Then:

```
>battery use 4
```

Persistent, no reflash. A four-cell bar appears at the right of the status row.
If the divider isn't 2:1, `>battery use 4 30` for 3:1.

## 15. Settings survive

Ctrl-L to `boot`. It holds ordinary commands that run at startup:

```
>bpm 124
>scale dmin
>density dense
```

Edit it, power cycle, and they take effect. There are two densities and the
panel decides that, not taste: `>density low` is 30 columns of the chunky
12x24 face, `>density high` is 60 columns of 6x12. Cell height has to be a
multiple of 12 and cell width has to be even, so no legible middle size exists
— an 8x24 face was built, read thin, and was thrown away.

`high` is the one to use with the split: 60 columns leaves 39 for code with the
view taking a third, so pattern lines stop wrapping. `>split 12` or
`>split 20` sets the view width directly.

## 16. An ensemble

Two decks, or ten. One leads, the rest follow:

```
   deck A          deck B
   >sync lead      >sync follow
   >play           >play
```

**No network, no password, no router** — the decks talk to each other directly over
ESP-NOW. `>sync` on a follower reports how far off it is and how good the link is:

```
following, 1 other deck
off by -39 us, 110 packets
best trip 2459 us, 12 skipped
```

Typically a few hundred microseconds, occasionally up to about 2 ms — a pulse at
124 bpm is 5040 µs. The leader's tempo is followed at once; `>bpm 96` on the leader
and the followers change with it. `>sync alone` to play by yourself again.
Outputs stay independent: deck A can drive a drum machine over `din` while deck B
drives a projector over `osc`, from the same clock.

See [NETWORK.md](NETWORK.md) for how it works and what it was measured at.

## 17. MIDI with no computer

```
>din 17
>kick x...x...x...x...
>bpm 124
>play
>din
```

`>din` reports bytes actually written — `din GPIO17, 80 bytes sent / the wire is
busy` means real MIDI left the pin. That is the only transport that needs no host
at all, so it is the one that drives an SP404, a eurorack MIDI-to-trigger module,
or anything else with a MIDI IN.

**It needs a resistor loop before you trust it** — a MIDI output is a current
loop, not a logic level. See [HARDWARE.md](HARDWARE.md). `>din off` stops it.

**Fixed: the deck used to hang leaving USB MIDI mode.** `esp_restart()` never
completed from that mode — it runs shutdown handlers and TinyUSB's teardown
deadlocks — so `>usb off` saved every document and then stopped dead, and only a
PWR hold recovered it. It reboots without the handlers now, and the `>usb on` →
`>usb off` round trip works. See [OS.md](OS.md).

Still open: **`>flash now` from USB MIDI mode** has the same deadlock and cannot
use the same fix, because it needs a CPU-only reset to preserve
`FORCE_DOWNLOAD_BOOT`. Do `>usb off` first, then `>flash now`.

Also worth knowing: **`>usb on` reboots, and the reboot loses the lanes, the
tempo, `sync` and `play`** — the document survives but nothing is re-run. Put the
whole piece in a document and `>run` it after the reboot, or put `>usb on` in
`boot` so the deck comes up that way.

The other transports all need something else to be the host: `>usb on` makes the
deck a USB MIDI *device* (so: a computer or tablet), `>send ble on` needs a BLE
MIDI host, `>osc <ip> <port>` needs something listening on the network.

## 18. It recovers

If it crashes it now reboots in about two seconds and the screen says
`crashed Nx - unplug to clear`. That counter clears on a real power cycle:
unplug and hold PWR, since the battery means unplugging alone doesn't
power it down.

## Known gaps

- `>flash now` doesn't reach the bootloader while in USB MIDI mode. Use the
  BOOT button to reflash from there.
- `>lanes` shows a pattern from its compiled form, so spacing you typed for
  readability isn't echoed back.
- No SSH key auth yet — password only, asked for and never on a line.
- An SSH session has never been run against a real server: see §13.

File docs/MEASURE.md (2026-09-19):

# Caliper checklist

For someone holding the actual Waveshare ESP32-S3-RLCD-4.2 and Rii 518BT.

Everything in this project is asserted consistent and confirmed against a
working third-party design. **Neither of those is the same as being right.**
Each measurement below closes a specific open item, and the list is ordered by
what it costs you to be wrong.

Record what you get — including where it agrees — and the numbers go back into
`cad/parameters.scad` with `[MEASURED]` provenance.

---

## 1 · Keyboard thickness — **the one with no slack**

> The pocket is **11.00 mm**. The body is 10.20 nominal, 10.60 at the assumed
> upper band. That leaves **+0.40 mm**, and it is the only axis in the design
> sitting exactly on its assertion.

Measure **twice**, because the ambiguity is the whole point — the manufacturer's
drawing says `10.2mm/0.4inch` and never says what it is measured to:

| | Where | Expect |
|---|---|---|
| **a** | across the **moulding only**, at a corner clear of any key | ~10.2 |
| **b** | from the base to the **crown of a keycap**, mid-board | 10.2 – 10.6 |

Lay it face-down on glass and measure to the highest keycap for **b**. Include
the rubber feet if it has them, separately.

**If b > 10.60** the pocket is too shallow and `kbd_depth` must grow, which
grows the whole deck. **Tell me before printing.**

## 2 · 18650 holder protrusion past the standoff seating plane

> Currently **8.20 mm**. This, not the cell diameter, is what the battery cowl
> has to swallow. If it is under-measured the back plate will not close.

With the board face-down on a flat surface **resting on its four standoffs**,
measure from that surface to the deepest point of the battery holder. The
standoff tips are the datum, not the PCB.

## 3 · Board stack: display glass front → standoff seating plane

> Currently **10.75 mm**, in an 11.00 mm pocket, the 0.25 taken up by squeezing
> a 0.5 mm foam gasket.

Same setup: board resting on its standoffs, measure to the front face of the
display glass. If this is over 10.75 the gasket squeeze disappears and the
display is trapped against the front panel.

## 4 · 18650 holder footprint — **actively disputed, you can settle it today**

> `batt_bay_w × batt_bay_h` is **77.80 × 22.10**. A re-derivation from
> Waveshare's own CAD says the second figure should be **21.10**.

Measure the holder's footprint on the PCB back face, across the mounting flange
(the wider of the two dimensions), along the board's short axis.

**21.10 or 22.10?** One millimetre, and it drives a real cut in the back plate.

## 5 · Keyboard outline

> **108.5 × 58.2 mm**, with an *assumed* ±0.30 moulding tolerance that no
> document states.

Measure **across the flats**, not corner to corner, at three places per axis.
The pocket is 109.85 × 59.15 with locating ribs closing it to 108.95 × 58.65,
so anything up to 108.80 × 58.50 is fine.

## 6 · Keyboard corner radius

> **6.5 mm**, band 5.9 – 7.0. It derives the front aperture's corner, so getting
> it wrong either eats the opening or loses the retaining lip.

Easiest method without radius gauges: push the keyboard into an inside corner
(a steel square, or the corner of a table). **The distance along each edge from
the square's corner to where the keyboard's edge stops being straight IS the
radius.** Do it on two adjacent edges; they should agree.

## 7 · PCB outline, and confirm the stand base comes off

> **92.50 × 69.10 mm.** The circulating "70.1" is the *removable moulded stand
> base*, which overhangs the PCB by 1.00 mm on one long edge.

Measure the bare PCB with the stand base removed. Confirm the base and its
kickstand detach and that the four SMTSO-M2.5-7ET standoffs are soldered to the
**PCB**, not to the base — the whole thinness argument rests on that.

## 8 · Mounting pattern

> **85.50 × 62.10 mm.** Already established three ways and agreeing to
> 0.001 mm, so this is confirmation rather than discovery — but it is thirty
> seconds and everything else hangs off it.

Centre to centre, diagonally opposite holes, both diagonals.

## 9 · Side buttons and microphones — height below the PCB back plane

> Buttons **0.70 mm**, microphones **0.50 mm** below the back plane.
> Open item **O-04**: the factory drawing and the reference enclosure disagree
> by about 2.5 mm here, and the resolution rests on a chain of three inferences.

With the board back-face down on a flat surface, measure to the **centreline**
of each side switch and of each microphone port. If these are wrong the buttons
miss their apertures in Z.

## 10 · Which switch is which

> Open item **O-03**. Three side switches; the design does not currently know
> which is PWR, which is BOOT and which is KEY.

Power the board and try them, or read the silkscreen. It changes no geometry —
the three apertures are identical — but it belongs in the assembly guide.

---

## Reporting

A photo of the calipers per reading is fine; so is a list. What matters is
**which of the ten**, and whether you measured the moulding or the keycaps in
§1. If any of §1, §2, §3 or §4 disagrees with the value quoted above, say so
before you start a full print — those four change geometry.

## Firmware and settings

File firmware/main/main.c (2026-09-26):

/*
 * cYbErDeCk OS - entry point.
 *
 * Steps 1-4 of the build order in docs/OS.md: display, text grid, BLE HID
 * keyboard, and a text buffer that survives power loss.
 *
 * The acceptance test is: power on, the keyboard connects by itself, type a
 * paragraph, pull the power, power on, the paragraph is still there.
 */
#include <stdio.h>
#include <string.h>

#include "driver/gpio.h"
#include "esp_heap_caps.h"
#include "esp_log.h"
#include "soc/rtc_cntl_reg.h"
#include "esp_system.h"
#include "esp_task_wdt.h"
#include "dinmidi.h"
#include "ensemble.h"
#include "vitals.h"
#include "view.h"
#include "ssh.h"
#include "esp_timer.h"
#include "freertos/FreeRTOS.h"
#include "freertos/task.h"
#include "nvs.h"
#include "nvs_flash.h"

#include "cmd.h"
#include "blemidi.h"
#include "seq.h"
#include "docstore.h"
#include "editor.h"
#include "ui_text.h"
#include "net.h"
#include "usbdev.h"
#include "viz.h"
#include "usbmux.h"
#include "kbd.h"
#include "selftest.h"
#include "battery.h"
#include "serialkbd.h"
#include "splash.h"
#include "st7305.h"
#include "testcard.h"
#include "textgrid.h"

static const char *TAG = "cyberdeck";

#define PIN_KEY        18
#define KEY_LONG_MS  2000        /* >= 180 ms thresholds, per the BLE caveat */
#define AUTOSAVE_MS  1000
/* A save costs a whole flash sector, and the idle timer alone fires once per
 * character for a slow typist - 128 characters cycles the entire partition.
 * A save is therefore also gated on enough having changed, unless a newline
 * or a long pause says the thought is finished. */
#define AUTOSAVE_MIN_CHARS  24
#define AUTOSAVE_IDLE_MS  6000
/* The cursor blinks while you are typing and for a while after, then goes
 * solid so the idle-LPM policy can fire. docs/OS.md bans blink outright for a
 * slow panel; the cost is not the 36 bytes a blink puts on the wire, it is
 * that an endless blink keeps the panel pinned in HPM. Bounding it keeps both
 * the affordance and the power behaviour. */
#define BLINK_MS       500
#define BLINK_WINDOW  15000
#define BUILD_ID (__DATE__ " " __TIME__)
#define NVS_NS "deck"

esp_err_t sdmirror_init(void);

static void report_memory(const char *when)
{
    ESP_LOGI(TAG, "%s: internal free %u B, largest %u B, PSRAM free %u B", when,
             (unsigned)heap_caps_get_free_size(MALLOC_CAP_INTERNAL),
             (unsigned)heap_caps_get_largest_free_block(MALLOC_CAP_INTERNAL),
             (unsigned)heap_caps_get_free_size(MALLOC_CAP_SPIRAM));
}

static void orient_save(uint8_t v);

/* The shipped default, used only when nothing has been chosen yet. An
 * orientation the owner set by hand is ALWAYS honoured - a stored value is
 * evidence about the physical build, which is knowledge this firmware does
 * not have and must not overwrite. */
#define ORIENT_DEFAULT  ST7305_ORIENT_3

static uint8_t orient_load(void)
{
    nvs_handle_t h;
    uint8_t v = ORIENT_DEFAULT;
    bool stored = false;

    if (nvs_open(NVS_NS, NVS_READONLY, &h) == ESP_OK) {
        stored = nvs_get_u8(h, "orient", &v) == ESP_OK;
        nvs_close(h);
    }
    if (v > 3) {
        v = ORIENT_DEFAULT;
        stored = false;
    }
    ESP_LOGI(TAG, "orientation %d (%s)", v,
             stored ? "chosen on this device" : "shipped default");
    if (!stored) {
        orient_save(v);
    }
    return v;
}

static void orient_save(uint8_t v)
{
    nvs_handle_t h;
    if (nvs_open(NVS_NS, NVS_READWRITE, &h) == ESP_OK) {
        nvs_set_u8(h, "orient", v);
        nvs_commit(h);
        nvs_close(h);
    }
}

/* WHAT A CELL COSTS TO DRAW, with nothing else running - both ways, in the
 * same boot, so the before and the after are one board's numbers. The editor's
 * heartbeat reports render time by the wall clock, which counts every
 * preemption by the radio and the keyboard scan as drawing; this holds the
 * scheduler. A full grid of mixed glyphs, a third of them inverted, drawn into
 * the framebuffer (no panel push). */
static void bench_render(void)
{
    const int cols = tg_cols(), rows = tg_rows();
    for (int r = 0; r < rows; r++) {
        for (int c = 0; c < cols; c++) {
            tg_put(c, r, (char)(32 + (r * cols + c) % 124),
                   ((c + r) % 3 == 0) ? TG_INVERSE : TG_NORMAL);
        }
    }
    const int runs = 4;
    int64_t per[2] = { 0, 0 }, first = 0;
    int cells = 0;
    for (int turned = 0; turned < 2; turned++) {
        tg_set_turned(turned != 0);
        vTaskSuspendAll();
        /* The first turned frame turns every glyph it meets, once. */
        int64_t t0 = esp_timer_get_time();
        tg_invalidate();
        cells = tg_render();
        if (turned) {
            first = esp_timer_get_time() - t0;
        }
        t0 = esp_timer_get_time();
        for (int i = 0; i < runs; i++) {
            tg_invalidate();
            tg_render();
        }
        per[turned] = (esp_timer_get_time() - t0) * 1000 / (runs * cells);
        xTaskResumeAll();
    }
    /* and what damage bookkeeping alone costs a cell, which the turned path
     * still pays in full */
    vTaskSuspendAll();
    const int64_t t2 = esp_timer_get_time();
    for (int i = 0; i < runs; i++) {
        for (int r = 0; r < rows; r++) {
            for (int c = 0; c < cols; c++) {
                st7305_damage(20 + c * 12, 12 + r * 24, 12, 24);
            }
        }
    }
    const int64_t dmg = (esp_timer_get_time() - t2) * 1000 / (runs * cells);
    xTaskResumeAll();
    ESP_LOGI(TAG, "BENCH cell render: per-row %lld ns, turned %lld ns a cell "
             "(%d cells, scheduler held)", per[0], per[1], cells);
    ESP_LOGI(TAG, "BENCH   first turned frame %lld us, damage %lld ns a cell",
             first, dmg);
    tg_clear();
}

static void bench(void)
{
    const int runs = 20;
    int64_t t0 = esp_timer_get_time();
    for (int i = 0; i < runs; i++) {
        st7305_flush_full();
    }
    ESP_LOGI(TAG, "BENCH full frame: %lld us (%d B)",
             (esp_timer_get_time() - t0) / runs, ST7305_FB_SIZE);
}

/* The destinations. Each is a function and a name the player can type; none
 * of them is privileged and none is compiled in as "the" output.
 *
 * 'mon' was a rate limit - the first 64 note-ons went to the console and the
 * rest were dropped, silently, forever. That is fine for proving the thing
 * boots and useless the moment you want to check what you are actually
 * sending, which is the second thing anyone wants. It is a destination now,
 * off by default, and it can be turned on for as long as it is wanted. */
/* '>flash' needs the panel to say so before the chip goes away. The editor
 * owns the status line and the draw, so the app is the only layer that can
 * do this - which is why cmd takes it as a hook. */
static void announce(const char *line)
{
    editor_message(line);
    editor_draw();
    st7305_flush(NULL);
}

static void dest_ble(const char *lane, uint8_t status, uint8_t d1, uint8_t d2,
                     uint32_t when_us)
{
    (void)lane;
    blemidi_send(status, d1, d2, when_us);
}

static void dest_usb(const char *lane, uint8_t status, uint8_t d1, uint8_t d2,
                     uint32_t when_us)
{
    (void)lane;
    /* USB MIDI carries no timestamp: the host renders on arrival, and a
     * full-speed frame is 1 ms wide. That is the whole reason USB is the
     * answer to jitter rather than a second way to have the same problem. */
    (void)when_us;
    usbdev_midi_send(status, d1, d2);
}

static void dest_mon(const char *lane, uint8_t status, uint8_t d1, uint8_t d2,
                     uint32_t when_us)
{
    /* Notes on AND off, and controllers, each with its lane and the moment the
     * clock decided it. Offs are here because a tie is a note that ends later,
     * and nothing else on the device can show how long a note was. Clock and
     * the step marker stay out: they are fifty messages a second and would bury
     * the thing the player is looking for. */
    const unsigned ms = (unsigned)(when_us / 1000u);
    const uint8_t kind = status & 0xF0;
    if (kind == 0x90 && d2 > 0) {
        ESP_LOGI("midi", "%-5s on  %3u v%-3u ch%-2u t%u", lane, d1, d2,
                 (status & 0x0F) + 1, ms);
    } else if (kind == 0x80 || (kind == 0x90 && d2 == 0)) {
        ESP_LOGI("midi", "%-5s off %3u      ch%-2u t%u", lane, d1,
                 (status & 0x0F) + 1, ms);
    } else if (kind == 0xB0 && d1 != 123) {
        ESP_LOGI("midi", "%-5s cc%-3u = %3u   ch%-2u t%u", lane, d1, d2,
                 (status & 0x0F) + 1, ms);
    }
}

/* THE DESTINATIONS THIS FIRMWARE REGISTERS. Counted here so the table cannot
 * be outgrown silently again: ble, mon, din, osc are unconditional and usb is
 * added when USB MIDI comes up. If a transport is added without room for it,
 * this fails the build instead of failing a performance. */
#define DECK_DESTS 5
_Static_assert(DECK_DESTS <= SEQ_MAX_DESTS,
               "more destinations than seq can hold - raise SEQ_MAX_DESTS");

static uint32_t s_boot_loops;
static bool     s_crashed_last_boot;

static int64_t now_ms(void) { return esp_timer_get_time() / 1000; }

/* The menu is a text file (docs/SUBSTRATE.md). If there is no guide yet,
 * write one - a device whose commands are undiscoverable has, in practice,
 * no commands. The owner can edit it like any other document, which is the
 * whole point: adding a menu item costs typing a line. */
/* Create the boot document if it is missing, then run it. */
static void run_boot_document(void)
{
    const int was = doc_buf_current();
    int idx = doc_buf_find("boot");
    if (idx < 0) {
        if (doc_buf_new() != ESP_OK) {
            return;
        }
        doc_set_text(BOOT_TEXT);
        doc_buf_set_kind(DOC_KIND_GUIDE);
        if (doc_buf_rename("boot") != ESP_OK) {
            doc_buf_select(was);
            return;
        }
        doc_save();
        idx = doc_buf_current();
        ESP_LOGI(TAG, "wrote a starter boot document");
    }
    if (doc_buf_select(idx) != ESP_OK) {
        doc_buf_select(was);
        return;
    }
    /* A BOOT DOCUMENT FROM BEFORE THE NAMES WERE LINES has no names in it, and
     * without them '>kick' means nothing. So the names go in at the TOP - they
     * must exist before any lane line below them runs - and everything the owner
     * wrote stays exactly as it was, underneath. The mark is the first line of
     * the block; a document that has it is left alone. */
    {
        const size_t mlen = sizeof BOOT_MARK - 1;
        bool marked = false;
        for (size_t i = 0; i + mlen <= doc_len() && !marked; i++) {
            size_t j = 0;
            while (j < mlen && doc_at(i + j) == BOOT_MARK[j]) { j++; }
            marked = (j == mlen);
        }
        if (!marked) {
            doc_move_to(0);
            for (const char *q = BOOT_NAMES; *q != '\0'; q++) {
                doc_insert(*q);
            }
            doc_save();
            ESP_LOGW(TAG, "boot document: the lane names were added at its top");
        }
    }
    char line[128];
    size_t k = 0;
    const size_t n = doc_len();
    int ran = 0;
    for (size_t i = 0; i <= n; i++) {
        const char ch = (i < n) ? doc_at(i) : '\n';
        if (ch == '\n' || k == sizeof line - 1) {
            line[k] = '\0';
            if (k > 0 && cmd_run_line(line, CMD_BY_GUIDE, NULL, 0) == CMD_DONE) {
                ran++;
            }
            k = 0;
            continue;
        }
        line[k++] = ch;
    }
    doc_buf_select(was);
    ESP_LOGI(TAG, "boot document: %d line(s) ran", ran);
}

static void ensure_guide_buffer(void)
{
    for (int i = 0; i < DOC_MAX_BUFFERS; i++) {
        if (strcmp(doc_buf_name(i), "guide") == 0) {
            /* A guide written before the sigil existed holds lines that will
             * never run again. Rewrite it once rather than leaving a menu
             * whose buttons silently do nothing. */
            const int was = doc_buf_current();
            if (doc_buf_select(i) != ESP_OK) {
                return;
            }
            /* Has this guide seen the music layer? '>play' is the marker.
             *
             * PREPEND, DO NOT REPLACE. The guide is the owner's menu - the
             * whole claim of docs/SUBSTRATE.md is that they write their own
             * interface - so firmware that overwrites it destroys exactly the
             * thing the design is for. The new track goes on top, where it is
             * read first, and whatever was there stays underneath. */
            bool has_play = false, has_mark = false;
            const size_t mlen = sizeof GUIDE_MARK - 1;
            for (size_t k = 0; k + 5 <= doc_len(); k++) {
                if (doc_at(k) == '>' && doc_at(k+1) == 'p' && doc_at(k+2) == 'l' &&
                    doc_at(k+3) == 'a' && doc_at(k+4) == 'y') {
                    has_play = true;
                }
                if (k + mlen <= doc_len()) {
                    size_t j = 0;
                    while (j < mlen && doc_at(k + j) == GUIDE_MARK[j]) { j++; }
                    if (j == mlen) { has_mark = true; }
                }
            }
            /* AND HAS IT SEEN THIS GRAMMAR? A guide from before docs/MANIFESTO.md
             * §3.6 teaches 'X...' and 'x,x?' - lines that are now refused - so it
             * gets the new text too, on top, with everything the owner wrote kept
             * underneath. */
            if (!has_play || !has_mark) {
                const size_t had = doc_len();
                char *keep = malloc(had + 1);
                if (keep != NULL) {
                    doc_read(keep, had);
                    keep[had] = '\0';
                }
                doc_set_text(GUIDE_TEXT);
                doc_move_to(doc_len());     /* append, not prepend */
                if (keep != NULL && had > 0) {
                    static const char sep[] = "\n-- previously in this guide --\n";
                    for (const char *q = sep; *q != '\0'; q++) { doc_insert(*q); }
                    for (const char *q = keep; *q != '\0'; q++) { doc_insert(*q); }
                }
                free(keep);
                doc_buf_set_kind(DOC_KIND_GUIDE);
                doc_save();
                ESP_LOGW(TAG, "guide updated; the old text is kept below it");
            }
            doc_buf_select(was);
            return;
        }
    }
    const int was = doc_buf_current();
    if (doc_buf_new() != ESP_OK) {
        return;
    }
    doc_set_text(GUIDE_TEXT);
    doc_buf_set_kind(DOC_KIND_GUIDE);
    if (doc_buf_rename("guide") == ESP_OK) {
        doc_save();
        ESP_LOGI(TAG, "wrote a starter guide buffer");
    }
    doc_buf_select(was);
}

int64_t editor_now_ms(void) { return now_ms(); }

/* The passkey arrives on the NimBLE host task. It is only RECORDED here; the
 * main task draws it on its next pass.
 *
 * Drawing it directly raced the main task over the text grid, the framebuffer
 * and the SPI bus - three pieces of shared state with no lock between them -
 * and would have produced a torn screen at exactly the moment the owner most
 * needs to read six digits correctly. */
static volatile uint32_t s_passkey;
static volatile bool     s_passkey_pending;

void kbd_on_passkey(uint32_t passkey)
{
    s_passkey = passkey;
    s_passkey_pending = true;
}

static void draw_passkey(uint32_t passkey)
{
    char line[32];
    snprintf(line, sizeof line, "%06u", (unsigned)passkey);

    tg_clear();
    tg_puts(1, 2, "PAIR THE KEYBOARD", TG_NORMAL);
    tg_fill(1, 4, 12, ' ', TG_INVERSE);
    tg_puts(4, 4, line, TG_INVERSE);
    tg_puts(1, 6, "Type that on the", TG_NORMAL);
    tg_puts(1, 7, "keyboard, then press", TG_NORMAL);
    tg_puts(1, 8, "Enter.", TG_NORMAL);
    tg_render();
    st7305_flush_full();
}
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

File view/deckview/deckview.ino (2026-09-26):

// deckview - the deck's picture on HDMI, from an Adafruit Feather RP2040 DVI.
//
// docs/NEXT.md §6: the visualization node. viz.c left the wire format unwritten
// "because a format invented before its reader is a format nobody implements";
// this is the reader, and docs/VIEW.md is the format.
//
// It draws the deck's own glyphs - deckfont.h is generated from the same art as
// the panel's faces (tools/make_font.py --view) - one bit per pixel, because the
// deck's picture is one ink and a screen that added colour would be showing
// something the performer never made. Each frame is drawn at the largest whole
// scale that fits 640x480, with whichever of the two faces fills it best, and
// centred: a cell is always a square block of the tile, never smeared.
//
// Frames arrive over USB serial. Today the deck's frames are relayed by a
// computer (tools/viewrelay.py); the same bytes are what the deck will send
// itself when it drives this board directly.
//
//   arduino-cli compile -b rp2040:rp2040:adafruit_feather_dvi view/deckview
//   arduino-cli upload  -b rp2040:rp2040:adafruit_feather_dvi -p <port> view/deckview

#include <PicoDVI.h>
#include "deckfont.h"

DVIGFX1 display(DVI_RES_640x480p60, true, adafruit_feather_dvi_cfg);

#define SCREEN_W 640
#define SCREEN_H 480
#define ROW_BYTES (SCREEN_W / 8)

// ---- the wire format: docs/VIEW.md, read by view_read.h ------------------
#include "view_read.h"
static view_reader_t s_rd;

// ---- drawing ------------------------------------------------------------

static inline void set_run(uint8_t *row, int x, int n)
{
  for (int i = 0; i < n; i++, x++) {
    row[x >> 3] |= (uint8_t)(0x80 >> (x & 7));
  }
}

// One frame of cells into the back buffer, in face `big` (12x24) or not
// (6x12), `s` screen pixels to a glyph pixel, top-left at (x0, y0).
static void draw_cells(const uint8_t *cells, int w, int h, bool big, int s,
                       int x0, int y0)
{
  uint8_t *fb = display.getBuffer();
  const int fw = big ? 12 : 6, fh = big ? 24 : 12;
  for (int cy = 0; cy < h; cy++) {
    for (int gr = 0; gr < fh; gr++) {
      for (int sy = 0; sy < s; sy++) {
        const int y = y0 + (cy * fh + gr) * s + sy;
        if (y < 0 || y >= SCREEN_H) continue;
        uint8_t *row = fb + y * ROW_BYTES;
        for (int cx = 0; cx < w; cx++) {
          int code = cells[cy * w + cx];
          if (code < DECKFONT_FIRST || code > DECKFONT_LAST) code = ' ';
          const int g = code - DECKFONT_FIRST;
          uint16_t bits;
          if (big) {
            bits = (uint16_t)((deckfont_12x24[(g * 24 + gr) * 2] << 8) |
                              deckfont_12x24[(g * 24 + gr) * 2 + 1]);
          } else {
            bits = (uint16_t)(deckfont_6x12[g * 12 + gr] << 8);
          }
          if (bits == 0) continue;
          const int xb = x0 + cx * fw * s;
          for (int gc = 0; gc < fw; gc++) {
            if (bits & (0x8000 >> gc)) {
              const int x = xb + gc * s;
              if (x >= 0 && x + s <= SCREEN_W) set_run(row, x, s);
            }
          }
        }
      }
    }
  }
}

// THE LARGEST WHOLE SCALE THAT FITS, of either face. Whole, because a cell is
// a tile and a tile scaled by 1.7 is not the tile any more; either face,
// because a small frame at the big face's scale 1 wastes most of the screen
// that the small face at scale 3 fills.
static void layout(int w, int h, bool *big, int *s)
{
  int best = 0;
  *big = true;
  *s = 1;
  for (int f = 0; f < 2; f++) {
    const int fw = f == 0 ? 12 : 6, fh = f == 0 ? 24 : 12;
    for (int k = 8; k >= 1; k--) {
      if (w * fw * k <= SCREEN_W && h * fh * k <= SCREEN_H) {
        const int area = w * fw * k * h * fh * k;
        if (area > best) { best = area; *big = (f == 0); *s = k; }
        break;
      }
    }
  }
}

static void show_frame(const uint8_t *cells, int w, int h)
{
  memset(display.getBuffer(), 0, ROW_BYTES * SCREEN_H);
  bool big;
  int s;
  layout(w, h, &big, &s);
  const int fw = big ? 12 : 6, fh = big ? 24 : 12;
  const int x0 = (SCREEN_W - w * fw * s) / 2;
  const int y0 = (SCREEN_H - h * fh * s) / 2;
  draw_cells(cells, w, h, big, s, x0, y0);
  display.swap();
}

// Before the first frame, say what this is and what it is waiting for, in the
// deck's own face - a black screen is indistinguishable from a broken one.
static void show_waiting(void)
{
  static const char *lines[] = { "cYbErDeCk view", "", "waiting for", "the deck" };
  static uint8_t cells[4 * 16];
  memset(cells, ' ', sizeof cells);
  for (int r = 0; r < 4; r++) {
    for (int c = 0; lines[r][c] && c < 16; c++) cells[r * 16 + c] = lines[r][c];
  }
  show_frame(cells, 16, 4);
}

void setup()
{
  Serial.begin(115200);
  if (!display.begin()) {
    pinMode(LED_BUILTIN, OUTPUT);
    for (;;) digitalWrite(LED_BUILTIN, (millis() / 500) & 1);
  }
  show_waiting();
}

void loop()
{
  // Drain what USB has, in one go, so a large frame is not held up behind the
  // per-byte overhead of Serial.read().
  static uint8_t buf[512];
  int n = Serial.available();
  while (n > 0) {
    const int k = Serial.readBytes(buf, n > (int)sizeof buf ? (int)sizeof buf : n);
    for (int i = 0; i < k; i++) {
      if (view_read_byte(&s_rd, buf[i])) show_frame(s_rd.cells, s_rd.w, s_rd.h);
    }
    n = Serial.available();
  }
  // A one-line account every two seconds, for whoever is listening: frames
  // drawn, frames refused, and the last tick - which is how the far end knows
  // this node is showing the picture it sent and when it belonged.
  static uint32_t last;
  if (millis() - last > 2000) {
    last = millis();
    Serial.printf("view: %lu frames, %lu refused, tick %lu, %ux%u\r\n",
                  (unsigned long)s_rd.frames, (unsigned long)s_rd.refused,
                  (unsigned long)s_rd.tick, s_rd.w, s_rd.h);
  }
}

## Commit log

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2026-09-19 cad: parametric single-form chassis, back plate and button sprue
    Architecture: a monocoque chassis (entire front face, all four walls and the
    inter-bay spine as one continuous body) closed by a structural back plate. The
    reference design this project measures uses a bezel screwed onto a tray, which
    puts a joint across the largest face in the plane where drop-induced bending is
    highest. Moving the joint to the back makes the shell a closed section and lets
    the full-depth spine act as a shear web across the middle.
    Envelope 116.6 x 140.2 x 18.6 mm, against the reference's 151.65 x 116.77 x
    18.00 mm: 11.45 mm shorter and 0.17 mm narrower, at 3.2 mm walls rather than
    2.9 mm. tools/validate.py a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
    [cyberdeck.scad, parameters.scad]
2026-09-19 cad: rebuild the board datum set from Waveshare's own CAD package
    Waveshare publishes a 3D package for this board - Creo STEP assembly,
    dimensioned DXF and dimensioned PDF - at
    files.waveshare.com/wiki/ESP32-S3-RLCD-4.2/ESP32-S3-RLCD-4.2-3dFile.rar.
    Every board dimension is now read from it rather than inferred, which corrects
    four datums that were wrong or imprecise:
    - The PCB is 92.50 x 69.10 x 1.60, not 92.5 x 70.1. The widely-repeated
    "92.5 x 70.1 x 13.5" conflates three objects: 92.50 is the PCB length,
    70.10 is the REMOVABLE moulded stand base (which overhangs the PCB by
    exactly 1.00 mm on one long edge), and 13.50 is a stack that excludes the
    battery holder entirely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
    [cyberdeck.scad, parameters.scad]
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2026-09-19 cad: restore the acrylic window parameters; make undefined identifiers fatal
    The window's four parameters were lost when section 1 of parameters.scad was
    rewritten around the Waveshare CAD data. OpenSCAD does not stop for that: it
    substitutes undef, warns on stderr, and rbox() falls back to a unit cylinder.
    The part rendered as a 2 x 2 x 1 mm solid and passed all 52 checks, because
    every check looked at the datums rather than at the part.
    Three fixes, in increasing order of importance:
    1. window_w/h/t/corner_r restored, with the DXF provenance they carry.
    2. validate.py now asserts each rendered part's extents against what the
    parameters say they should be, and that no part is degenerat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
    [cyberdeck.scad, parameters.scad]
2026-09-19 cad: rework the form language - continuous curvature, Rams read organically
    Every visible corner becomes a superelliptical quadrant instead of a circular
    arc. A fillet is an arc tangent to a line: position and tangent match at the
    join, curvature does not - it jumps from 1/r to zero, and the eye reads that as
    a hard corner however large the radius. At n=3.2 with a corner size of 11.2 the
    curve tracks an R8 arc to within 0.2 mm, so the silhouette is unchanged, but the
    corner now runs 11.2 mm along each edge with curvature ramping in from zero.
    A pure Lame curve over the whole outline was tried first and is wrong at this
    scale: it cuts ~10 mm off each corner, eats the wall, and loses the stra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
    [cyberdeck.scad, parameters.scad]
2026-09-19 tools: dimensioned GA drawings, component-facing accuracy audit, assembly renders
    Three additions, all of which are gates or documents rather than pictures.
    tools/drawing.py produces four dimensioned general-arrangement sheets. Every
    dimension on them is MEASURED FROM THE RENDERED MESH rather than typed in or
    read from parameters.scad: a drawing annotated by hand drifts from the model the
    first time anyone edits the model, one that measures the mesh cannot. Sheet 1
    prints the envelope derivation with a PASS/FAIL line per axis; sheet 3 sections
    both bays with the components in place and calls out the clearance per side.
    Writing it caught three defects in its own first output, worth recordin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
    [cyberdeck.scad]
2026-09-19 Correct the keyboard datum to the FCC-filed manual and fit to the worst case
    The Rii 518BT outline had been carried as the vendor's inch figure rounded to
    0.1 in, i.e. a +/-2.54 mm band. The manufacturer's own user manual, filed as
    the User Manual exhibit of FCC ID YIZRT-RII518, states it outright on page 13:
    108.5 x 58.2 x 10.2 mm, 75 g.
    It had been missed because the manual's text is converted to vector outlines
    (the PDF title contains the Chinese for "convert to curves"), so pdftotext
    returns only FCC boilerplate and the specification table is invisible to any
    full-text search. It appears only when the page is rasterised.
    Two consequences, and the second is the one that mattered:
    - W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
    [cyberdeck.scad, parameters.scad]
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2026-09-19 Build the published views from the exported STLs, not the CSG source
    The renders had striping across both apertures and a torn diagonal sliver
    where the screen should be. Neither was a geometry fault - the exported STLs
    were correct throughout - and chasing it through the model would have been
    chasing a rendering artefact.
    Two separate causes, both worth recording because both produce a wrong picture
    of a right model:
    - OpenSCAD's OpenCSG preview depth-peels a bounded number of CSG layers. The
    chassis is a deep difference tree - shell, two flared apertures, port
    tunnels, bosses, grille, groove - and past that bound the previewer stripes
    surfaces it cannot resolve. Raising the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
    [cyberdeck.scad, render_assembly.scad]
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2026-09-19 Delete the phantom keyboard body; the manufacturer's drawing settles the outline
    An exhaustive source hunt turned up Riitek's own dimensioned product drawing,
    which prints BOTH units on every axis in one string per dimension:
    108.5mm/4.3inch 58.2mm/2.3inch 10.2mm/0.4inch
    That fixes the direction of the conversion, and it demolishes a datum this
    project introduced earlier the same day.
    Until now the file carried two rival bodies: the drawing/manual figure
    108.5 x 58.2 x 10.2, and a "current retail" body at 109.22 x 58.42 x 10.16 read
    off riitek.com's 4.3 x 2.3 x 0.4 in, on the theory that the vendor might have
    revised the unit without republishing dimensions. Fit mocks were bui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
    [parameters.scad]
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2026-09-19 Fix an argument-shift bug that squared off both apertures, and delete the orphan window
    Two defects, both found by eye in a render after being committed, published and
    shipped as STLs. That is the part worth recording, because this repository's
    whole argument is that numerical gating beats inspection.
    THE APERTURES WERE NEARLY SQUARE-CORNERED
    rse_aperture() called
    rse_plate(w + 2*flare, h + 2*flare, cr + flare, n, q)
    into a module declared (w, h, t, cr, n, q = 16). The thickness argument was
    missing, so every argument after the second shifted left: cr+flare landed in
    `t`, n landed in `cr`, q landed in `n`, and q fell back to its default. The top
    plate of the loft was extruded 10.8 mm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
    [backplate.stl, buttons.stl, chassis.stl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]
2026-09-19 Unseal the controls, and correct a corner radius I measured wrong
    Three findings, one of them the worst defect in the project so far. All were
    found by looking at the part rather than at a number.
    EVERY SIDE BUTTON AND BOTH MICROPHONES WERE SEALED INSIDE THE WALL
    The chassis had NO opening for the three side buttons or the two microphones,
    and the control dish removed no material at all. Sixty-four checks passed.
    Two independent orientation faults:
    - rbox() extrudes from z = 0 to +t, NOT centred on z = 0. After
    rotate([90,0,0]) that runs inward from the translate point, so starting at
    top_wall_y - wall/2 reached the inner face at y = 66.35 and stopped
    1.60 mm short of the o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
    [backplate.stl, buttons.stl, chassis.stl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]
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2026-09-19 Measured hardware, a 24-agent re-derivation, and two blocking fixes
    The owner put calipers on a real board and a full re-derivation went back to
    Waveshare's DXF and STEP, the Riitek drawing, the FCC exhibits and the
    reference meshes: 212 findings, 50 disputed, 14 upheld after adversarial
    refutation. Recorded as C-12 through C-20.
    FROM THE HARDWARE
    glass front -> standoff back measures 11.00, not the 10.75 the vendor CAD
    implies. That 0.25 IS the gasket squeeze, so taking the CAD figure would
    have seated the display hard against the front panel with no compliance.
    board_stack is now [MEASURED] 11.00 and board_depth 11.25; the deck goes
    16.60 -> 16.85 mm.
    PCB measures 92.7 x 69.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
    [backplate.stl, buttons.stl, chassis.stl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]
2026-09-19 Close the hanging items, and fix a section tool that returned a negative I
    STRUCTURE.PY WAS RETURNING A NEGATIVE SECOND MOMENT
    min Z read -1,629 mm^3. A negative second moment is not a small error, it is
    proof the summation is wrong, and every structural figure in the README and
    DESIGN.md came from this tool.
    The cause: section_props() took abs() of the signed moment totals. That works
    for a single solid ring and silently corrupts anything with holes or several
    disjoint regions. It went unnoticed until the button and microphone apertures
    were cut, which made the top-wall stations multi-region for the first time.
    Rings are now explicitly oriented - exterior CCW, interiors CW - so the signe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
    [backplate.stl, buttons.stl, chassis.stl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]
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2026-09-19 Make the buttons work and stop the keyboard sliding
    Three pre-print defects, all in geometry no check interrogated.
    BUTTONS — the sprue could not be installed, then could not reach.
    The board's top edge sits 0.50 mm inside the top wall's inner face and
    the switch actuator 0.69 mm, so a flange behind the wall and a plunger
    that reaches the switch cannot both live there. Cut back to a bare
    flange it fitted and fell 0.34 mm short of ever touching a switch.
    The flange now sits IN the wall, in a 1.00 mm counterbore -- one
    continuous slot so the sprue's webs recess with it -- which leaves the
    0.50 mm for the plunger and buys 0.60 mm of free travel from the wall's
    own thickness. The plunger is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
    [_echo_tmp.scad, backplate.stl, buttons.stl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]
2026-09-19 Freeze v1 so v2 cannot move it without saying so
    v2 adds a magnetic front cover and will share this codebase, because forking
    5,561 lines guarantees the two drift and every future fix has to be made
    twice. The cost of sharing is that a v2 edit can silently move v1 geometry,
    and v1 is a design that is about to be printed.
    A git tag cannot detect that -- it records where v1 was, not whether v1 still
    reproduces. (The remote also refuses tag refs in this environment; branch
    pushes work, tag pushes are rejected outright.) So the freeze goes in the
    repo instead:
    tests/golden/v1.json 217 scalars, 2 vectors and the three parts'
    extents, volumes, watertightness and body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
    [_echo_tmp.scad]
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2026-09-20 Fix a slit into the battery cavity that C-25's own fix opened -- BLOCKING
    C-25 pulled the battery cowl off two M2.5 screw countersinks by opening its
    outer plan corner from 6.0 to 12.6. A fuller outer corner draws the surface
    IN at 45 degrees while the cavity's near-square R2.2 corner stays put, so the
    wall between them went from 2.07 mm on the flats to 0.0385 mm at the corner
    -- an open slit into the 18650 cavity, about 0.6 mm of arc by 3.8 mm tall,
    on all four corners. The part was watertight and a single body, so nothing
    downstream objected.
    THIS SHIPPED. It is in v1.0 (6a9ded1) and in the STLs issued from it.
    WHY NOTHING CAUGHT IT. Four assertions guard this cowl. Three are horizontal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
    [backplate.stl, buttons.stl, chassis.stl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]
2026-09-20 Clear the remaining upheld findings from the pre-print audit
    Five more defects from the 19-agent audit, each verified here before it was
    touched. 111 checks, was 106.
    C-31 COUNTERSINK BREAKOUT -- BLOCKING. The upper shell-screw countersinks sat
    at plate_half_h - head/2 - margin. plate_half_h is the plate's MID-THICKNESS
    section and the outer face is rolled in from it; worse, boss_cx = 51.24 lands
    inside the face's corner blend, where the outline runs diagonally and a
    vertical extent is not a clearance. The Ø4.0 head had 0.022 mm of plate to
    bite on and opened a notch in the rim at both top corners.
    Measuring the "highest usable y" on the rendered plate returns 58.5 -- which
    then collides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
    [backplate.stl, buttons.stl, chassis.stl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]
2026-09-20 Fix the three faults the first print found
    PRINTED-PART FEEDBACK, all three confirmed by measurement before any change.
    1. THE NOZZLE WAS WRONG IN THE MODEL. This prints on a 0.8 mm nozzle and
    `nozzle` said 0.4 -- not a slicer setting, a definition of "thin". Against a
    floor of two beads (1.60 mm):
    tongue groove, outboard wall 0.96 -> 2.14
    speaker grille webs 1.11 -> 2.83
    microphone slot 5.4 x 2.5 -> 8.0 x 3.2
    The groove could not be fixed by depth or by the roll: at wall = 3.2 the edge
    roll withdraws the outer face by 0.94 mm exactly where the groove sits, so the
    wall itself was the variable. bottom_wall = wall + 1.2.
    That in turn means the back openin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
    [backplate.stl, buttons.stl, chassis.stl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]
2026-09-20 Record why the microphone slot differs from the reference
    CI was red on all four branches. The reference audit reported two rows "to
    review" -- the microphone aperture, 5.4 x 2.5 -> 8.0 x 3.2 -- and that gate
    fails the build by design: a component-facing dimension that differs from a
    design known to work, with no recorded reason, is exactly what it exists to
    stop.
    The gate was right and the geometry is not the problem. The enlargement is
    deliberate: the reference is a 0.4-nozzle part, and at 0.8 the roof of a
    2.5 mm slot is a single bridged bead that needs support inside a 3.2 mm
    tunnel. What was missing was the reason, which is what the INTENDED mechanism
    is for. Both rows now carry it.
    1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
    [backplate.stl, chassis.stl]
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2026-09-20 Widen the magnet crush ribs so the slicer can actually print them
    C-35. Eight ribs, 0.35 mm tall, cut into the magnet bore so the discs grip
    across their own 0.20 mm tolerance band. The heights were right, the
    interference arithmetic was right, and the ribs could not be printed.
    The rib was formed by subtracting a cylinder of radius magnet_rib_h centred ON
    the bore wall, which leaves a bump exactly 2 * magnet_rib_h wide at its base -
    0.70 mm. Against the 0.80 mm nozzle this design was re-derived for in C-33,
    that is 0.87 of a single extrusion. A feature narrower than one bead is not a
    feature; the slicer renders it as whatever the bead happens to do there. None
    of the designed 0.10-0.30 mm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
    [cyberdeck.scad, parameters.scad]
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2026-09-20 A real layout, a bounded blinking cursor, and the reason the keyboard types nothing
    Three complaints from the enclosure, and one of them is a genuine bug rather
    than a matter of taste.
    The keyboard first, because it is the functional one. NimBLE allows exactly
    one GATT procedure in flight per connection, and descriptor discovery was
    being started from inside the characteristic-discovery callback - the obvious
    way to write it, and wrong. The nested call fails with BLE_HS_EBUSY, the CCCD
    is never written, and the result is a keyboard that pairs, connects, reports a
    healthy link and then types absolutely nothing. That matches the symptom
    exactly. Discovery is now a sequential state machine whe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
    [main.c]
2026-09-20 Two GATT bugs, and never overwrite a setting the owner made by hand
    The keyboard now pairs, bonds, encrypts, discovers the HID service and
    subscribes to its reports. Two bugs were in the way and both are the kind that
    leave a link looking perfectly healthy.
    The first was the nested GATT procedure fixed in the previous commit. The
    second only became visible once the first was gone: descriptor discovery
    reports a CCCD and THEN reports completion, and both paths were advancing the
    subscription index. Every characteristic that actually had a CCCD advanced
    twice, so the walk ran off the end of the list - "subscribed to report 7 of 5"
    - while real reports were skipped entirely. Exactly one path a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
    [main.c]
2026-09-20 The keyboard types: a stale bond, not the authentication theory
    Keystrokes arrive, decode and land in the document. Reports come in on handle
    36 as eight-byte report-protocol input reports, and "the quick brown f..."
    typed on the Rii appears in the journal at 177 bytes.
    Three faults stood between a healthy-looking link and a single character, and
    the one that looked most likely was not the one that mattered.
    The first two are in the previous commits: descriptor discovery started from
    inside the characteristic-discovery callback and failed with EBUSY so no CCCD
    was ever written, and the subscription walk advanced its index from two places
    so characteristics with a CCCD were counted twice an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
    [main.c]
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2026-09-20 Undo, real navigation, modifiers, and a queue that was eating keystrokes
    Step 4 of docs/OS.md asked for a gap buffer AND undo; only the buffer existed.
    A writing device whose whole promise is "never lose an idea" could not take
    back a word.
    Undo is an operation log, not a snapshot ring. Snapshots are the obvious
    design and the wrong one at this size: the document is up to 128 KB and a
    useful ring would cost megabytes on a part with 512 KB of internal SRAM. The
    log costs a few bytes an edit. Runs coalesce so undo moves by words - verified
    on hardware, typing "alpha beta gamma" and undoing gives back "gamma", then
    "beta ", then "alpha ", and redo replaces them in order. Whitespace closes a
    ru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
    [main.c]
2026-09-20 Fix every finding the audit confirmed, starting with one the owner reported
    Five reviewers went through the tree by subsystem and each finding was put to
    two adversarial verifiers told to refute by default. Nineteen survived. All
    nineteen are fixed here.
    The most important one had been reported by the owner in three words -
    "isn't reacting" - and was misdiagnosed as a keyboard problem.
    The editor never reached the panel. editor_draw() called tg_render(), which
    draws the dirty cells and CLEARS the dirty bits; main then called tg_flush(),
    which renders again, sees nothing dirty, and concludes there is nothing to
    push. Every edit was drawn correctly into the framebuffer and never clocked
    out.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
    [main.c, st7305.c]
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2026-09-20 Buffers, an archive, and a command table whose shape is the point
    The document singleton is gone, and with it the reason four things the deck
    needs could not exist: an archive listing beside the file it opens, a scratch
    buffer beside a named one, a command's output sink, and later one session
    buffer per remote host. They are all the same primitive.
    THE SAVE MODEL is scratch by default, save promotes, which the owner chose and
    which is the right way round. Every buffer is journalled and crash-safe from
    the first keystroke, named or not; naming is what FILES a document in the
    archive, not what makes it durable. So "I did not want to save this" never
    costs data, the archive only holds things d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
    [builtins.c, main.c]
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2026-09-20 Enter always makes a line, and a command is marked with >
    Three interaction faults, and the first one made the guide uneditable.
    Enter ran the line in a guide buffer, which is what docs/SUBSTRATE.md
    describes - and it meant standing at the end of a command with no way to add
    a line after it, because the key that adds lines was busy running things. An
    editor whose Enter key sometimes does not insert a line is not an editor. The
    owner found it within minutes of using it, which is the correct outcome for a
    design decision that had never been sat in front of.
    Enter now always inserts, everywhere. Ctrl+Enter is the Run verb, everywhere.
    The buffer kind no longer decides it.
    That is possible be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
    [builtins.c, main.c]
2026-09-20 The status line and the render path were one bug; the fix is a deletion
    Measured, before and after, on the hardware:
    before 1,272 bytes per keystroke, render never measured
    after 73 bytes per keystroke, 194 us of CPU per cell
    The status line was chrome painted beside the grid rather than part of it. It
    carried the cursor column, so its string changed on nearly every key, and
    repainting it meant filling a full-width band and blitting two dozen glyphs
    through per-pixel coordinate transforms - roughly seventeen thousand of them
    and some seven and a half thousand damage insertions, per keystroke. Moving it
    onto the grid as row 10 of a 30x11 layout lets tg_put's existing change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
    [builtins.c, main.c, st7305.c]
2026-09-20 A density command, because both faces were already in the binary
    The 6x12 face has been compiled in since the first night and nothing could
    reach it. Switching to it gives 60x24 instead of 30x11 - 1,440 character cells
    against 330 - and it is CHEAPER to draw, not more expensive: a 6x12 cell is
    nine bytes on the wire against thirty-six, measured at seventeen bytes per
    keystroke dense against seventy-three chunky.
    That is the right way round. The readable default is the expensive one, and
    the density that fits a listing on one screen costs less.
    It exists because "help" being unreadable was a geometry problem wearing a
    plumbing problem's clothes. Ten commands do not fit in ten rows beside th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
    [builtins.c]
2026-09-20 The journal was destroying documents to make room, and STATUS.md said it was safe
    Four live data-loss defects, found by an audit that read the firmware rather
    than the documents. Every one of them is mine and three were shipped.
    THE JOURNAL WRAPPED. It kept a write cursor and reset it to zero on reaching
    the end. Sector 0 holds whichever document was written first, which on this
    device is the guide - the live-coding preset file the brief asks for by name.
    Saving anything else eventually erased it. Silently, at runtime, with no error
    raised anywhere. And STATUS.md asserted the opposite in as many words: "128
    slots wrap safely... nothing is at risk". A repository that publishes a false
    reassu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
    [partitions.csv]
2026-09-20 A sequencer of lanes, because the output is not on this screen
    ORCA is reconsidered and the reason is sharper than "esoteric". ORCA puts the
    program, the performance and the display on ONE surface, and that is what
    earns its two-dimensional layout - you watch bangs propagate and that IS the
    piece. This device's output is somewhere else: a synth over MIDI, lights over
    OSC, a Pi driving a projector. The spatial payoff lands on a different
    machine, so all that is left of a matrix here is its cost - constant 2D cursor
    movement on a thumb keyboard, which is the input this hardware is worst at.
    Paying ORCA's price for a benefit delivered elsewhere is the category error.
    So: lanes. One line per pa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
    [builtins.c, main.c, seq.c]
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

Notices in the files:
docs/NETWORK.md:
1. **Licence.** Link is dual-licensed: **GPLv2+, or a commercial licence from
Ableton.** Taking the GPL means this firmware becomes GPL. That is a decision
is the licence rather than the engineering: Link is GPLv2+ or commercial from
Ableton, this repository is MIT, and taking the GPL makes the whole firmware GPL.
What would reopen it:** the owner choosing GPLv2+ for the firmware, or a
